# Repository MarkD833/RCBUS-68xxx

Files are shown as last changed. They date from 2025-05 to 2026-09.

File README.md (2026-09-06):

# RCBus Motorola 68xxx Project(s)

This repository is my attempt at introducing some of the Motorola MC68000 (and family) devices into the RCBus ecosystem. 

The image below is of my first RCBus-80 MC68000 system, comprising an MC68000 CPU board (RC101), ROM/RAM board (RC102) and quad serial board (RC103) all plugged into one of Steve Cousin's [SC701](https://smallcomputercentral.com/rcbus/sc700-series/sc701-rcbus-backplane/) backplanes.

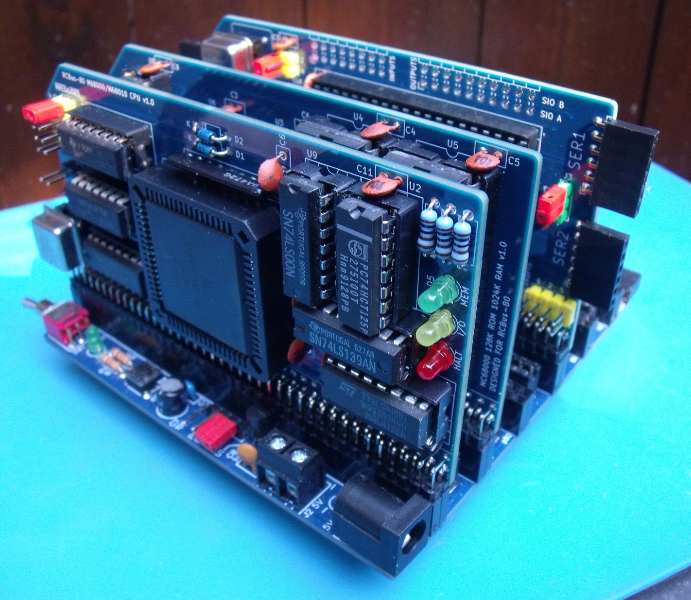
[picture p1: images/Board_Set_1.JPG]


**CAUTION:** This is my hobby project and I have no formal training in hardware design. What works for me may be simply down to the logic device series that I happen to have in my stash. There could be some real gotchas here that have yet to reveal themselves.

# Table of contents
- [The RCBus](#the-rcbus)
- [Zilog Compatability](#zilog-compatability)
- [DTACK](#dtack)
- [The Boards](#the-boards)
- [Address Map](#address-map)
- [RCBus Compatability](#rcbus-compatability)
- [Software Development](#software-development)
- [Hardware Library](#hardware-library)
- [Component Sourcing](#component-sourcing)

# The RCBus
RCBus is an extended version of the [RC2014&trade;](https://rc2014.co.uk/) bus that was put together by members of the [retro-comp](https://groups.google.com/g/retro-comp) google group. The latest RCBus specification as of Oct 2025 is v1.0 and can be found [here](https://smallcomputercentral.com/rcbus/).

My boards are designed around the RCBus 80 pin format in order to support the additional address and data signals to support the MC68000 family of devices.

# Zilog Compatability
There is no intention to support any Zilog family of chips such as the PIO, SIO, CTC or KIO as their signals and timing are just too different. The PIO and SIO have equivalents in the MC68230 and MC68681 chips. The KIO has a sort-of equivalent in the MC68901, but note that the single UART in the MC68901 is quite limited in terms of baud rate. A CTC chip may not be needed as the MC68230 and MC68681 each have a built-in timer and the MC68901 has 4 simple timers.

# DTACK
A common design choice when putting together a 68000 based system is to ground the /DTACK (Data Transfer Acknowledge) pin on the processor. With this design choice, there will not be a BUS ERROR exception.

Whilst this simplifies the design, I personally prefer to try and implement a simple /DTACK.

For my memory boards, I generate a /DTACK signal directly from the chip select signal and for the RCBus IO and Memory spaces I have a simple delay before generating a /DTACK on the processor card itself. Boards that use devices that are 68000 compatible (MC68681 or MC68230 for example) generate their own /DTACK internally. 

# The Boards
The boards below are my current suite of MC68xxx processors and peripherals. I have re-organised and re-named the boards in order to more easily identify them.

The board dimensions should be the size of an RCBus "medium" module as detailed in the RCBus specification v1.0 - roughly 4in x 2.1in excluding the edge connector. A lot of the boards are 4-layer boards with +5V and GND on the inner 2 layers, mainly in order to squeeze in all the chips into the small board space.

There are more details of each board in their respective boards folder.

There are currently 2 series of board. The series 1 boards I've give the names RC1xx to and the series 2 boards I've given the names RC2xx to.

## Series 1 Boards
These boards are based around my intial experimentation with an MC68000 ecosystem. The processor boards all use autovectored interrupts and the various I/O boards don't support any form of interrupt acknowledge sequence. These boards were a bit of a designing frenzy with not too much thought after I got carried away with Kicad and JLCPCB!

There are no programable logic devices (PALs, GALs, CPLDs etc) in my series 1 designs. The only programmable devices are the 2 EEPROMs containing my own simple monitor program and optionally CP/M-68K v1.3 and EhBASIC.

**NOTE:** The series 1 boards have been largly superseeded by the series 2 boards as my knowledge expanded.

| ID | Type | Description |
| :---- | :---- | :---- |
| RC101 | CPU | MC68000 CPU Board |
| RC102 | Memory | 128K ROM & 1M RAM Memory Board |
| RC103 | Serial | Dual MC68681 DUART Serial Board |
| RC104 | Parallel | Dual MC68230 PI/T Board |
| RC105 | Serial & Parallel | Dual MC68901 MFP Board |
| RC106 | CPU | MC68302 CPU Board |
| RC107 | Memory | 1M ROM & 1M RAM Memory Board |
| RC108 | SPI | Hybrid SPI Master Board<sup>*</sup> |
| RC109 | Serial & Parallel | MC68681 DUART & MC68901 MFP Board |
| RC110 | CPU | MC68020 CPU Board<sup>*</sup> |
| RC111 | Serial & Maths | MC68681 DUART & MC68881 Maths<sup>*</sup> |

<sup>*</sup> These boards are either under development or going through basic testing. Once I'm confident in the board operation, I will put the design files into the boards folder.

## Series 2 Boards
These boards are based on my expereince with the earlier series 1 boards and are an attempt to introduce vectored interrupts to the boards that use chips such as the MC68681 DUART or the MC68230 PIO. The introduction of vectored interrupts requires additional interrupt acknowledge signals on the RCBus-80 backplane. In order to not run out of pins, I have chosen to use IRQ2, IRQ3, IRQ5 and IRQ6 as vectored interrupts, leaving IRQ1, IRQ4 and IRQ7 as autovectored interrupts. 

Supporting vectored interrupts requires additional logic on the processor board which in turn requires additional board space which is in very short supply. My 68000 board currently under test appears to successfully handle vectored interrupts without the need for SMD package variants of the DIL chips or any CPLD device - although there is one bug that will hopefully be corrected with the next version of the board.

| ID | Type | Description |
| :---- | :---- | :---- |
| RC200 | 8-Slot RCBus Backplane | integrated CompactFlash, buttons & LED interfaces |
| RC201 | CPU | MC68000 CPU Board |
| RC202 | Serial | MC68681 DUART Serial Board (inc bit-bang SPI & I2C) |
| RC203 | Parallel | Dual MC68230 PI/T Board |
| RC204 | 1M ROM & 3M RAM board | fixed ROM & some SMD devices |
| RC205 | 68020 processor card | uses the PGA package |
| RC206 | 68008 processor card | using the PLCC package |
| RC207 | 1M ROM & 1M RAM board | manual BOOT ROM switching |
| RC208 | 1M ROM & 1M RAM board | automatic BOOT ROM switching |
| RC209 | 1M ROM & 3M RAM board | some SMD devices & automatic BOOT ROM switching |

Some of these boards are now working whilst others are on the desk waiting to be populated. For the working boards, there are all the details in their respective boards folder. For the boards under test, I've put some very basic details in their boards folder for now.

# Address Map
I'm trying to keep this global address map as up to date as I can. The current address map is as follows:

| Board | Board | Address Range | Notes |
| :---- | :---- | :---- | :---- |
| RC101 | 68000 CPU | MREQ: 0xF00000..0xF7FFFF<br>IORQ: 0xF80000..0xFFFFFF | Autovectored interrupts only |
| RC102 | 128K EEPROM & 1M RAM | ROM: 0x000000..0x0FFFFF<br>RAM: 0x100000..0x1FFFFF | See note #2 |
| RC103 | DUAL DUARTs | 0xD00000..0xD03FFF | Jumper selectable address range - See note #1 |
| RC104 | DUAL PI/Ts | 0xD08000..0xD0BFFF | Jumper selectable address range |
| RC105 | MFPs | 0xD10000..0xD13FFF | Jumper selectable address range |
| RC106 | 68302 CPU | MREQ: 0xFD0000..0xFDFFFF<br>IORQ: 0xFE0000..0xFEFFFF | Software programmable via /CS3 |
| RC107 | 1M FLASH & 1M RAM | 0x000000..0x5FFFFF | Jumper selectable 1Mb blocks - See note #2 |
| RC108 | Hybrid SPI | 0xD20000..0xD23FFF | |
| RC109 | DUART & MFP | 0xD00000..0xD03FFF | Jumper selectable address range - See note #1|
| RC110 | 68020 CPU | TBD | |
| RC111 | DUART & MATH | TBD | Jumper selectable address range - See note #1 |
| RC201 | 68000 CPU | MREQ: 0xF80000..0xF9FFFF<br>IORQ: 0xFA0000..0xFBFFFF | Supports vectored interrupts |
| RC202 | DUART | 0xD00000..0xD027FF | Jumper selectable address range - See note #1 |
| RC203 | DUAL PI/Ts | 0xD08000..0xD0BFFF | Jumper selectable address range |
| RC204 | 1M FLASH & 3M RAM | ROM: 0x000000..0x0FFFFF<br>RAM: 0x100000..0x3FFFFF | See note #2 |
| RC205 | 68020 CPU | TBD | |
| RC206 | 68008 CPU | TBD | |
| RC207 | 1M FLASH & 1M RAM | RAM: 0x000000..0x0FFFFF<br>ROM: 0x700000..0x7FFFFF | See note #3 |
| RC208 | 1M FLASH & 1M RAM | RAM: 0x000000..0x0FFFFF<br>ROM: 0x700000..0x7FFFFF | See note #4 |
| RC209 | 1M FLASH & 3M RAM | RAM: 0x000000..0x2FFFFF<br>ROM: 0x700000..0x7FFFFF | See note #4 |
| RC210 | 68302 CPU | MREQ: 0xFD0000..0xFDFFFF<br>IORQ: 0xFE0000..0xFEFFFF | Software programmable via /CS3<br>Supports vectored interrupts |

1. These boards share the same address range so that the same monitor code can be used with the MC68681 DUARTs on each of the boards.
2. RAM addresses 0x100000..0x1003FF hold the exception vector table.
3. ROM is at address 0x000000 until 1st write then RAM at 0x000000 and ROM at 0x700000.
4. ROM is at address 0x000000 until 4th /AS then RAM at 0x000000 and ROM at 0x700000.

Note: When using the MC68302 CPU board and a modified ROM/RAM board, the ROM devices will initially be mapped to address 0x000000 and selected with the chip select signal /CS0. The MC68302 can then remap /CS0 (and /CS1 for the RAM devices) to an alternate location in the address space. 

# RCBus Compatability
I have a number of Steve Cousin's RC2014&trade; / RCBus boards that I have been able to use successfully in the 68000 system. The code folder holds some example code for these boards as well as CP/M-68K v1.3 using the CompactFlash storage.

| Name | Description |
| :---- | :---- |
| [SC129](https://smallcomputercentral.com/rcbus/sc100-series/sc129-digital-i-o-rc2014/) | digital I/O module |
| [SC145](https://smallcomputercentral.com/rcbus/sc100-series/sc145-compact-flash-rc2014/) | CompactFlash module |
| [SC611](https://smallcomputercentral.com/rcbus/sc600-series/sc611-rcbus-micro-sd/) | MicroSD module |
| [SC704](https://smallcomputercentral.com/rcbus/sc700-series/sc704-rcbus-i2c-bus-master/) | I2C bus master module |
| [SC406](https://smallcomputercentral.com/i2c-bus-modules/sc406-i2c-temperature-sensor-module/) | I2C temperature sensor module |
| [SC705](https://smallcomputercentral.com/rcbus/sc700-series/sc705-rcbus-serial-acia/) | serial ACIA module |
| [SC729](https://smallcomputercentral.com/rcbus/sc700-series/sc729-rcbus-compact-flash-module/) | CompactFlash module |

The SC145 & SC729 CompactFlash modules have both been tested with CP/M-68K v1.3 and appear to operate correctly.

I've ported part of J B Langston's [TMS9918A code](https://github.com/jblang/TMS9918A/tree/master) to work with Shiela Dixon's [TMSEMU RCBus video card](https://peacockmedia.software/RC2014/TMSEMU/). There are now several demos working as I've slowly added more functionality to the TMS library. Some demos have also been ported from assembler to C along with modifications to the library to support C function calls.

I've also had success in porting some of Dean Netherton's [HDMI for RC](https://www.dinoboards.com.au/hdmi-for-rc) (V9958A) demonstration code. There are now several demos working as I've slowly explored his Tang Nano 20K FPGA emulation of a V9958A chip.

# Software Development
All of the early software - i.e. the monitor program - was developed and initially tested using EASy68K & SIM68K under Windows 10.

I moved my development across to a Linux Mint system for a few months but eventually the number of niggles became too much and I've now moved to a Windows 11 system.

I've left the command line version of the EASy68K assembler in another repository as that runs just fine from a Linux command prompt. I made a few tweaks and corrections and you can find it in a separate repository called EASy68K-asm.

Unfortunately I've had little success in building Newlib or similar libraries to create a libc for my system. This is purely down to my lack of experience / understanding of the configuration and build process. I've therefore resorted to rolling my own libc using the code detailed in [The Standard C Library by P.J.Plauger](https://www.amazon.co.uk/Standard-C-Library-P-J-Plauger/dp/0131315099) as a starting point. 

# Hardware Library
I'm not a C++ programmer so I figured I would try and learn about C++ and classes and decided to throw myself in at the deep end - the really deep end!

Having returned to the world of microcontrollers by playing around with some Arduino UNO boards, I figured that I might try and create some hardware libraries in the style of Arduino.

Currently I have a serial port library that provides similar functionality to some of the functions in the [Arduino Serial class](https://docs.arduino.cc/language-reference/en/functions/communication/serial/) that supports the dual MC68681 SIO board.

# Component Sourcing
Whilst many of the TTL logic devices are generally still available as NOS (New Old Stock), almost all the larger chips (CPUs, DUARTS etc) are now obsolete and can be difficult to locate. Here in the UK my sources are either [Silicon Ark](https://www.silicon-ark.co.uk/) or ebay.

I've also used AliExpress but a note of caution. It has been my experience that quite a few sellers on AliExpress are claiming that their chips are new devices. In reality these devices have most likely been reclaimed from old scrapped boards and have solder on their pins. My experience with these devices is that they do work as they should but the presence of the solder makes their pins 'sticky'. After several insertions and removals, either the IC socket breaks or a pin breaks off the device. For me, this was particually the case when using EEPROM or FLASH devices and going through the early burn and learn programming process.

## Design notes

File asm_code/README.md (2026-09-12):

# RCBUS MC68000 Software

This folder contains the assembler software that I've either developed myself or ported to my RCBus 68000 board(s).
The software can be assembled using EASy68K under Windows or EASy68K-asm under Linux (see my EASy68K-asm repository).

**Note:** With the introduction of the RC2xx series of boards and in particular the RC208 ROM/RAM board, these demonstration files will very likely not load or run as they expect the RAM to be at address 0x100000. The RC208 board maps RAM to address 0x000000 after boot. A simple change of the ORG locations should fix it.
 
There are also two s-record files containing MON68K v1.5, CP/M-68K v1.3 & EhBASIC v3.54. Note that these files are not compatible with the 68302 board.

The file MON68Kv1.5+CCP+BIOS+BASIC-38400.s68 uses a 38400 baud serial port and should be compatible with all MC68681 DUART variants.

The file MON68Kv1.5+CCP+BIOS+BASIC-115200.s68 uses a 115200 baud serial port and can be used with one of the Philips high speed DUART chips configured to run in the test mode.

**NOTE:** The MON68K monitor now uses the CTS signal to control the flow of data from the host PC. In order to use hardware flow control, the solder jumper JP2 on the rear of the SIO board needs to be bridged to allow the DUART OP0 signal to control the CTS signal. The serial receive routines are now interrupt driven and require the IRQ2 jumper to be fitted on the SIO board.

In order to use these files, you can either load one into your prom programmer and program the odd and even bytes into separate ROMs or you can load it into EASyBIN and generate a pair of binary files that your prom programmer can then program into separate ROMs.

| Code | Description |
| :---- | :---- |
| MON68K | My simple monitor program for the RCBus 68000. |
| MON302 | My simple monitor program for the RCBus 68302. |
| SC129 | SC129 digital i/o module. |
| SC611 | SC611 MicroSD module. |
| SC704 | SC704 I2C bus master module + SC406 temperature sensor module. |
| SC705 | SC705 serial ACIA module. |
| CP/M-68K v1.3 | Digital Research CP/M-68K v1.3 |
| EhBASIC v3.54 | Lee Davison’s EhBASIC for MC68000 |
| TMS9918A | Shiela Dixon's TMSEMU video module |
| MC68901 | MC68901 multi-function peripheral board |

Please see the individual folders for more details.

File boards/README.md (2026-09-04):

# RCBUS-68000-Boards

These folders contain the KiCad (v8/v9/v10) design files for the various RCBus 68000 boards I'm currently testing.

## Series 1 boards

The series 1 boards are my first attempt at a 68000 based RCBus-80 system. Processor boards support autovectored interrupts only.

**NOTE:** The series 1 boards have been largly superseeded by the series 2 boards as my knowledge expanded.

| ID | Description | Notes |
| :---- | :---- | :---- |
| RC101 | 68000 processor card using the PLCC package variant of the 68000 | Use RC201 for vectored interrupt support |
| RC102 | 128K ROM & 1M RAM board | Use RC208 instead |
| RC103 | Dual MC68681 serial board - 4 serial ports | Use RC202 (2 serial ports only) for vectored interrupt support |
| RC104 | Dual MC68230 parallel interface / timer board | Use RC203 for vectored interrupt support (timer only) |
| RC105 | Dual MC68901 multifunction peripheral board | |
| RC106 | 68302 processor card using the PGA package | |
| RC107 | 1M ROM & 1M RAM board | Use RC208 instead |
| RC108 | 6 channel SPI master board - 3V3 and 5V ports | |
| RC109 | Serial / parallel / timer board | |
| RC110 | 68020 processor card using the PGA package | |
| RC111 | SCC68692 DUART + MC68881 maths coprocessor | |

Note that the 68020 board is still very much at the prototype stage.

## Series 2 boards

The series 2 boards are based on my time spent with the series 1 boards and the hope is that the processor boards will feature a mixture of vectored and autovectored interrupts.

| ID | Description | Notes |
| :---- | :---- | :---- |
| RC200 | RCBus-80 Developers Backplane | |
| RC201 | 68000 processor card using the PLCC package variant of the 68000 | Supports vectored interrupts |
| RC202 | Single SCC68692 DUART + SPI & I2C board - 2 serial ports | |
| RC203 | Dual MC68230 parallel interface / timer board | |
| RC204 | 1M ROM & 3M RAM board | Untested but likely replaced with RC209 shortly |
| RC205 | 68020 processor card using the PGA package | |
| RC206 | 68008 processor card using the PLCC package variant of the 68008 | |
| RC207 | 1M ROM & 1M RAM board - manual BOOT ROM switching | Abandoned - use RC208 instead |
| RC208 | 1M ROM & 1M RAM board - automatic BOOT ROM switching | |
| RC209 | 1M ROM & 3M RAM board - automatic BOOT ROM switching | |

Several of the series 2 boards are now working and I've put details in their respectove folders whilst others are still very much at the prototype stage.

## Notes
Make sure to look at the readme files in each board folder as they will detail any errors and corrections I've noticed so far as well as any thoughts on future enhancements etc.

A minimal 68000 (or 68010) system would comprise of a 68000/68010 CPU board, ROM/RAM board and SIO board.

A minimal 68302 system would comprise of a 68302 CPU board and a ROM/RAM board.

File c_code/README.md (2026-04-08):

# RCBUS MC68000 Software

This folder contains the C software that I've either developed myself or ported to my RCBus 68000 board(s).
The source code was built using GCC68K v13.1.0.

I'm using Windows 11 and all my builds are done from the Windows CMD prompt. I use Notepad++ as my editor.

I'm still learning about the GCC compiler & assembler so there's likely to be some issues with this code that I'm not aware of yet.

The development environment I setup is documented in the Win-gcc-setup.md file in the root of the repository. You should have a read of this as it details how to create the crt0 runtime file as well as a simple library of C functions (libc) and a library of mathematical functions (libm).

**NOTE:** The crt0 and libc files are required for all example programs.

The `simple_hello` example is the first piece of code I created to test my setup of the GCC tools. It's also about the only piece of code with inline assembler that GCC didn't complain about!  
 
| Code | Description |
| :---- | :---- |
| [SC611](#SC611) | SC611 MicroSD module. |
| [SC704](#SC704) | SC704 I2C Bus Master module. |
| [TMS9918A](#TMS9918A) | Shiela Dixon's TMSEMU TMS9918A module. |
| [V9958A](#V9958A) | Dean Netherton's HDMI for RC module. |

---

## SC611
### SPI Read & Write
The code in the SC611_SPI_Read_Write folder provides a more user friendly version of the SC611 assembler code. The code attempts to write a text string to an external EEPROM connected to the SC611 SPI connector. It has been tested with a Microchip 25LC256 SPI EEPROM.

This is the first RCBus module I attempted to write high level code for and it includes some assembly language in the sc611.S file that handles the bit bang 8-bit and 16-bit transfers.

---

## SC704
### I2C Scan
The code in the SC704_I2C_Scan folder implements a simple program to scan each I2C address from 0x08 to 0x7F to see if a device is present at that address and prints out the device addresses found to be active.

### I2C Read & Write
The code in the SC704_I2C_Read folder demonstrates how to write and read back some data from the 25LC256 EEPROM on the SC704 board.

---

## TMS9918A
The demonstrations below are based on the demonstration code of the same name by JB Langston for his Z80 system but ported over to my 68000 based system.

### ASCII Character Set Demonstration
The code in the TMS9918A-ASCII-Chars folder is a C implementation of the same assembler demo. The TMS9918A assembler library has been modified so that the functions can be called directly from C.

### Sprite Demonstration
The code in the TMS9918A-Sprites folder is a C implementation of the same assembler demo - spinning globe - and the TMS9918A assembler library has been further modified to support the additional functions needed by the sprites demo.

### Nyan Cat Animation
The code in the TMS9918A-Nyan folder is a C implementation of the same assembler demo and demonstrates cycling through a sequence of frames of an animation.

### Fern (Pixel Plotting) Demonstration
The code in the TMS9918A-Fern folder is a 68K version of the fern demonstration and does 2048 plots before exiting.

---

## V9958A
The demonstrations below are based on the demonstration code of the same name by Dean Netherton for his [HDMI for RC](https://www.dinoboards.com.au/hdmi-for-rc) board based around a Tang Nano 20K FPGA module.

### Dots
The code in the V9958-Dots folder demonstrates plotting pixels. It's not quite the same as Deans original demo code as I have yet to implement a function to return pseudo-random numbers but it serves to demonstrate the plotting functionality.

### Lines
The code in the V9958-Lines folder demonstrates drawing lines. It's not quite the same as Deans original demo code as I have yet to implement a function to return pseudo-random numbers so it simply draws a rectangular box on the screen instead.

### Mbrot
The code in the V9958-Mbrot folder demonstrates the plotting of a mandelbrot set. With my 68000 running from a 7.3728MHz clock, it takes just over 14 minutes to plot.

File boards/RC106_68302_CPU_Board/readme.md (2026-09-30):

# 68302 Processor Board

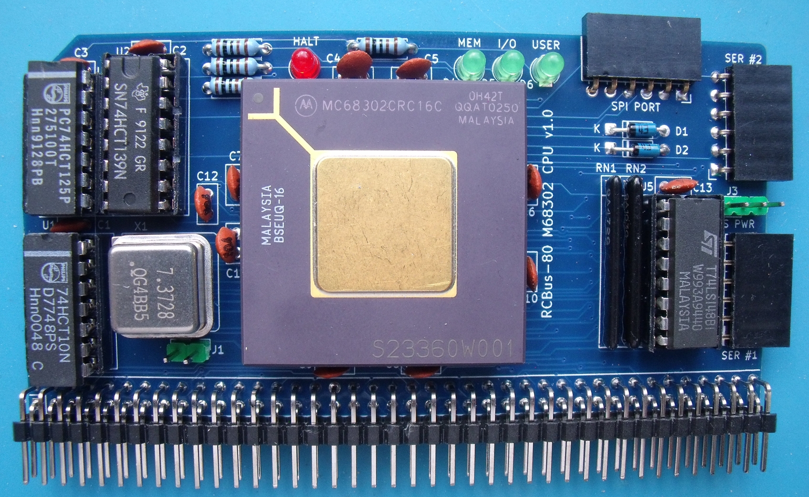
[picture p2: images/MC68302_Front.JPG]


# Details
The processor board consists of a PGA packaged MC68302 processor, bits of glue logic and the processor clock source.

The processor board is designed to plug into an RCBus-80 backplane and expects to find the stack pointer and initial program counter addresses at location 0x000000 onwards.

If using latest version of the MON302 that supports ROM & RAM remapping via software then the RC102 ROM/RAM board should not be used without some hardware modification.

## Reset
The reset signal for the processor board must be supplied externally, entering the board via pin 20 of the RCBus connector. This should not be an issue if you are using one of Steve Cousins's backplanes.

## Processor Clock
The processor/system clock source is an oscillator in an 8-pin DIL/DIP can (X1 in the schematic). I used a turned pin socket to hold the oscillator as it made it easy to quickly swap in and out oscillators of different frequencies. Basic testing was done with a 7.3728MHz oscillator.

A **note of caution** when using a socketed oscillator - there is the possibility that the metal can of the oscillator could accidentally short out pins on the next board. Please be aware of this.

The 68302 doesn't have an E clock signal like the 68000 does so I chose to have the option to route the output of Timer #1 to the RCBus CLOCK2 pin (61) via a jumper.

Note that the CLOCK2 pin may also be used by the serial, parallel and multifunction boards (via jumpers on their boards) to share a clock source between them - usually to feed the baud rate generators and timers. If this feature is used, then the CLOCK2 jumper must not be fitted.

## Chip Selects
The 68302 processor has 4 user programmable chip select signals - /CS0, /CS1, /CS2 & /CS3.

/CS0 is automatically configured by the processor at reset for an 8K block of memory starting at address $000000. /CS0 would normally be used to select a non-volatile memory device that holds the boot code. However there's a solder jumper (JP1) that can be used to route /CS0 to RCBus pin 45 if required.
+ RC102 ROM/RAM board includes address decoding to select the pair of ROMs at address $000000 so /CS0 isn't needed (must use older version of MON302)
+ RC107 ROM/RAM board supports external chip selects - see RC107 readme for more details
+ RC208 ROM/RAM board **MUST** set the ROM chip select to EXT

/CS1 is disabled by the processor at reset. I intended this chip select to select the volatile memory device on my RC107 ROM/RAM board. There's a solder jumper (JP2) that can be used to route /CS1 to RCBus pin 46 if required.
+ RC102 ROM/RAM board includes address decoding to select the pair of RAMs at address $100000 so /CS1 isn't needed (must use older version of MON302)
+ RC107 ROM/RAM board supports external chip selects - see RC107 readme for more details
+ RC208 ROM/RAM board **MUST** set the RAM chip select to EXT

/CS2 is disabled by the processor at reset. This chip select signal is used to enable access to the RCBus memory and i/o spaces. The /CS2 address decoding is configured for a 128K block of memory that is split into two 64K blocks by half of a 74LS139. Accessing the lower 64K block generates an /MREQ on the RCBus and accessing the upper 64K block generates an /IORQ on the RCBus.

**NOTE:** If using the newer version of MON302 that supports remapping of the ROM and RAM address spaces, then please see the relevant ROM/RAM board readme file for details on the hardware modifications needed to the ROM/RAM board to support this.

## DTACK & Bus Error
The user programmable chip select signals can also be configured to internally generate the DTACK signal so no external gates are required. My ROM/RAM board generates its own DTACK signal so DTACK is disabled for /CS0 & /CS1. /CS2 is configured to for 2 wait states.

The 68302 processor also includes an internal hardware watchdog that is enabled at reset and will generate a Bus Error if a DTACK isn't generated by the internal chip select logic or an external device.

## Serial Ports
Two of the 68302 serial ports - SCC1 & SCC2 - are fed to 6-pin connectors at the board edge. The layout of the 6 pins is compatible with an FTDI USB-TTL Serial interface board.

## SPI Port
The 68302 hardware SPI port (via SCC3 pins) is available on J6. Also on J6 is a chip select for the SPI device which is connected to port pin PB8 of the 68302.
 
## RCBus Signals
The RCBus specification (v1.0) doesn't specifically mention the 68000 in the backplane signal assignments table so there's a bit of wiggle room on the pins used.

I've stuck to the same signals for pins 1-40. The M1 signal isn't used and should have a 4K7 pullup resistor (manually added as I forgot it in my release 2.0 board!) and the USER1..USER4 which are used for the level 1, 3, 5 & 6 autovector interrupts.

Pins 41-80 carry D8..D15 as well as the higher address bits. Pins 41..44 have been used to carry some 68000 specific signals.

The current signal list is in the RCBus 68000 Pinout PDF file.

For the 68302 board, I have introduced 2 additional signals that can be routed onto the backplane to expose the /CS0 (pin 45) and /CS1 (pin 46) chip select signals. These are disconnected by default but can easily be connected by shorting solder jumpers JP1 (/CS0) and JP2 (/CS1) on the rear of the board.

The output of Timer #1 can be routed to the CLOCK2 pin to provide a clock source for other boards if required.

## RCBus memory space
The RCBus memory space is available via a 128K window in the 68302 address space. The hardware uses /CS2 to select this memory space with A16 determining either memory or I/O space as follows:
| Address Range | Signal |
| :---- | :---- |
| 0xFC0000..0xFCFFFF | /MREQ goes low |
| 0xFD0000..0xFDFFFF | /IORQ goes low |

This partial decoding results in the RCBus I/O memory space appearing multiple times within the 68000 address range. A DTACK signal is generated internally for any access to the RCBus whether there is a device present at that address or not.

For both I/O and memory spaces, consecutive memory locations are accessed on the ODD bytes such that I/O address 0x00 is accessed at address 0xFD0001, address 0x01 is accessed at address 0xFD0003 etc.

## Onboard LEDs
There are 4 LEDs on the board indicate accesses to the RCBus I/O and memory spaces as well as a HALT LED and a user LED (connected to port pin PB9).

## Power
The complete RCBus system can be powered from the 5V pin of one of the USB-TTL serial connectors by fitting a jumper in place on the appropriate pins of J3.

Note that there is a current limit of 500mA - imposed by the host system USB hardware - when the system is powered this way. It is relatively easy to exceed this limit once several boards are in use and I recommend that the system be powered from an external 5V supply connected to the RCBus backplane instead.

# Board Assembly
Assembly of the board should be fairly straightforward as there are no surface mount devices to deal with, but see the note below regarding the 68302 socket.

If you choose have a turned pin socket for the system clock, then an 8-pin DIL turned pin socket can be used. I flipped the socket over - pins pointing upwards - and easily pushed out pins 2,3,6 & 7.

A **note of caution** when using a socketed oscillator - there is the possibility that the metal can of the oscillator could accidentally short out pins on the next board. Please be aware of this.

When fitting the 80-pin right angle connector, initially only solder a couple of pins at opposite ends of the connector so that you can make any adjustments if the board is not vertical when fitted to the backplane.

# Note on the MC68302 socket
I could not get hold of the official PGA socket for the 68302 so I had to make my own from some SIL turned pin socket strips. From an earlier experiment I learnt that the plastic housing is slightly too wide so you can't simply butt together 13 SIL strips to make a socket. Instead I had to alternate between rows of pins in the plastic housing and rows of individual pins like this:



This makes it a bit of a pain trying to get all the individual pins to play ball and line up with the PCB holes but it does work.

**Note:** Be careful with this method as I later discovered that the SIL turned pin sockets were not the low insertion force type. Once soldered into the board, the combined resistance of 132 turned pin sockets is such that the processor can't be removed without breaking it. The only way to get the processor out safely is by destroying the board with a handy rotary tool by cutting out the piece of board holding the processor and then carefully cutting off the pins very close to the board. The processor should then come away and the remains of the turned pin sockets can be easily removed individually. 

# Software
I've written a very simple monitor program for the 68302 board whick can be found in the ASM_CODE folder - called MON302. The monitor was initially developed using EASy68K.

## Interrupts
As the ROM is currently fixed at address 0x000000, the exception vector table addresses are also fixed. Exception vectors up to and including TRAP #15 each call their own handler stub within the monitor ROM. The remaining exception vectors are all directed to a single handler as they are not used within my design - i.e. vectored interrupts are not supported, only autovectored interrupts.

Each exception handler stub in the ROM (apart from bus error, address error and TRAP #15) looks up the start address of the actual exception handler code in a table of addresses held in RAM (which is initialised by the montor program). The table is located at the start of RAM occupying addresses 0x100000..0x1003FF and is laid out just like a normal exception vector table.

In order to use your own exception handler, you simply over write the RAM exception vector table entry with the address of your own handler.

# Jumpers
+ J1: Fit jumper to route Timer #1 output onto RCBus CLOCK2 but only if CLOCK2 is **not** being used to share a clock between the SIO, PIO and MFP boards.
+ J3: External 5V supply for the system
  + 1-2 : Power the system from the USB-TTL Serial board on Serial #1
  + 2-3 : Power the system from the USB-TTL Serial board on Serial #2
+ J4: Serial #1 port from SCC1
+ J5: Serial #2 port from SCC2
+ J6: SPI port

# Solder Jumpers
The 2 solder jumpers are located on the rear of the board and are used to route the 68302 /CS0 and /CS1 chip select signals onto the RCBus. With these jumpers soldered and a simple modification to the ROM/RAM board, the 68302 can boot from ROM at address $0000 and then swap the ROM and RAM so that RAM is located at address $0000.

+ JP1: solder this jumper to connect /CS0 to RCBus pin 45.
+ JP2: solder this jumper to connect /CS1 to RCBus pin 46.

# Errors
A fundamental flaw in the way interrupts are handled has come to light. This appears to only affect interrupts generated internally by the 68302 such as serial port or timer interrupts. It seems that when the 68302 generates its own interrupt - when an SCC receive buffer is full for example - it exposes this interrupt to the outside world by setting its FC0, FC1 & FC2 bits to a 7. This causes the current external logic to drive the /AVEC pin and create a level 4 autovectored interrupt rather than a level 4 vectored interrupt. All 68302 internally generated interrupts are level 4.

# Thoughts / Enhancements
+ Should I have used SCC1 for the monitor port?
  + CTS1 is in input to SCC1 that can be used to tell SCC1 to stop transmitting.
  + RTS1 is an output from SCC1 and is asserted when SCC1 Tx buffer has data to send.
  + Don't appear to have software control over these pins to be able to tell the host PC to stop transmitting data to SCC1.
+ SCC2 provides software control of RTS2 (Port pin PA5) and CTS2 (Port pin PA4). Therefore can tell host PC to stop transmitting via software if our Rx buffers fill up.
+ SCC3 has no handshaking as the pins are used for the SPI interface.
+ For 115200 baud with RTS/CTS handshaking for quick xfer of srec files then it looks like SCC2 would be the better choice.

# To Do
+ Experiment to find the maximum width of board that JLCPCB will accept to keep the low price.
+ Modify the RCBus80 medium board footprint in Kicad so that pins 1,40,41 & 80 don't throw DRC warnings/errors.

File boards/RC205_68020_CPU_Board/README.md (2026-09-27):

# 68020 Processor Board

There's now some real hardware!

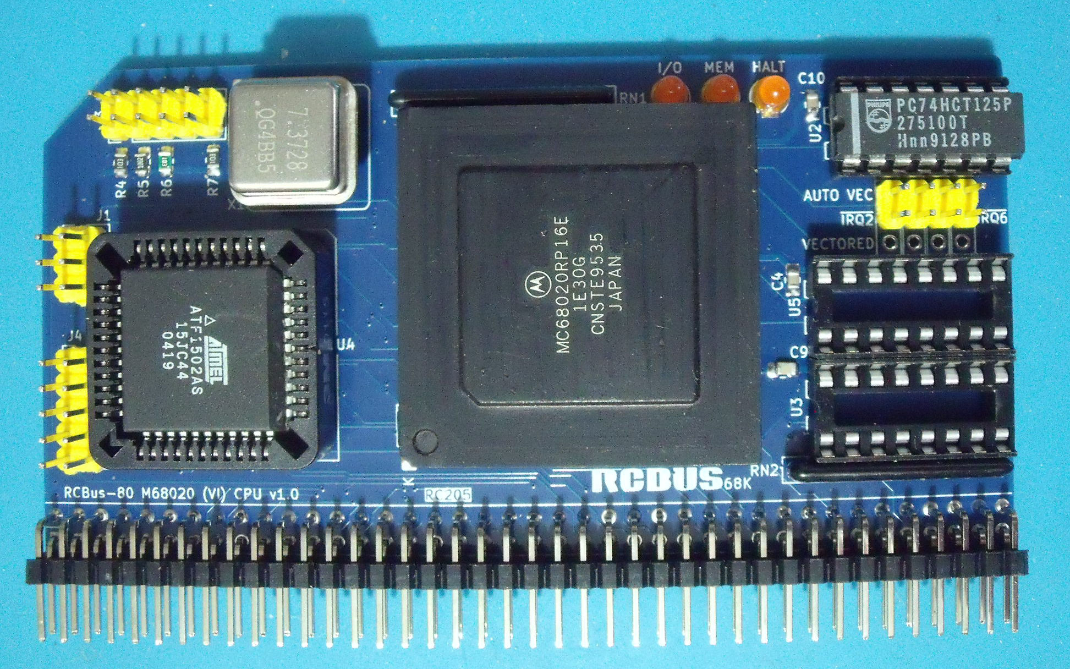
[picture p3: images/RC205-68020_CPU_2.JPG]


# Details
This is my attempt at getting a 68020 processor running on RCBus. There's going to be some challenges along the way as I've not used a 68020 before. I'm also 30 years late to the CPLD world so a bit of catching up to do.

The board is built and basic operation, although not entirely successful, is showing signs that I'm on the right track. The monitor program spits out a few characters but then the board crashes so some debugging with my recently acquired [GusmanB 24 channel logic analyser](https://github.com/gusmanb/logicanalyzer/tree/master) is required to figure out what I may have done wrong. However, I suspect that it's a timing problem.

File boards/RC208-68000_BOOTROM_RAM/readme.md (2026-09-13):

# 1M BOOT ROM & 1M RAM board - v1.1

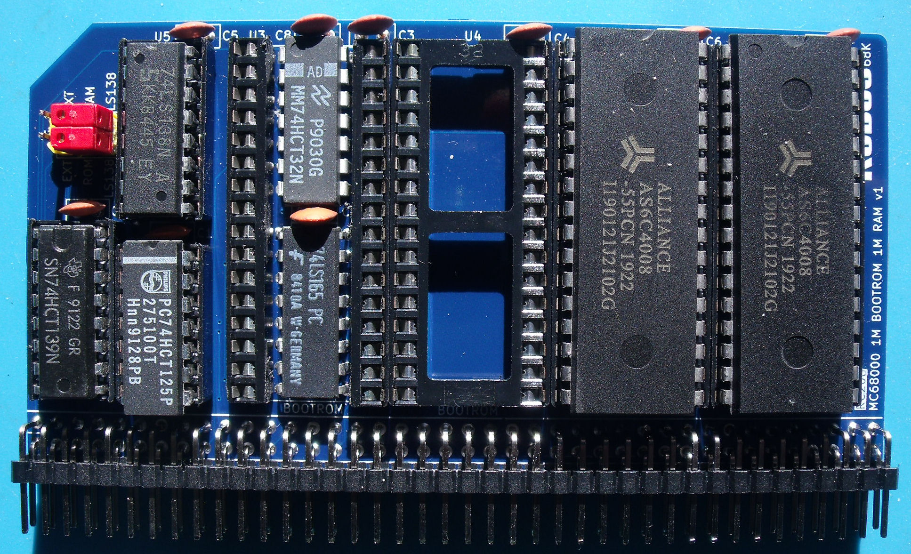
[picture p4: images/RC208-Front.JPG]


The old v1.0 board with the flash chips removed.

# Details
This is my RC208 BOOT ROM & RAM board and it is designed to plug into an RCBus-80 backplane with support for 1M ROM (via 2x SST39SF040 FLASH chips) and 1M RAM (via 2x Alliance Memory AS6C4008 SRAMs). The FLASH chips and SRAMs are used as a pair to allow 16-bit wide memory accesses.

This board is an enhanced version of my earlier RC107 board. This board presents the flash memory at address 0x000000 at reset and disables access to the RAM. After 4 address strobes, the flash memory is automatically moved up to address 0x700000 and the RAM becomes available at address 0x000000.

## Address Decoding
The address decoding is carried out by a 74LS138 that divides the lower 8Mb of memory space into eight 1Mb blocks.

After reset, the 74LS165 sets its Q7 output to a '1'. This '1' is then OR'd with address lines A20, A21 and A22 using 3 OR gates of the 74LS32 forcing their outputs to be a '1'. The outputs of the 3 OR gates are then fed into the A0, A1 and A2 inputs of the 74LS138 which forces output O7 of the 74LS138 low selecting the ROMs.

**68000**: After 4 address strobes, the 68000 has read the initial stack pointer and initial program counter from the ROMs and Q7 of the 74LS165 goes to a '0' allowing the outputs of the 3 OR gates to follow the logic levels on A20, A21 and A22. The 74LS138 then selects the RAM for any address between 0x000000..0x0FFFFF and the ROM for any address between 0x700000..0x7FFFFF.

**68008**: After 8 address strobes, the 68008 has read the initial stack pointer and initial program counter from the ROMs and Q7 of the 74LS165 goes to a '0' allowing the outputs of the 3 OR gates to follow the logic levels on A20, A21 and A22. The 74LS138 then selects the RAM for any address between 0x000000..0x0FFFFF and the ROM for any address between 0x700000..0x7FFFFF.

**Note:** If this board is used with an MC68302 processor, then see the note further down regarding the ability to externally remap the ROM & RAM devices.

## Bus Width 
A 74LS139 generates the read and write signals for each of the memory chips and takes care of byte or word accesses.

## DTACK
A 74LS125 is used to generate a simple /DTACK signal driven directly from the EEPROM and SRAM chip select signals without any wait period.

# Board Assembly
Assembly of the board should be fairly straightforward as there are no surface mount devices to deal with. All ICs are socketed except the 74LS32 and the 74LS165 which are soldered directly into the board.

The only tricky bit is the cutting of one of the 32-pin DIL sockets to remove the horizontal spacers.

When fitting the 80-pin right angle connector, initially only solder a couple of pins at opposite ends of the connector so that you can make any adjustments if the board is not vertical when fitted to the backplane.

Note the ROMs must be fitted to U3 and U4 in order for the processor to boot correctly.

Finally, set JP1 and J2 for your specific configuration (see below).

# MC68302 ROM & RAM Remapping

If the version of my MC68302 monitor is used that can remap the /CS0 and /CS1 chip select signals, then U1 (74LS125), U5 (74LS138), U8 (74LS165) and U9 (74LS32) are not required but can be fitted if the board is also going to be used with a 68000 or 68010 processor later.

**WARNING** When using a 68302 processor you must set J2 so that both ROM & RAM jumpers are set to EXT so that the chip selects are controlled by the 68302. Leaving them in the LS138 position will most likely result in the processor entering the HALT state.

# Jumpers
+ J1 - Chip Selects
  + On board chip selects: jumper ROM-LS138 & RAM-LS138
  + External Chip Selects: jumper ROM-EXT & RAM-EXT
+ JP1 - /AS counter
  + 68000/68010: Solder pads 2-3
  + 68008: Solder pads 1-2

# Errors
None so far.

# History
+ v1.1 - rear silkscreen correction for JP1
+ v1.0 - initial design

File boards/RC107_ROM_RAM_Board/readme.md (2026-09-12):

# ROM & RAM board - V2 - 1M ROM + 1M RAM

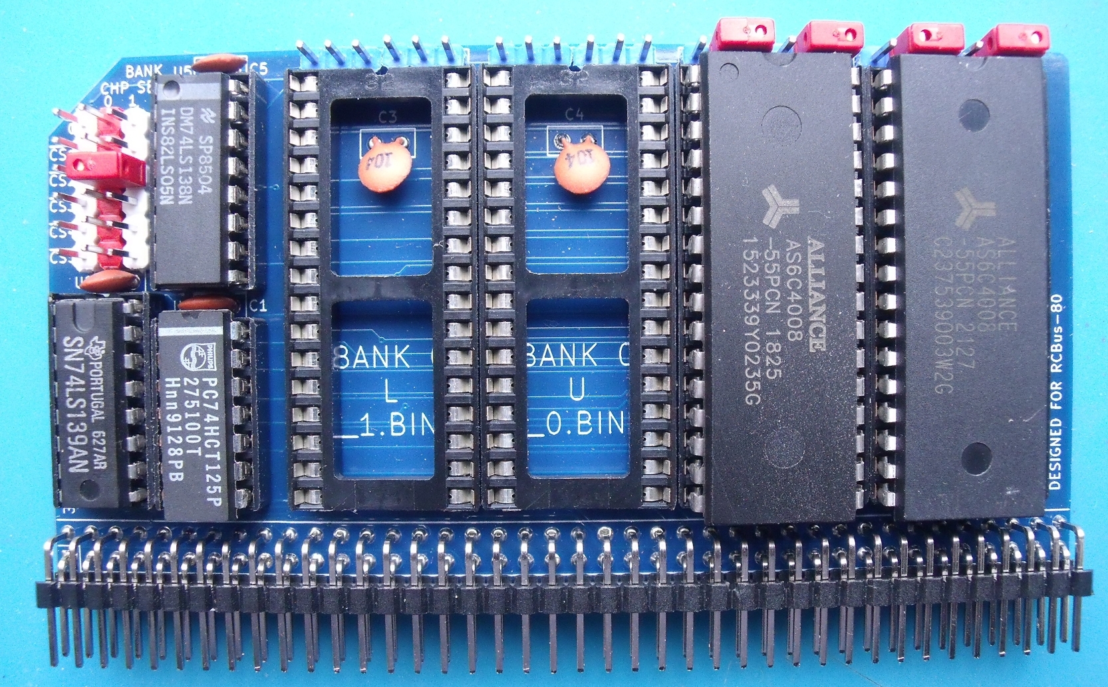
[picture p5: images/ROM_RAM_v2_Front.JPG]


# Details
The ROM & RAM board is designed to plug into an RCBus-80 backplane with support for 1M ROM (via 2x SST39SF040 FLASH chips) and 1M RAM (via 2x Alliance Memory AS6C4008 SRAMs). The FLASH chips and SRAMs are used as a pair to allow 16-bit wide memory accesses.

## Address Decoding
The address decoding is carried out by a 74LS138 and divides the lower 8Mb of memory space into eight 1Mb blocks. Each pair of chips can be assigned to any of the 8 chip selects - but not both pairs to the same chip select.

**Note:** If this is the only memory board in the 68000 system, then a pair of FLASH chips should be assigned to /CS0 so that the 68000 finds the stack pointer and program counter on boot.

**Note:** If this board is used with an MC68302 processor, then see the note further down regarding the ability to remap the ROM & RAM devices.

## Bus Width 
A 74LS139 generates the read and write signals for each of the memory chips and takes care of byte or word accesses.

## DTACK
A 74LS125 is used to generate a simple /DTACK signal driven directly from the EEPROM and SRAM chip select signals without any wait period.

# Board Assembly
Assembly of the board should be fairly straightforward as there are no surface mount devices to deal with.

Note the location of the decoupling capacitors for the memory devices are located within the IC sockets. THese decoupling capacitors should be bent over so that they do not interfere with the insertion of the memory chips.
 
When fitting the 80-pin right angle connector, initially only solder a couple of pins at opposite ends of the connector so that you can make any adjustments if the board is not vertical when fitted to the backplane.

Do not mix ROM & RAM chips in the same bank.

# Memory Bank Configuration
The pinout of the 32-pin FLASH and SRAM chips are slightly different and in order to accommodate both types, a pair of jumpers need to be set per chip. J6,J7,J8 & J9 set the memory type fitted to memory bank #0 and J2,J3,J4 & J5 set the memory type fitted to memory bank #1.

# Jumpers
+ FLASH ROM chips installed in Bank #1
  + J2: Jumper pins 1-2
  + J3: Jumper pins 2-3
  + J4: Jumper pins 1-2
  + J5: Jumper pins 2-3
+ RAM chips installed in Bank #1
  + J2: Jumper pins 2-3
  + J3: Jumper pins 1-2
  + J4: Jumper pins 2-3
  + J5: Jumper pins 1-2
+ FLASH ROM chips installed in Bank #0
  + J6: Jumper pins 2-3
  + J7: Jumper pins 1-2
  + J8: Jumper pins 2-3
  + J9: Jumper pins 1-2
+ RAM chips installed in Bank #0
  + J6: Jumper pins 1-2
  + J7: Jumper pins 2-3
  + J8: Jumper pins 1-2
  + J9: Jumper pins 2-3
+ J10: Memory Address selection
  + $000000 .. $0FFFFF
  + $100000 .. $1FFFFF
  + $200000 .. $2FFFFF
  + $300000 .. $3FFFFF
  + $400000 .. $4FFFFF
  + $500000 .. $5FFFFF
+ J11 (with J10): Specify the memory address for bank #0
+ J12 (with J10): Specify the memory address for bank #1
+ JP1: Solder link to connect RCBus /CS_ROM to /CS_BANK0 (Bank 0 must have FLASH memory fitted).
+ JP2: Solder link to connect RCBus /CS_RAM to /CS_BANK1 (Bank 1 must have SRAM memory fitted).

# MC68302 ROM & RAM Remapping

If the version of the MC68302 monitor is used that makes use of remapping the chip select signals, then the following hardware changes are required to this board:
  + U1 (74LS125) should be removed as the 68302 is configured to generate the /DTACK signals for /CS0 and /CS1 itself
  + U5 (74LS138) should be removed as the 68302 is configured to generate the chip select signals itself
  + Solder links JP1 and JP2 on the rear of the board must be made.
  
# Errors
Nothing yet - but give it time :-(

# History
+ v2.0 - corrected missing /CS signals, fixed J4 & J5 pitch, added 10K pullups to /CS lines
+ v1.0 - initial designed

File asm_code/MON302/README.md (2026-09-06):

# RCBUS MC68302 Simple Monitor

This folder contains the simple monitor program I created to support my RCBus 68302 system. The 68302 monitor uses the internal Serial Comms Controllers (SCCs) and is not compatible with my 68000 board although the same commands have been implemented.

I wanted a simple monitor that supported a few basic commands. This monitor was originally written for my 68008 board and then modified for my 68302 board before being modified again to support my RCBus 68302 board. None of the commands support any use of cursor keys or the backspace/delete keys.

The monitor operates at 38400 baud without any handshaking via SCC1.

There are now two versions of the monitor program.

## The original monitor (rcMON68302_v0.2) 
This is my original version of the monitor and it supports both CP/M-68K and EhBASIC which are separate applications that need to be programmed into the ROMs. The ROMs are mapped starting at address 0x000000.

### Memory Usage
The monitor uses the first 1K of RAM (0x100000..0x1003FF) to hold the exception vector table. When developing code, make sure that you do not overwrite it with any of your s-records. If you use a specific exception, then it is better to insert the exception handler address via software.

The monitor also uses a few Kb up at the top of RAM for its own purposes.

## The ROM/RAM swapping monitor (rcMON68302_sw_v1.0)
This version of the monitor utilises the MC68302 chip select hardware and signals /CS0 and /CS1. /CS0 selects the ROM chips and /CS1 selects the RAM chips.

Note that CP/M-68K and EhBASIC have been dropped from this version of the monitor.

The monitor has been tested with a modified ROM/RAM v2 board. This version of MON302 will boot with ROM at address 0x000000. It will then map the RAM starting at address 0x000000 and move the ROM up to address 0x600000.

In order to use this version of the monitor, a few hardware changes need to be made to the ROM/RAM v2 as follows:
  + U1 (74LS125) should be removed as the 68302 is configured to generate the /DTACK signals for /CS0 and /CS1 itself
  + U5 (74LS138) should be removed as the 68302 is configured to generate the chip select signals itself
  + A wire link inserted between pin J1-45 and any pin on J11 - this is /CS0 for the ROMs
  + A wire link inserted between pin J1-46 and any pin on J12 - this is /CS1 for the RAMs

Although not tested, this version of the monitor should also work with the original ROM/RAM board with the following changes:
  + U1 (74LS125) should be removed as the 68302 is configured to generate the /DTACK signals for /CS0 and /CS1 itself
  + U5 (74LS138) should be removed as the 68302 is configured to generate the chip select signals itself
  + A wire link inserted between pin J2-45 and pin U8-15 - this is /CS0 for the ROMs
  + A wire link inserted between pin J2-46 and pin U8-14 - this is /CS1 for the RAMs
  
### Memory Usage
The monitor uses the first 1K of RAM (0x000000..0x0003FF) to hold the exception vector table. When developing code, make sure that you do not overwrite it with any of your s-records. If you use a specific exception, then it is better to insert the exception handler address via software.

The monitor also uses a few Kb up at the top of RAM for its own purposes.

# Commands
There a few basic commands that the monitor understands as follows:

## B (v0.2 only)

Boots the embedded EhBASIC v3.54 from the ROM. It will check that EhBASIC is programmed into the ROM first. I need to provide a write-up on how to include EhBASIC and/or a ROM image that already includes it.

## C (v0.2 only)

Boots the embedded CP/M-68K v1.3 from the ROM. It will check that CP/M and the BIOS are programmed into the ROM first. I need to provide a write-up on how to include CP/M-68K and/or a ROM image that already includes it.

The CP/M68K v1.3 BIOS uses Steve Cousin's SC145 (or SC729) CompactFlash module to provide disk drives for CP/M. Please see the readme in the CP/M-68K code folder for more details.
 
## Dnnnn

Displays a block of 256 bytes starting at address nnnn. The address is in hexadecimal and can be any address from 0x00000000 to 0xFFFFFFFF. Any printable ASCII characters are also displayed to aid in showing text strings etc.

The command doesn't support going forwards or backwards in 256 byte pages or any other variations. To display the next 256 bytes, issue another D command.

## Gnnnn

Executes the code starting at address nnnn. The address is in hexadecimal and can be any address from 0x00000000 to 0xFFFFFFFF.

If the user code does return to the monitor, then a message is displayed to show that this has happened. No registers are saved prior to executing the user code and correct operation of the monitor is not guaranteed.

## Iaa

Displays the 8-bit value at address aa in IO space. Address aa is an address between 0x00 and 0xFF. This command will activate the /IORQ signal on the RCBus. Similar to the Z80 IN instruction.

The monitor takes care of the mapping of the requested address into 68000 memory space.

## Mnnnn

Modifies a byte of memory starting at address nnnn. The address is in hexadecimal and can be any address from 0x00000000 to 0xFFFFFFFF.

Once the byte has been entered, the next address is displayed to enable alteration of that address.

The command doesn't support going forwards or backwards or editing memory as 16-bit words or 32-bit long words.

## Oaabb

Writes the 8-bit value bb to address aa in IO space. Both the address and the value are 8-bit hexadecimal numbers between 0x00 and 0xFF. This command will activate the /IORQ signal on the RCBus. Similar to the Z80 OUT instruction.

The monitor takes care of the mapping of the requested address into 68000 memory space.

## S1 / S2

These commands are not entered directly by the user. They are detected by the monitor when Motorola S-records are transferred via a serial terminal program such as RealTerm. Each S-record is treated individually and is written to memory as it is received.

There is no need to initiate a download from the monitor by entering a command as the monitor will detect any lines beginning with an S and try and interpret them as Motorola S-records.
 
As user memory starts at address 0x100000 on my RCBus 68000, all S-records will be S2 records.

## ?

Simply displays the list of available commands that the monitor supports.

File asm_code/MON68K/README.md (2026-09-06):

# RCBUS MC68000 Simple Monitor

This folder contains the simple monitor program I created to support my RCBus 6800 system. The 68000 monitor uses the SIO board for its serial comms and is not compatible with my 68302 board although the same commands have been implemented.

Look in the asm_code folder for pre-configured s-record files containing CP/M-68K, EhBASIC and MON68K.

# Serial Communications
The monitor assumes that there is an MC68681 (or compatible) DUART present at address $D00000. The baud rate is determined by the setting of HI_SPEED in the MON68K source code.
+ Setting HI_SPEED = 0 puts the DUART into normal operation mode and 38400 baud. 
+ Setting HI_SPEED = 1 puts the DUART into a test mode where 115200 baud is achieved.

**Note:** 115200 baud can only be achieved when using a DUART that supports the test mode - i.e. one of the Philips devices.

The monitor uses RTS/CTS flow control to control the flow of data from the host PC. In order to use hardware flow control, the solder jumper JP2 on the rear of the SIO board needs to be bridged to allow the DUART OP0 signal to control the CTS signal.

**Note:** The serial receive routines are now interrupt driven and require the IRQ2 jumper to be fitted on the SIO board.

# Memory Usage
The monitor uses the first 1K of RAM (0x100000..0x1003FF) to hold the exception vector table. When developing code, make sure that you do not overwrite it with any of your s-records. If you use a specific exception, then it is better to insert the exception handler address via software.

The monitor also uses a few Kb up at the top of RAM for its own purposes.

# Commands
I wanted a simple monitor that supported a few basic commands. None of the commands support any use of cursor keys or the backspace/delete keys.

Th basic commands that the monitor understands are as follows:

## B

Boots the embedded EhBASIC v3.54 from the ROM. It will check that EhBASIC is programmed into the ROM first. I need to provide a write-up on how to include EhBASIC and/or a ROM image that already includes it.

## C

Boots the embedded CP/M-68K v1.3 from the ROM. It will check that CP/M and the BIOS are programmed into the ROM first. I need to provide a write-up on how to include CP/M-68K and/or a ROM image that already includes it.

The CP/M68K v1.3 BIOS uses Steve Cousin's SC145 (or SC729) CompactFlash module to provide disk drives for CP/M. Please see the readme in the CP/M-68K code folder for more details.
 
## Dnnnn

Displays a block of 256 bytes starting at address nnnn. The address is in hexadecimal and can be any address from 0x00000000 to 0xFFFFFFFF. Any printable ASCII characters are also displayed to aid in showing text strings etc.

The command doesn't support going forwards or backwards in 256 byte pages or any other variations. To display the next 256 bytes, issue another D command.

## Gnnnn

Executes the code starting at address nnnn. The address is in hexadecimal and can be any address from 0x00000000 to 0xFFFFFFFF.

If the user code does return to the monitor, then a message is displayed to show that this has happened. No registers are saved prior to executing the user code and correct operation of the monitor is not guaranteed.

## Iaa

Displays the 8-bit value at address aa in IO space. Address aa is an address between 0x00 and 0xFF. This command will activate the /IORQ signal on the RCBus. Similar to the Z80 IN instruction.

The monitor takes care of the mapping of the requested address into 68000 memory space.

## Mnnnn

Modifies a byte of memory starting at address nnnn. The address is in hexadecimal and can be any address from 0x00000000 to 0xFFFFFFFF.

Once the byte has been entered, the next address is displayed to enable alteration of that address.

The command doesn't support going forwards or backwards or editing memory as 16-bit words or 32-bit long words.

## Oaabb

Writes the 8-bit value bb to address aa in IO space. Both the address and the value are 8-bit hexadecimal numbers between 0x00 and 0xFF. This command will activate the /IORQ signal on the RCBus. Similar to the Z80 OUT instruction.

The monitor takes care of the mapping of the requested address into 68000 memory space.

## S1 / S2

These commands are not entered directly by the user. They are detected by the monitor when Motorola S-records are transferred via a serial terminal program such as RealTerm. Each S-record is treated individually and is written to memory as it is received.

There is no need to initiate a download from the monitor by entering a command as the monitor will detect any lines beginning with an S and try and interpret them as Motorola S-records.
 
As user memory starts at address 0x100000 on my RCBus 68000, all S-records will be S2 records.

## ?

Simply displays the list of available commands that the monitor supports.

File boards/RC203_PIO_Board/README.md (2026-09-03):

# RC203 - 68230 Parallel I/O Board

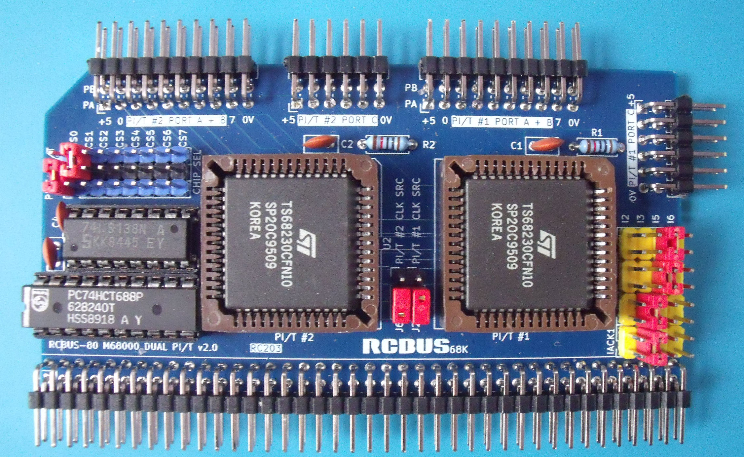
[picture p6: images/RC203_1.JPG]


# Details
The parallel board is populated with two 68230 Parallel Interface / Timer chips. Both PI/T chips do not have to be fitted. The board will work with just one chip fitted.

## Address Decoding
The address decoding is carried out by a 74LS688 combined with a 74LS138 to generate 8 separate 2048 byte blocks residing between addresses $D08000 and $D0BFFF.

The base address of each PI/T is determined by the placement of a jumper between adjacent pins on J7 & J12 (PI/T A) and J7 & J13 (PI/T B).

## Device Register Access
The registers of the PI/T are 8 bits wide and are accessed on consecutive ODD addresses from the base address set by the address decode logic. Assuming that the /CS0 jumper has been fitted for PI/T #1, then the first few registers are accessed on the following addresses:
+ $D08001 : Port General Control Register
+ $D08003 : Port Service Request Register
+ $D08005 : Port A Data Direction Register

## DTACK
Each PI/T generates its own /DTACK signal internally which is then routed back to the processor via RCBus-80 pin 62.

**NOTE** A PI/T must have a clock present - either from the main clock source (RCBus pin 21) or the alternate CLOCK2 source (RCBus pin 61) - in order to function. The clock source for PI/T #1 is determined by the jumper position on J2 and the clock source for PI/T #2 is determined by the jumper position on J6.

**Without a clock source, the PI/T will not respond (i.e. generate a /DTACK) and a BUS ERROR will be raised by the processor card.**

When using a main processor clock source above 7.3728MHz, check your PI/T datasheet to ensure that you do not exceed the limits of the CLK pin. If the main processor clock exceeds the specs for the CLK pin, then switch to using CLOCK2 as the source and set J2 and J6 appropriately. Also remember to set J5 on the RC202 SIO board to share its clock on CLOCK2.

## Interrupts
The board design supports autovectored interrupt generation by each PI/T at levels 2,3,5 or 6 depending on the placement of a jumper on J8 (PI/T #1) or J10 (PI/T #2). The RC201 processor card must also be configured to support autovectored interrupts at the same interrupt level.

The board also supports vectored interrupts at levels 2,3,5 & 6 depending on the placement of a jumper on J8 (PI/T #1) or J10 (PI/T #2). When using vectored interrupts, the same interrupt level must be set on both J8 and J9 (for PI/T #1) and J10 and J11 (for PI/T #2). The RC201 processor card must also be configured to support vectored interrupts at the same interrupt level.

## Input / Output Pins
The 8-bit ports A & B on each PI/T are routed to connectors along the top of the board. PI/T #1 port A and port B are present on the J1 connector along with +5V and GND. PI/T #2 port A and port B are present on the J4 connector along with +5V and GND.

The 8-bit port C on each PI/T is also routed to connectors along the top of the board. PI/T #1 port C is present on the J5 connector along with +5V and GND. PI/T #2 port C is present on the J15 connector along with +5V and GND.

Note that the board **does not have** any protection built in to prevent damage to the PI/T chips if one of these pins is mis-used.

# Board Assembly
Assembly of the board should be fairly straightforward. There are no surface mount devices to deal with.

When fitting the 80-pin right angle connector, initially only solder a couple of pins at opposite ends of the connector so that you can make any adjustments if the board is not vertical when fitted to the backplane.

# Jumpers
+ J1: PI/T #1 ports A & B plus +5V and GND
+ J2: Select RCBus CLOCK or CLOCK2 for PI/T #1 clock source - see notes above re /DTACK
+ J4: PI/T #2 ports A & B plus +5V and GND
+ J5: PI/T #1 port C plus +5V and GND
+ J6: Select RCBus CLOCK or CLOCK2 for PI/T #2 clock source - see notes above re /DTACK
+ J7: IO Address selection
  + $D08000
  + $D08800
  + $D09000
  + $D09800
  + $D0A000
  + $D0A800
  + $D0B000
  + $D0B800
+ J8: Select the interrupt level - 2,3,5 or 6 - for PI/T #1 timer interrupt
+ J9: Select the interrupt acknowledge level for PI/T #1 - used with vectored interrupts only and should match the level on J8 when used
+ J10: Select the interrupt level - 2,3,5 or 6 - for PI/T #2 timer interrupt
+ J11: Select the interrupt acknowledge level for PI/T #2 - used with vectored interrupts only and should match the level on J10 when used
+ J12: (with J7): Specify the IO Address for PI/T #1
+ J13: (with J7): Specify the IO Address for PI/T #2
+ J15: PI/T #2 port C plus +5V and GND

# Future Enhancements
Nothing yet.

# Errors
Nothing yet - but give it time :-(

# History
+ v1.0 - initial design

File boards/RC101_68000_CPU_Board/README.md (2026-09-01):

# 68000 Processor Board

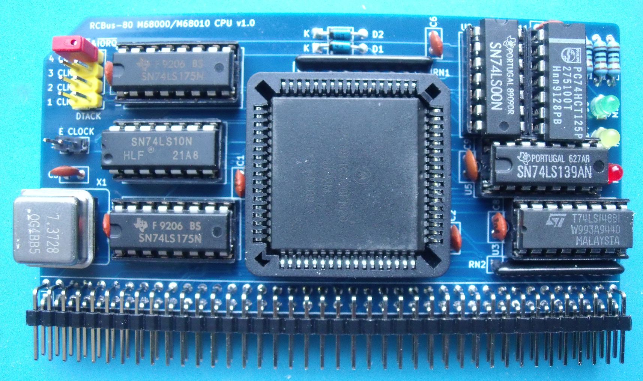
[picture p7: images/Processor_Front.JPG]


# Details
The processor board consists of a PLCC packaged MC68000 processor, bits of glue logic and the processor clock source. A 68010 processor can also be used but the current monitor program doesn't make use of the vector base register at the moment.

The processor board is designed to plug into an RCBus-80 backplane and expects to find the stack pointer and initial program counter addresses at location 0x000000 onwards. There is no fancy ROM & RAM switching hardware so ROM is always located at address 0x000000.

## Reset
The reset signal for the processor board must be supplied externally, entering the board via pin 20 of the RCBus connector. This should not be an issue if you are using one of Steve Cousins's backplanes.

## Processor Clock
The processor/system clock source is an oscillator in an 8-pin DIL/DIP can (X1 in the schematic). I used a turned pin socket to hold the oscillator as it made it easy to quickly swap in and out oscillators of different frequencies. Basic testing was done with a 7.3728MHz oscillator. An 18.432MHz oscillator was also tried and CP/M-68K appeared to work correctly with no issues accessing the CompactFlash drive. 

A **note of caution** when using a socketed oscillator - there is the possibility that the metal can of the oscillator could accidentally short out pins on the next board. Please be aware of this.
 
There's also a jumper (J4) to allow the processor E clock to be routed onto the RCBus CLOCK2 pin (61) if required. However, note that the CLOCK2 pin may also be used by the serial, parallel and multifunction boards (via jumpers on their boards) to share a clock source between them - usually to feed the baud rate generators and timers. If this feature is used, then the E clock jumper **must not** be fitted.

## DTACK & Bus Error
The processor board includes a counter to generate a bus error if a /DTACK is not received after 4 clocks of the E signal.

The processor board also includes a counter to generate a /DTACK for the RCBus MREQ and IORQ addresses. The /DTACK delay can currently be set to 1, 2, 3 or 4 system clocks.

Only RCBus /MREQ and /IORQ accesses generate a /DTACK. All other boards must supply their own /DTACK signal otherwise a bus error will be raised.

## RCBus Signals
The RCBus specification (v1.0) doesn't specifically mention the 68000 in the backplane signal assignments table so there's a bit of wiggle room on the pins used.

I've stuck to the same signals for pins 1-40. The M1 signal isn't used and should have a 4K7 pullup resistor (manually added as I forgot it in my release 2.0 board!) and the USER1..USER4 which are used for the level 1, 3, 5 & 6 autovector interrupts.

Pins 41-80 carry D8..D15 as well as the higher address bits. Pins 41..44 have been used to carry some 68000 specific signals.

The current signal list is in the RCBus 68000 Pinout PDF file.

## RCBus Memory Space
My 68000 design partially decodes 2 blocks of memory within the 68000 address range as follows:
| Address Range | Signal |
| :---- | :---- |
| 0xF00000..0xF7FFFF | /MREQ goes low |
| 0xF80000..0xFFFFFF | /IORQ goes low |

This partial decoding results in the RCBus I/O and memory spaces appearing multiple times within the 68000 address range. A /DTACK signal is generated on the processor card for any access to the RCBus whether there is a device present at that address or not.

For both I/O and memory spaces, consecutive memory locations are accessed on the ODD bytes such that I/O address 0x00 is accessed at address 0xF80001, address 0x01 is accessed at address 0xF80003 etc.

## Onboard LEDs
There were a few gates left over and I've used them to drive activity LEDs for accesses to the RCBus I/O and memory spaces as well as a HALT LED. Note that the I/O and MEM LEDs will only glow faintly.

# Board Assembly
Assembly of the board should be fairly straightforward. There are no surface mount devices to deal with.

Depending on your choice of LED colour, the associated current limiting resistor may need to be altered.

If you choose have a turned pin socket for the system clock, then an 8-pin DIL surned pin socket can be used. I flipped the socket over - so pins pointing upwards - and easily pushed out pins 2,3,6 & 7.

A **note of caution** when using a socketed oscillator - there is the possibility that the metal can of the oscillator could accidentally short out pins on the next board. Please be aware of this.

ICs are orientated in different directions - make sure you insert the chips into their sockets in the correct orientation. Also pay attention to the orientation of the 68000 processor - see note below. 

When fitting the 80-pin right angle connector, initially only solder a couple of pins at opposite ends of the connector so that you can make any adjustments if the board is not vertical when fitted to the backplane.

# Software
I've written a very simple monitor program for the 68000 board whick can be found in the ASM_CODE folder - called MON68K. The monitor was initially developed using EASy68K.

MON68K assumes that an SIO board is present and that one of the DUART chips is at address 0xD00000 (CS0 on the SIO board). If this is not the case, then the processor board will generate a bus error and stop in an endless loop.

## Interrupts
As the ROM is fixed at address 0x000000, the exception vector table addresses are also fixed. Exception vectors up to and including TRAP #15 each call their own handler stub within the monitor ROM. The remaining exception vectors are all directed to a single handler as they are not used within my design - i.e. vectored interrupts are not supported, only autovectored interrupts.

Each exception handler stub in the ROM (apart from bus error, address error and TRAP #15) looks up the start address of the actual exception handler code in a table of addresses held in RAM (which is initialised by the montor program). The table is located at the start of RAM occupying addresses 0x100000..0x1003FF and is laid out just like a normal exception vector table.

In order to use your own exception handler, you simply over write the RAM exception vector table entry with the address of your own handler.

A 68010 processor can also be used but the current monitor program doesn't make use of the vector base register at the moment.

# Jumpers
+ J1: DTACK delay of 1,2,3 or 4 clocks for the RCBus memory (MREQ) and I/O (IORQ) address spaces.
+ J4: Fit jumper to output the CPU E clock onto RCBus CLOCK2. Only fit this jumper if you are not using CLOCK2 to share clocks between the SIO, PIO & MFP boards. 

# Caution
+ CPU Insertion
  + Make sure you orientate the CPU the correct way. It can be easy to miss the notches on CPU and sockets
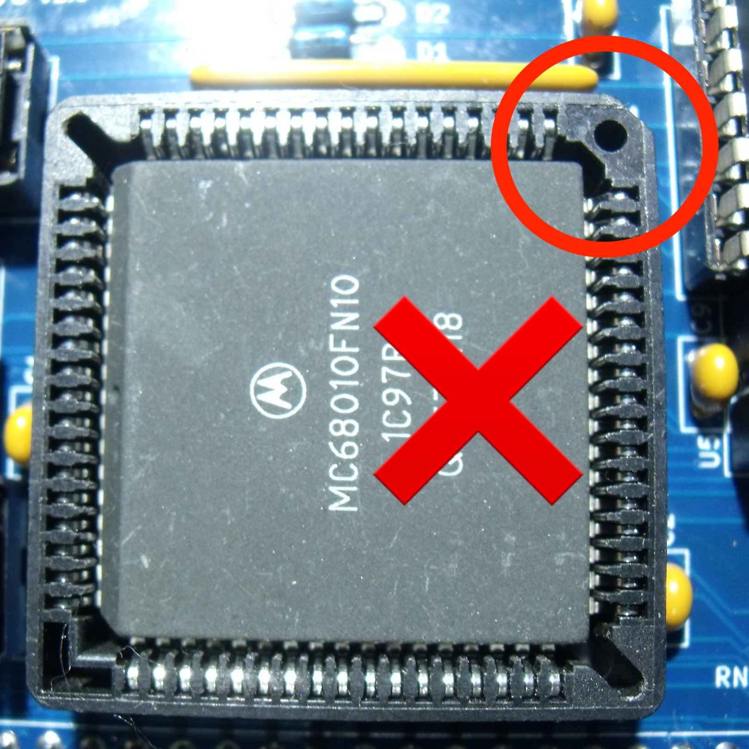
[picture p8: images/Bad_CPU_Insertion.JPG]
    
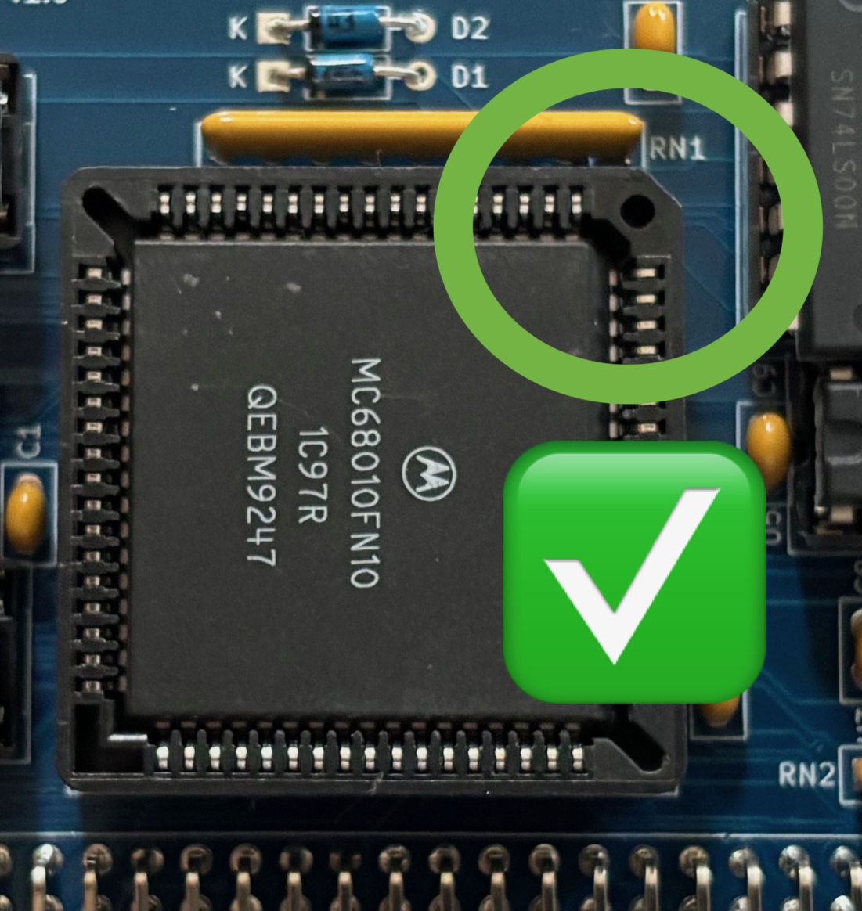
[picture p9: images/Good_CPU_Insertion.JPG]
    

# Errors
+ MREQ & IORQ Activity LEDs - The silkscreen labels I/O & MEM are the wrong way round!
+ Missing 4K7 pullup on the M1 signal - wire link M1 to a spare pin on RN1.

# To Do
+ Experiment to find the maximum width of board that JLCPCB will accept to keep the low price.
+ Modify the RCBus80 medium board footprint in Kicad so that pins 1,40,41 & 80 don't throw DRC warnings/errors.

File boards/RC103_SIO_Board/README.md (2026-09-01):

# Quad Serial I/O Board

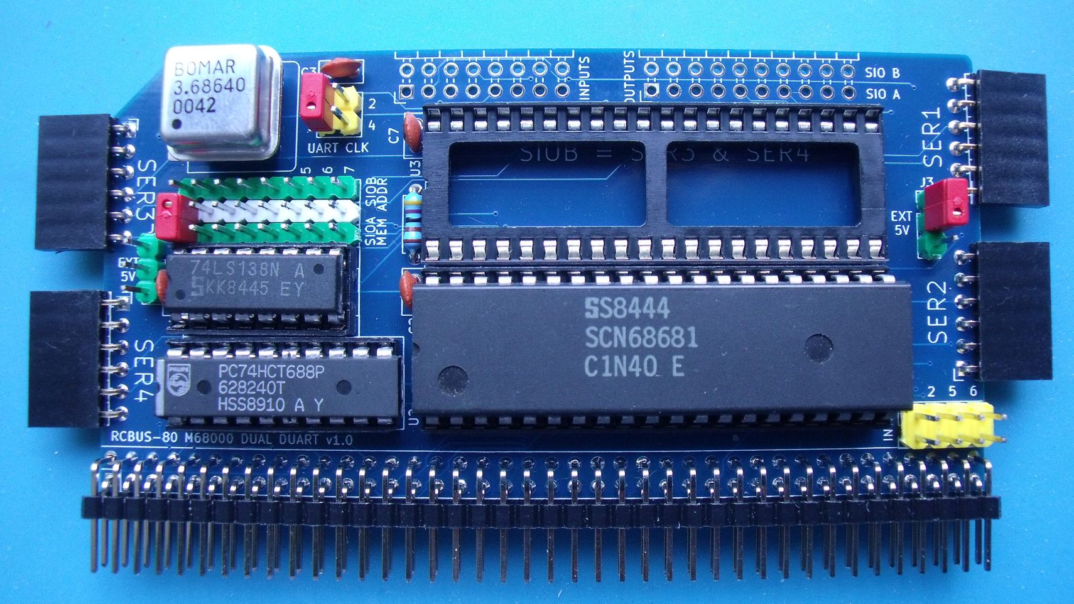
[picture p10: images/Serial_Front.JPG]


# Details
The serial board is populated with two 68681 (or equivalent) DUARTS giving 4 UARTs in total. The 4 serial ports are each fed to a 6-pin connector at the board edge. The layout of the 6 pins is compatible with an FTDI USB-TTL Serial interface board. Both DUART chips do not have to be fitted. The board will work with just one chip fitted.

## Address Decoding
The address decoding is carried out by a 74LS688 combined with a 74LS138 to generate 8 separate 2048 byte blocks residing between addresses $D00000 and $D03FFF.

The base address of each DUART is determined by the placement of a jumper between adjacent pins on J1 & J9 (DUART A) and J1 & J11 (DUART B).

## Device Register Access
The registers of the 68681 DUART are 8 bits wide and are accessed on consecutive ODD addresses from the base address set by the address decode logic. Assuming that the /CS0 jumper has been fitted for DUART #1, then the first few registers are accessed on the following addresses:
+ $D00001 : Mode Register A (R/W)
+ $D00003 : Status Register A (R) / Clock Select Register A (W)
+ $D00005 : Command Register A (W)

## DTACK
Each DUART generates its own /DTACK signal internally which is then routed back to the processor via RCBus-80 pin 62.

## Interrupts
The current board design combines the interrupts from both DUARTs into a single /INT signal. This /INT signal can then be assigned to an interrupt level of 1,2,5 or 6 depending on the jumper position on J12.

## Baud Rate Generator Clock
The clock signal for the baud rate generators can be sourced from the on board 3.6864MHz crystal oscillator (X1 in the schematic) or from an external clock source on the RCBus-80 CLOCK2 pin (pin 61) via the jumper J14.

The jumper J14 can also be configured to route the baud rate generator clock to the CLOCK2 pin on the RCBus-80 connector.

## Discrete Outputs
The 8 outputs from each DUART are routed to J4 on the edge of the board. J4 also provides GND and +5V signals. Note that the board **does not have** any protection built in to prevent damage to the DUART if one of these pins is mis-used.

## Discrete Inputs
The 6 inputs to each DUART are routed to J10 on the edge of the board. J10 also provides GND and +5V signals. Note that the board **does not have** any protection built in to prevent damage to the DUART if one of these pins is mis-used.

## Flow Control
Serial hardware flow control can be achieved on each of the 4 serial ports by shorting the appropriate solder jumpers on the rear of the board. This routes the 2 flow control signals for each serial port to an input pin and an output pin on the DUART.

## Power
The complete RCBus system can be powered from the 5V pin of one of the USB-TTL serial connectors by fitting a jumper in place on the appropriate pins of J3 or J6.

Note that there is a current limit of 500mA - imposed by the host system USB hardware - when the system is powered this way. It is relatively easy to exceed this limit once several boards are in use and I recommend that the system be powered from an external 5V supply connected to the RCBus backplane instead.
 
# Board Assembly
Assembly of the board should be fairly straightforward. There are no surface mount devices to deal with.

If you choose have a turned pin socket for the system clock, then an 8-pin DIL turned pin socket can be used. I flipped the socket over - pins pointing upwards - and easily pushed out pins 2,3,6 & 7.

A **note of caution** when using a socketed oscillator - there is the possibility that the metal can of the oscillator could accidentally short out pins on the next board. Please be aware of this.

When fitting the 80-pin right angle connector, initially only solder a couple of pins at opposite ends of the connector so that you can make any adjustments if the board is not vertical when fitted to the backplane.

# Choice of DUART Chip
There are various 68681 DUARTs but unfortunately they are not all entirely compatible. The issue appears to be in relation to the X2 input pin when an external oscillator is used rather than a crystal, specifically whether the X2 pin should be grounded or not. My current SIO board design grounds the X2 pin which limits the DUART choices to those devices that allow the X2 pin to be grounded. However you may be able to work around this by bending the X2 pin up so that it does not go into the IC socket.

Below are some 68681 DUARTs from different manufacturers and the relevant text from their datasheets:

+ Motorola MC68681 (max 38400 baud)
  + If an external TTL-level clock is used, this pin should be tied to ground. 
+ Motorola MC68HC681 (max 38400 baud)
  +  If an external CMOS-level clock is used, this pin must be left open. 
+ Philips SCC68681 (max 115200 baud)
  + If a crystal is not used it is best to keep this pin not connected. It **must not** be grounded.
+ Philips SCN68681 (max 115200 baud)
  + If a crystal is not used it is best to keep this pin not connected although it is permissible to ground it.
+ Philips SCC68692 (max 115200 baud)
  + If a crystal is not used it is best to keep this pin not connected although it is permissible to ground it.
+ Toshiba TMP68681 (max 38400 baud)
  + If an external TTL-level clock is used, this pin should be tied to ground. 

For the Philips devices that support 115200 baud, this is achieved by putting the device into a test mode and is documented in the Philips Semiconductors document titled "Extended baud rates for SCN2681, SCN68681, SCC2691, SCC2692, SCC68681 and SCC2698B".

# Jumpers
+ J1: IO Address selection
  + $D00000
  + $D00800
  + $D01000
  + $D01800
  + $D02000
  + $D02800
  + $D03000
  + $D03800
+ J2: Serial #3 port
+ J3: (**only fit one jumper** if not using an external 5V power source)
  + 1-2 : Power the system from the USB-TTL Serial board on Serial #1
  + 2-3 : Power the system from the USB-TTL Serial board on Serial #2
  + 1-2 : Power the system from the USB-TTL Serial board on Serial #3
  + 2-3 : Power the system from the USB-TTL Serial board on Serial #4
+ J4: Exposes the 16 digital outputs from the 2 DUARTS as well as GND and +5V. Note that there is **NO** output protection circuitry.
+ J5: Serial #4 port
+ J7: Serial #1 port
+ J8: Serial #2 port
+ J9 (with J1): Specify the IO Address for Serial chip A
+ J10: Exposes the 12 digital inputs to the 2 DUARTS as well as GND and +5V. Note that there is **NO** input protection circuitry.
+ J11 (with J1): Specify the IO Address for Serial chip B
+ J12: Specify the interupt line to be used by the serial cards
  + 1-2 : use /INT1
  + 3-4 : use /INT2
  + 5-6 : use /INT5
  + 7-8 : use /INT6 
+ J14: Specifies the clock source for the DUART baud rate generators
  + 1-3 Use the onboard clock source
  + 1-2 Use the RCBus clock source from CLOCK2
  + 1-2 *and* 3-4: Use the onboard clock source and supply the RCBus CLOCK2 signal with the clock.

# Errors
None so far.

# Thoughts / Enhancements
+ Should the SIOs each have their own choice of interrupt level?
+ Move the 6-pin serial port connectors further in from the board edge.
+ Jumpers to allow TXD1 & RXD1 to route to the RCBus TX & RX signals.
+ Jumpers to allow TXD2 & RXD2 to route to the RCBus TX2 & RX2 signals.
+ Board would support a wider range of compatible 68681s with a solder jumper between the X2 pin and GND.

# To Do
+ Experiment to find the maximum width of board that JLCPCB will accept to keep the low price.
+ Modify the RCBus80 medium board footprint in Kicad so that pins 1,40,41 & 80 don't throw DRC warnings/errors.

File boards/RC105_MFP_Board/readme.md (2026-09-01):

# Dual MultiFunction Peripheral Board

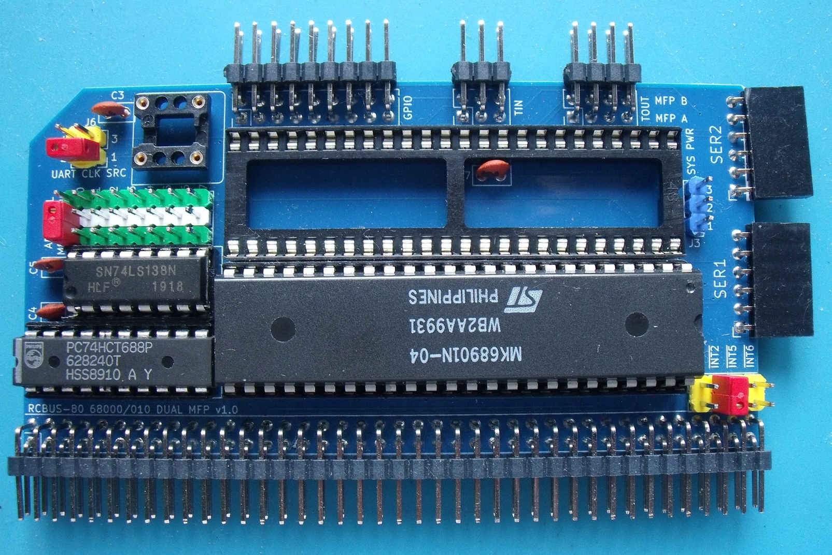
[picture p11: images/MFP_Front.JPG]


# Details
The multifunction peripheral board is populated with two 68901 chips. Both chips do not have to be fitted. The board will work with just one chip fitted.

## Address Decoding
The address decoding is carried out by a 74LS688 combined with a 74LS138 to generate 8 separate 2048 byte blocks residing between addresses $D10000 and $D13FFF.

The base address of each MFP is determined by the placement of a jumper between adjacent pins on J12 & J9 (MFP A) and J12 & J11 (MFP B).

## Device Register Access
The registers of the MFP are 8 bits wide and are accessed on consecutive ODD addresses from the base address set by the address decode logic. Assuming that the /CS0 jumper has been fitted for MFP #1, then the first few registers are accessed on the following addresses:
+ $D10001 : General Purpose I/O Data Register
+ $D10003 : Active Edge Register
+ $D10005 : Data Direction Register

## DTACK
Each MFP generates its own /DTACK signal internally which is then routed back to the processor via RCBus-80 pin 62.

## Clock Source
The clock signal for the chip functions and timers can be sourced from the on board 3.6864MHz crystal oscillator (X1 in the schematic) or from an external clock source on the RCBus-80 CLOCK2 pin (pin 61) via the jumper J6.

Note that each MFP chip **requires** a clock signal in order to function correctly, even if the UART and timer are not being used. 

## UART Baud Rate Clock
The MFP does not have a built-in baud rate generator like the 68681 does. In order to generate the required UART clock, the output of timer D hard wired to the Tx and Rx clock inputs.

Assuming that the crystal oscillator (or CLOCK2) frequency is 3.6864MHz, with the prescaled set to DIV 4 and the required baud rate of 9600 baud, then the following calculation will provide the timer D reload value:
```
reload value = clock / prescaler / 16 / baud rate
reload value = 3686400 / 4 / 16 / 9600 = 6
```

## UART Edge Connector
The 6-pin UART connector is compatible with an FTDI USB-TTL Serial interface board.

## UART Flow Control
Serial hardware flow control can be achieved on the serial port by shorting the appropriate solder jumpers on the rear of the board. This routes the 2 flow control signals for each serial port to 2 I/O pins one each MFT.

## Input / Output Pins
Each MFP provides a single 8-bit I/O port with programmable direction control for each bit. Connector J4 carries the 8 port pins for both MFP chips as well as 2 GND pins.

Note that the board **does not have** any protection built in to prevent damage to the MFP chips if one of these pins is mis-used.

## Power
The complete RCBus system can be powered from the 5V pin of one of the USB-TTL serial connectors by fitting a jumper in place on the appropriate pins of J3.

Note that there is a current limit of 500mA - imposed by the host system USB hardware - when the system is powered this way. It is relatively easy to exceed this limit once several boards are in use and I recommend that the system be powered from an external 5V supply connected to the RCBus backplane instead.

# Board Assembly
Assembly of the board should be fairly straightforward as there are no surface mount devices to deal with.

If you choose have a turned pin socket for the system clock, then an 8-pin DIL turned pin socket can be used. I flipped the socket over - pins pointing upwards - and easily pushed out pins 2,3,6 & 7.

A **note of caution** when using a socketed oscillator - there is the possibility that the metal can of the oscillator could accidentally short out pins on the next board. Please be aware of this.

When fitting the 80-pin right angle connector, initially only solder a couple of pins at opposite ends of the connector so that you can make any adjustments if the board is not vertical when fitted to the backplane.

Note the orientation of the two MFP chips - they are effectively upside down.

# Jumpers
+ J2: Specify the interupt line to be shared by the MFP chips
  + 1-2 : use /INT1
  + 3-4 : use /INT2
  + 5-6 : use /INT5
  + 7-8 : use /INT6 
+ J3: (**only fit one jumper** if not using an external 5V power source)
  + 1-2 : Power the system from the USB-TTL Serial board on Serial #1
  + 2-3 : Power the system from the USB-TTL Serial board on Serial #2
+ J4: I/O pins for both MFP chips - refer to schematic
+ J5: Timer A, B & C outputs for both MFP chips - refer to schematic
+ J6: Specify the clock source
  + 1-3 Use the onboard clock source
  + 1-2 Use the RCBus clock source from CLOCK2
  + 1-2 *and* 3-4: Use the onboard clock source and supply the RCBus CLOCK2 signal with the clock.
+ J7: Serial #1 port
+ J8: Serial #2 port
+ J9 (with J12): Specify the IO Address for MFP chip A
+ J11 (with J12): Specify the IO Address for MFP chip B
+ J12: IO Address selection
  + $D10000
  + $D10800
  + $D11000
  + $D11800
  + $D12000
  + $D12800
  + $D13000
  + $D13800
+ J14: Timer A & B inputs - refer to schematic

# Caution
Pay attention to the orientation of the chips on this board.

# Errors
None so far.

# Thoughts / Enhancements
+ Should the MFPs each have their own choice of interrupt level?

# To Do
+ Experiment to find the maximum width of board that JLCPCB will accept to keep the low price.
+ Modify the RCBus80 medium board footprint in Kicad so that pins 1,40,41 & 80 don't throw DRC warnings/errors.

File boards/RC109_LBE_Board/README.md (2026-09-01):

# 68000 LBE (Little Bit of Everything) Board #1

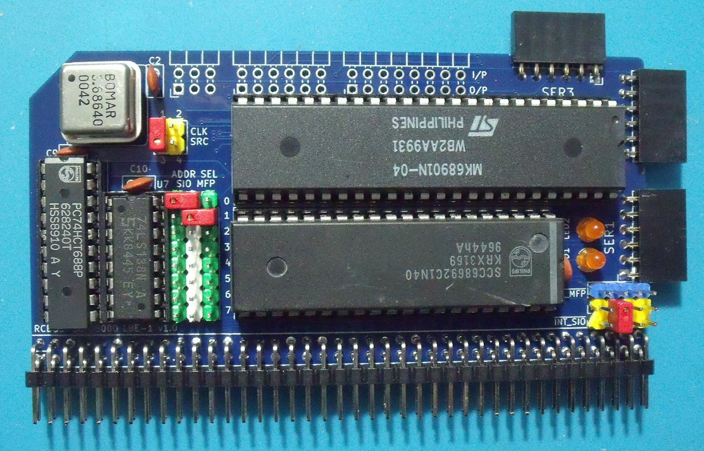
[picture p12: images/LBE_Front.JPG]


# Details

The intention of this board is to try and make a 68000 equivalent of Steve Cousins Z80 [SC110 board](https://smallcomputercentral.com/rcbus/sc100-series/sc110-z80-serial-rc2014-3/) which consists of a Z80 SIO/2 serial chip and a Z80 CTC counter timer chip providing 2 serial ports and 4 8-bit down counters.

By combining an MC68681 DUART (or equivalent) with an MC68901 MFP I managed to achieve a similar board, but with a bit more functionality - mainly due to the MC68901.

The MC68681 provides:
+ 2 Serial Ports (SER1 & SER2)
+ 8 Digital Outputs
+ 6 Digital Inputs
+ 1 16-bit Timer

The MC68901 provides:
+ 1 Serial Port (SER3)
+ 8 Digital Inputs/Outputs
+ 4 8-bit Timers

The design provides serial I/O, digital I/O and some timers so the name Little Bit of Everything seemed appropriate.

Note that the X2 pin of the MC68681 has a solder jumper (JP7) so that this pin can be grounded if required. This should allow a greater choice of MC68681 alternatives to be fitted.

## Address Decoding
The address decoding is carried out by a 74LS688 combined with a 74LS138 to generate 8 separate 2048 byte blocks residing between addresses $D00000 and $D03FFF. This is the same address range that the SIO (quad serial) board uses, allowing for the same monitor program to work with either board.

The base address of the DUART and the MPF are determined by the placement of a jumper between adjacent pins on J12 & J13 (DUART) and J12 & J18 (MFP).

## MC68681 DUART
### 68681 Register Access
The registers of the 68681 DUART are 8 bits wide and are accessed on consecutive ODD addresses from the base address set by the address decode logic. Assuming that the /CS0 jumper has been fitted for the DUART, then the first few registers are accessed on the following addresses:
+ $D00001 : Mode Register A (R/W)
+ $D00003 : Status Register A (R) / Clock Select Register A (W)
+ $D00005 : Command Register A (W)

### 68681 Baud Rate Generator Clock
The clock signal for the baud rate generators can be sourced from the on board 3.6864MHz crystal oscillator (X1 in the schematic) or from an external clock source on the RCBus-80 CLOCK2 pin (pin 61) via the jumper J4.

The jumper J4 can also be configured to route the baud rate generator clock to the CLOCK2 pin on the RCBus-80 connector.

### 68681 Discrete Outputs
The lower 6 outputs from the DUART (OP0..OP5) are routed to J8 on the edge of the board. Note that the board **does not have** any protection built in to prevent damage to the DUART if one of these pins is mis-used.

The upper 2 outputs from the DUART (OP6 & OP7) are routed to 2 on-board LEDs that can be turned on or off as required.

**CAUTION:**  Be careful with J8 if you use a pinheader as J8 also provides GND and +5V signals which can easily short to something they shouldn't.
 
### 68681 Discrete Inputs
The 6 inputs to the DUART (IP0..IP5) are also routed to J8 on the edge of the board. Note that the board **does not have** any protection built in to prevent damage to the DUART if one of these pins is mis-used.

### 68681 Flow Control
Serial hardware flow control can be achieved on each of the 2 serial ports by shorting the appropriate solder jumpers on the rear of the board. This routes the 2 flow control signals for each serial port to an input pin and an output pin on the DUART.

## MC68901
### 68901 Register Access
The registers of the MFP are 8 bits wide and are accessed on consecutive ODD addresses from the base address set by the address decode logic. Assuming that the /CS1 jumper has been fitted for the MFP, then the first few registers are accessed on the following addresses:

+ $D00801 : General Purpose I/O Data Register
+ $D00803 : Active Edge Register
+ $D00805 : Data Direction Register

### 68901 Baud Rate Generator Clock
The MFP does not have a built-in baud rate generator like the 68681 does. In order to generate the required UART clock, the output of timer D is hard wired to the Tx and Rx clock inputs.

The 68901 uses the same clock source that the 68681 does and is determined by the setting of jumper J4.

### 68901 Discrete Input / Output
The 8 discrete I/O signals of the bit programmable 8-bit I/O port are routed to J5. Note that the board **does not have** any protection built in to prevent damage to the MFP if one of these pins is mis-used.

**CAUTION:**  Be careful with J5 if you use a pinheader as J5 also provides GND and +5V signals which can easily short to something they shouldn't.

### 68901 Serial Port Flow Control
Serial hardware flow control can be achieved on the serial port by shorting the appropriate solder jumpers on the rear of the board. This routes the 2 flow control signals to IO0 & IO1 on the 8-bit I/O port of the MFP.

### 68901 Timers
Timers A, B & C are available for general use. Timer D is used to generate the baud rate clock for the UART, but is also available for general use if the UART is not used.

The timer outputs TA0, TB0, TC0 & TD0 are available on J6 along with the TAI & TBI signals.

## DTACK
The DUART and MFP generate their own /DTACK signal internally which is then routed back to the processor via RCBus-80 pin 62.

## Interrupts
The board design allows for the DUART & MFP to use separate (but not the same) interrupts. Depending on the jumper setting the DUART and MFP can be assigned to an interrupt level of 1,2,5 or 6 depending on the jumper positions on J1 & J2.

## Power
The 5V pin on each of the SER1, SER2 & SER3 headers is not connected. System power must be supplied from another source.

# Board Assembly
Assembly of the board should be fairly straightforward. There are no surface mount devices to deal with.

If you choose have a turned pin socket for the system clock, then an 8-pin DIL turned pin socket can be used. I flipped the socket over - pins pointing upwards - and easily pushed out pins 2,3,6 & 7.

A **note of caution** when using a socketed oscillator - there is the possibility that the metal can of the oscillator could accidentally short out pins on the next board. Please be aware of this.

When fitting the 80-pin right angle connector, initially only solder a couple of pins at opposite ends of the connector so that you can make any adjustments if the board is not vertical when fitted to the backplane.

# Choice of DUART Chip
There are various 68681 DUARTs but unfortunately they are not all entirely compatible. The issue appears to be in relation to the X2 input pin when an external oscillator is used rather than a crystal, specifically whether the X2 pin should be grounded or not. The LBE #1 board design can ground the X2 pin via solder jumper JP7 - see jumpers section below.

Below are some 68681 DUARTs from different manufacturers and the relevant text from their datasheets:

+ Motorola MC68681 (max 38400 baud)
  + If an external TTL-level clock is used, this pin should be tied to ground. 
+ Motorola MC68HC681 (max 38400 baud)
  +  If an external CMOS-level clock is used, this pin must be left open. 
+ Philips SCC68681 (max 115200 baud)
  + If a crystal is not used it is best to keep this pin not connected. It **must not** be grounded.
+ Philips SCN68681 (max 115200 baud)
  + If a crystal is not used it is best to keep this pin not connected although it is permissible to ground it.
+ Philips SCC68692 (max 115200 baud)
  + If a crystal is not used it is best to keep this pin not connected although it is permissible to ground it.
+ Toshiba TMP68681 (max 38400 baud)
  + If an external TTL-level clock is used, this pin should be tied to ground. 

For the Philips devices that support 115200 baud, this is achieved by putting the device into a test mode and is documented in the Philips Semiconductors document titled "Extended baud rates for SCN2681, SCN68681, SCC2691, SCC2692, SCC68681 and SCC2698B".

# Jumpers
+ J1 : Specify the interupt line to be used by the MFP
  + 1-2 : use /INT1
  + 3-4 : use /INT2
  + 5-6 : use /INT5
  + 7-8 : use /INT6 
+ J2 : Specify the interupt line to be used by the DUART
  + 1-2 : use /INT1
  + 3-4 : use /INT2
  + 5-6 : use /INT5
  + 7-8 : use /INT6 
+ J4: Specifies the clock source for the DUART baud rate generator & MFP timers
  + 1-3 Use the onboard clock source
  + 1-2 Use the RCBus clock source from CLOCK2
  + 1-2 *and* 3-4: Use the onboard clock source and supply the RCBus CLOCK2 signal with the clock.
+ J5: Carries the digital I/O pins of the MFP as well as GND and +5V. Note that there is **NO** input protection circuitry.
+ J6: Carries the 4 MFP timer outputs as well as timer A & B inputs.
+ J8: Carries the digital I/O pins of the DUART as well as GND and +5V. Note that there is **NO** input protection circuitry.
+ J12: IO Address selection
  + $D00000
  + $D00800
  + $D01000
  + $D01800
  + $D02000
  + $D02800
  + $D03000
  + $D03800
+ J13 (with J12): Specify the IO Address for the DUART
+ J15: Serial #1 port (DUART channel 1)
+ J16: Serial #2 port (DUART channel 2)
+ J17: Serial #3 port (MFP)
+ J18 (with J12): Specify the IO Address for the MFP

# Solder Jumpers (rear of board)
+ JP1 : Connects SER1 pin 6 to DUART IP0
+ JP2 : Connects SER1 pin 1 to DUART OP0
+ JP3 : Connects SER2 pin 6 to DUART IP1
+ JP4 : Connects SER2 pin 1 to DUART OP1
+ JP5 : Connects SER3 pin 6 to MFP IO0
+ JP6 : Connects SER3 pin 1 to MFP IO1
+ JP7 : Connects DUART X2 pin to GND (check your specific DUART datasheet)

# Errors
None so far.

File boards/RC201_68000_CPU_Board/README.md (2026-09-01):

# RC201 - 68000 Processor Board

Actual image of the processor board under test with IRQ2, IRQ5 and IRQ6 configured for autovectored interrupts and IRQ3 for vectored interrupts.

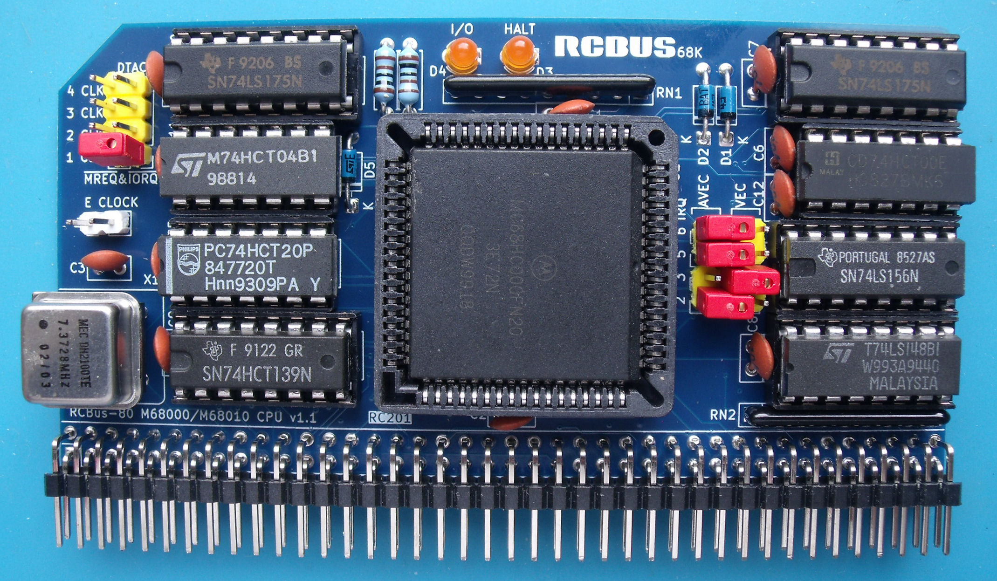
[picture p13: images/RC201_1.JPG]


# Details
The processor board consists of a PLCC packaged MC68000 processor, bits of glue logic and the processor clock source. A 68010 processor can also be used but the current monitor program doesn't make use of the vector base register at the moment.

The processor board is designed to plug into an RCBus-80 backplane and expects to find the stack pointer and initial program counter addresses at location 0x000000 onwards.

## Reset
The reset signal for the processor board must be supplied externally, entering the board via pin 20 of the RCBus connector. This should not be an issue if you are using one of Steve Cousins's backplanes.

## Processor Clock
The processor/system clock source is an oscillator in an 8-pin DIL/DIP can (X1 in the schematic). Basic testing was done with a 7.3728MHz oscillator. 

There's also a jumper (J4) to allow the processor E clock to be routed onto the RCBus CLOCK2 pin (61) if required. However, note that the CLOCK2 pin may also be used by other boards such as the RC202 serial board (to share its 3.6864MHz UART clock). If this feature is used, then the E clock jumper **must not** be fitted.

## DTACK & Bus Error
The processor board includes a counter to generate a bus error if a /DTACK is not received after 4 clocks of the E signal.

The processor board also includes a counter to generate a /DTACK for the RCBus MREQ and IORQ addresses. The /DTACK delay can currently be set to 1, 2, 3 or 4 system clocks.

Only RCBus /MREQ and /IORQ accesses generate a /DTACK. All other boards must supply their own /DTACK signal otherwise a bus error will be raised.

## RCBus Signals
The RCBus specification (v1.0) doesn't specifically mention the 68000 in the backplane signal assignments table so there's a bit of wiggle room on the pins used.

I've stuck to the same signals for most of the RCBus-80 pins with the following deviations:
| Pin(s) | Details |
| :---- | :---- |
| 1..16 | These are address lines A1..16 (rather than A0..A15) |
| 19 | The M1 signal isn't used and has a 4K7 pullup resistor to 5V |
| 22 | This is the interupt level 4 signal (autovector only) |
| 37..40 | The USER1..USER4 signals are used to signal interrupt levels 2,3,5 & 6 |
| 41 | 68000 Address Strobe signal /AS |
| 42 | 68000 Upper Data Strobe signal /UDS |
| 43 | 68000 Lower Data Strobe signal /LDS |
| 44 | 68000 Read/Write signal (1=Read & 0=Write) |
| 47 | This is the interupt level 1 signal (autovector only) |
| 50..56 | These are address lines A17..23 (rather than A16..A22) |
| 61 | This is usually the UART 3.6864MHz oscillator but can be the 68000 E clock |
| 62 | This is /DTACK |
| 66 | This is the interupt level 7 signal (autovector only) |
| 77..80 | The USER5..USER8 signals are used to signal interrupt acknowledges for levels 2,3,5 & 6 |

The current signal list is in the RCBus 68000 Pinout PDF file.

## RCBus Memory Space
My RC201 68000 design partially decodes 2 blocks of memory within the 68000 address range as follows:
| Address Range | Signal |
| :---- | :---- |
| 0xF80000..0xF9FFFF | /MREQ goes low |
| 0xFA0000..0xFBFFFF | /IORQ goes low |

**NOTE** These address ranges are different to previous I/O and memory space address ranges.

This partial decoding results in the RCBus I/O and memory spaces appearing multiple times within the 68000 address range. A /DTACK signal is generated on the processor card for any access to the RCBus whether there is a device present at that address or not.

For both I/O and memory spaces, consecutive memory locations are accessed on the ODD bytes such that I/O address 0x00 is accessed at address 0xFA0001, address 0x01 is accessed at address 0xFA0003 etc.

## Onboard LEDs
There were a couple of gates left over and I've used them to drive and activity LED for accesses to the RCBus I/O space as well as a HALT LED. Note that the I/O LED will only glow faintly.

# Board Assembly
Assembly of the board should be fairly straightforward. There are no surface mount devices to deal with.

If you choose have a turned pin socket for the system clock, then an 8-pin DIL surned pin socket can be used. I flipped the socket over - so pins pointing upwards - and easily pushed out pins 2,3,6 & 7.

A **note of caution** when using a socketed oscillator - there is the possibility that the metal can of the oscillator could accidentally short out pins on the next board. Please be aware of this.

Make sure you insert the chips into their sockets in the correct orientation. Also pay attention to the orientation of the 68000 processor as it is possible the insert it into the PLCC socket in the wrong orientation. 

When fitting the 80-pin right angle connector, initially only solder a couple of pins at opposite ends of the connector so that you can make any adjustments if the board is not vertical when fitted to the backplane.

# Software
I've modified my original MON68K monitor to work with this processor card and the RC208 memory card. The updated monitor code can be found in the ASM_CODE folder - called rcMON68K_v2.0. The monitor was initially developed using EASy68K.

The monitor assumes that an SIO board is present and that one of the DUART chips is at address 0xD00000 (CS0 on the SIO board). If this is not the case, then the processor board will generate a bus error and stop in an endless loop.

## Interrupts
The monitor program assumes that one of the auto switching memory boards in being used and that once the initial stack pointer and program counter have been read, the ROM automatically moves to address 0x700000 onwards. The exception vector table is then copied into RAM at address 0x000000 ready for use.

This processor card supports a mixture of vectored and autovectored interrupts. Interrupt levels 1, 4 & 7 are always autovectored whereas interrupt levels 2, 3, 5 & 6 can be configured via jumpers to be either vectored or autovectored interrupts.

In order to use your own exception handler, simply overwrite the RAM exception vector table entry with the address of your own handler.

# Jumpers
+ J1: DTACK delay of 1,2,3 or 4 clocks for the RCBus memory (MREQ) and I/O (IORQ) address spaces.
+ J4: Fit jumper to output the CPU E clock onto RCBus CLOCK2. Only fit this jumper if you are not using CLOCK2 to share clocks between other boards. 

# Caution
+ CPU Insertion
  + Make sure you orientate the CPU the correct way. It can be easy to miss the notches on CPU and sockets
    
    

# Future Enhancements
Nothing yet.

# Errors
Nothing yet - but give it time :-(

# History
+ v1.1 - changed RCBus MEM & IO space decoding to avoid conflict with vectored interrupt sequence
+ v1.0 - initial design

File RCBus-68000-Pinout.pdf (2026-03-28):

## RCBus 68000 Pinout vs Exisng Pinouts

( v1.2 28-Mar-26 )
RCBus-68000 VI RCBus-68000 | RCBus | RC2014™ | Pin | Pin | RC2014™ | RCBus | RCBus-68000 RCBus-68000 VI
nAS | nAS | 41 | 1 | A15 | A15 | A16 | A16
nUDS | nUDS | 42 | 2 | A14 | A14 | A15 | A15
nLDS | nLDS | 43 | 3 | A13 | A13 | A14 | A14
R/nW | R/nW | 44 | 4 | A12 | A12 | A13 | A13
Note #3 | Note #3 | 45 | 5 | A11 | A11 | A12 | A12
Note #3 | Note #3 | 46 | 6 | A10 | A10 | A11 | A11
nINT1 | 47 | 7 | A9 | A9 | A10 | A10
48 | 8 | A8 | A8 | A9 | A9
A23 | 49 | 9 | A7 | A7 | A8 | A8
A23 | A23 | A22 | 50 | 10 | A6 | A6 | A7 | A7
A22 | A22 | A21 | 51 | 11 | A5 | A5 | A6 | A6
A21 | A21 | A20 | 52 | 12 | A4 | A4 | A5 | A5
A20 | A20 | A19 | 53 | 13 | A3 | A3 | A4 | A4
A19 | A19 | A18 | 54 | 14 | A2 | A2 | A3 | A3
A18 | A18 | A17 | 55 | 15 | A1 | A1 | A2 | A2
A17 | A17 | A16 | 56 | 16 | A0 | A0 | A1 | A1
GND | GND | GND | 57 | 17 | GND | GND | GND | GND
+5V | +5V | +5V | 58 | 18 | +5V | +5V | +5V | +5V
nRFSH | 59 | 19 | nM1 | nM1 | Note #1 | Note #1
PAGE | 60 | 20 | nRESET | nRESET | nRESET | nRESET
Note #2 | Note #2 | CLOCK2 | 61 | 21 | CLOCK | CLOCK | CLOCK | CLOCK
nDTACK | nDTACK | nBUSACK | 62 | 22 | nINT | nINT | nINT4 | nINT4
nHALT | nHALT | nHALT | 63 | 23 | nMREQ | nMREQ | nMREQ | nMREQ
nBUSRQ | 64 | 24 | nWR | nWR | nWR | nWR
nWAIT | 65 | 25 | nRD | nRD | nRD | nRD
nINT7 | nINT7 | nNMI | 66 | 26 | nIORQ | nIORQ | nIORQ | nIORQ
D8 | D8 | D8 | 67 | 27 | D0 | D0 | D0 | D0
D9 | D9 | D9 | 68 | 28 | D1 | D1 | D1 | D1
D10 | D10 | D10 | 69 | 29 | D2 | D2 | D2 | D2
D11 | D11 | D11 | 70 | 30 | D3 | D3 | D3 | D3
D12 | D12 | D12 | 71 | 31 | D4 | D4 | D4 | D4
D13 | D13 | D13 | 72 | 32 | D5 | D5 | D5 | D5
D14 | D14 | D14 | 73 | 33 | D6 | D6 | D6 | D6
D15 | D15 | D15 | 74 | 34 | D7 | D7 | D7 | D7
TX2 | 75 | 35 | TX | TX
RX2 | 76 | 36 | RX | RX
nIACK2 | INT2 | USER5 | 77 | 37 | USER1 | INT1 | nINT1 | nINT2
nIACK3 | USER6 | 78 | 38 | USER2 | IEI | nINT2 | nINT3
nIACK5 | USER7 | 79 | 39 | USER3 | IEO | nINT5 | nINT5
nIACK6 | USER8 | USER8 | 80 | 40 | USER4 | USER4 | nINT6 | nINT6
Note #1 : | Pin 19 (nM1) pulled up to +5V via 4K7 resistor on CPU card.
Note #2 : | Either CPU E clock (via jumper on CPU card) or external clock from SIO or MFP board.
Note #3 : | For the MC68302 board, pin 45 can be routed to /CS0 and pin 46 routed to /CS1.

RCBus-68000 VI pinouts are to support my vectored interrupt boards.

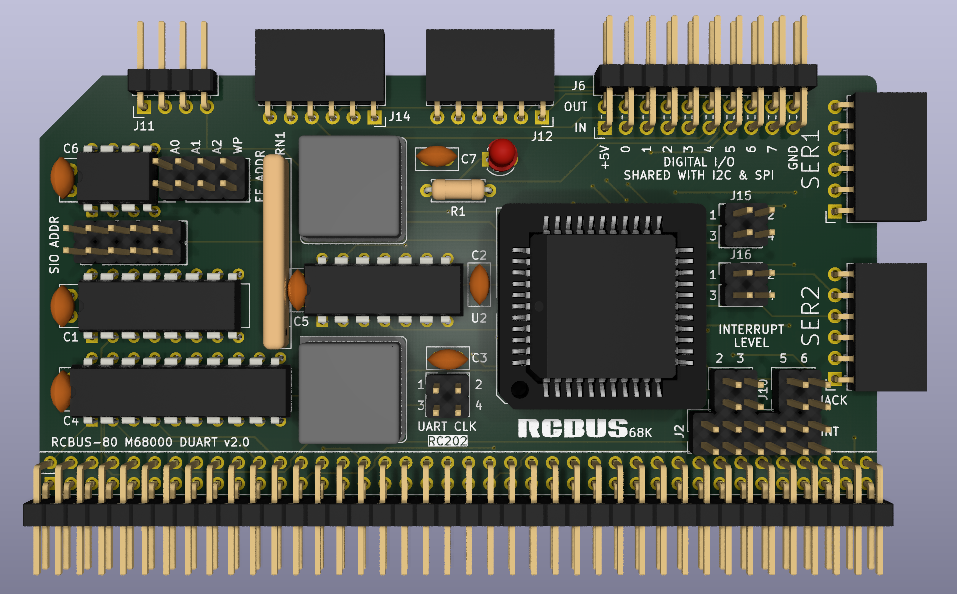
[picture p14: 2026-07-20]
images/RC202-68000_SIO_1.png

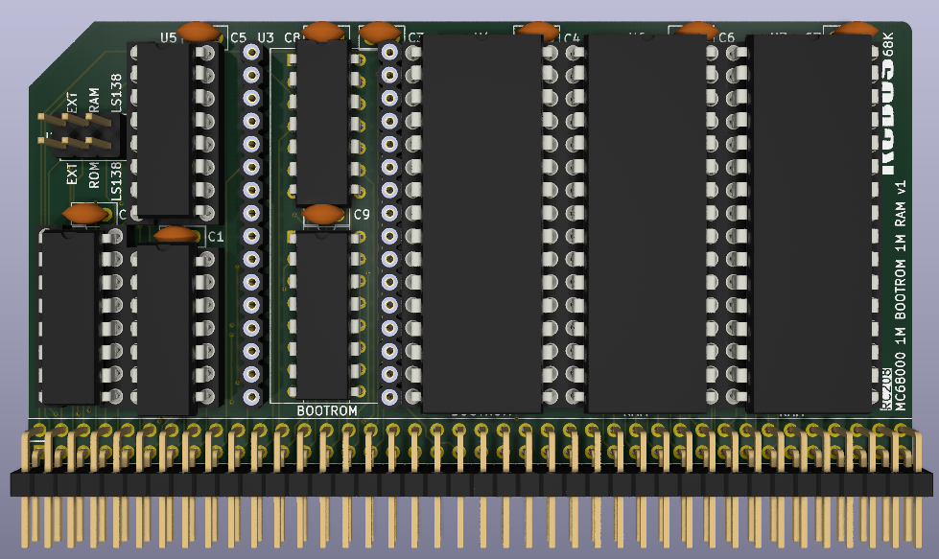
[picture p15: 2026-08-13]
images/RC208-2.png

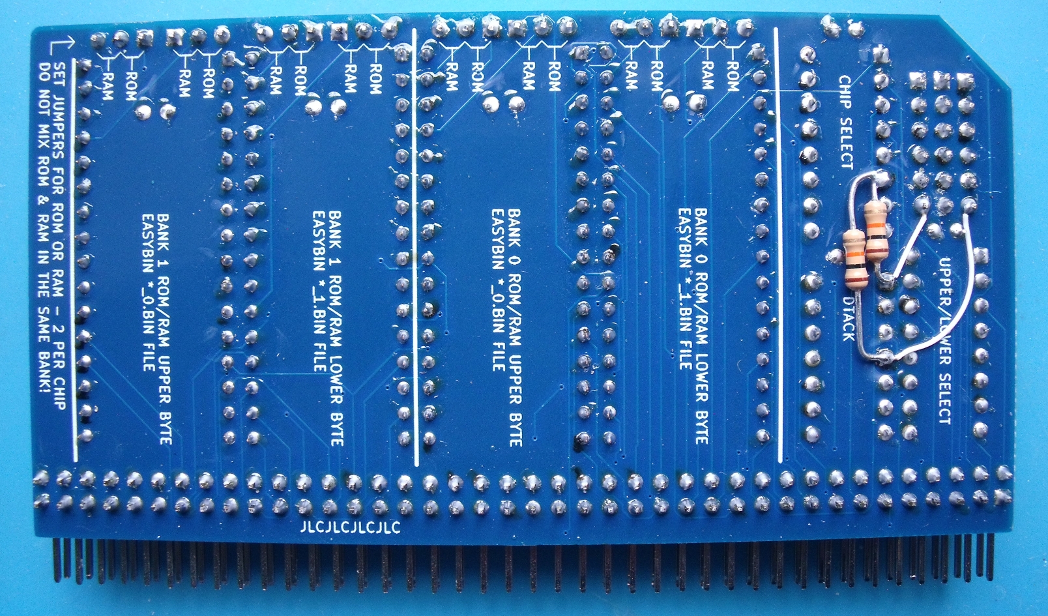
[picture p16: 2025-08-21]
images/ROM_RAM_v2_Rear.JPG

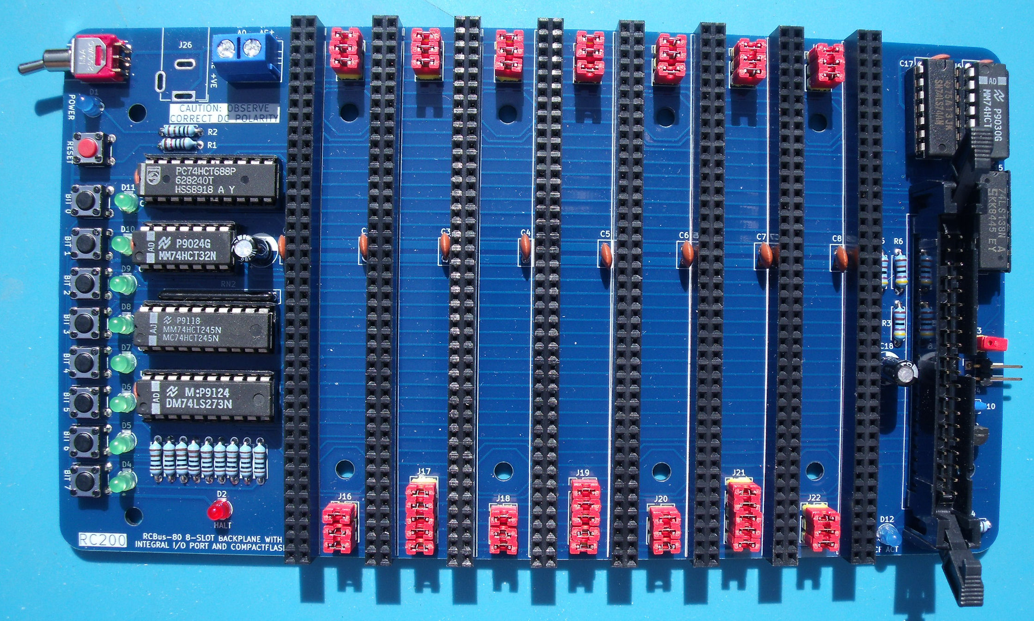
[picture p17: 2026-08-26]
images/RC200_1.JPG

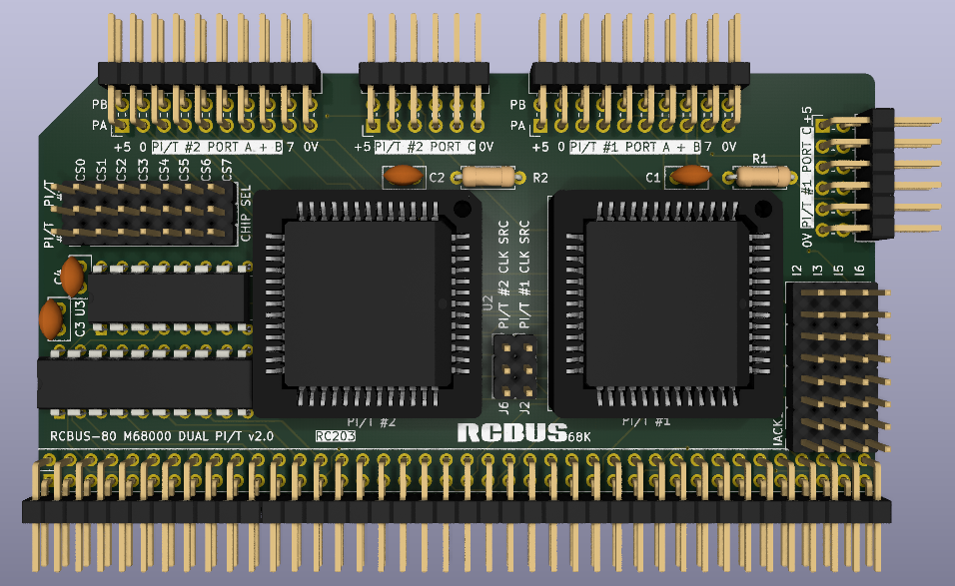
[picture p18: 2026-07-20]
images/RC203-68000_PIO_1.png

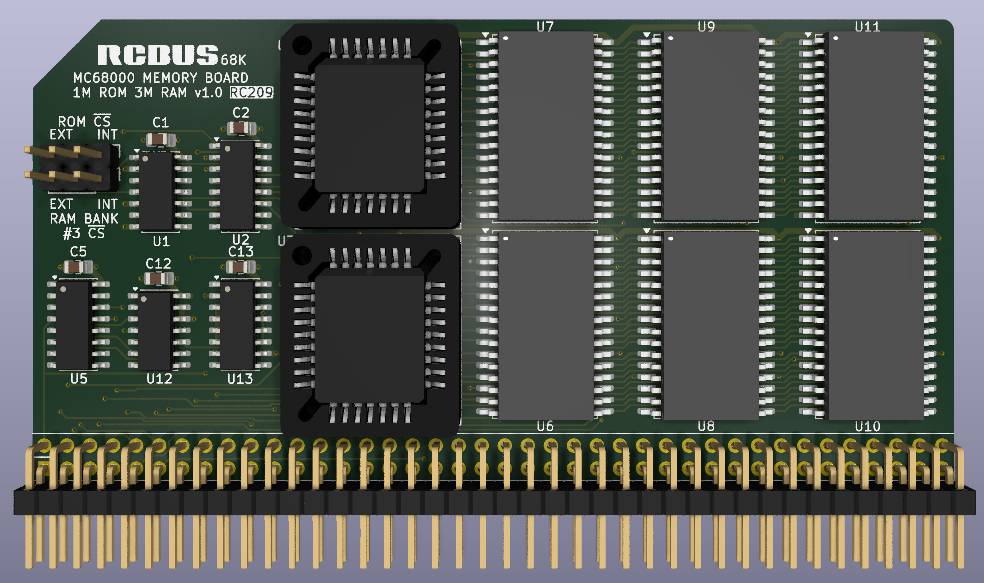
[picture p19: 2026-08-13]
images/RC209-1.png

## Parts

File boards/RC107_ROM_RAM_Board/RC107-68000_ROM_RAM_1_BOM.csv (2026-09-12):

Reference | Value | Qty | Description
C1,C2,C3,C4,C5,C6,C7 | 100n | 7 | Unpolarized ceramic capacitor
J1 | RCBus_80PIN_68000 | 1 | Generic connector, double row, 02x40, right angle
J2,J3,J4,J5,J6,J7,J8,J9 | Conn_01x03 | 8 | Generic connector, single row, 01x03
J10,J11,J12 | Conn_01x06 | 3 | Generic connector, single row, 01x06
R1,R2 | 10K | 2 | Resistor
U1 | 74LS125 | 1 | Quad buffer 3-State outputs
U2 | 74LS139 | 1 | Dual Decoder 1 of 4, Active low outputs
U3,U4 | SST39SF040 | 2 | Silicon Storage Technology (SSF) 512k x 8 Flash ROM
U5 | 74LS138 | 1 | Decoder 3 to 8 active low outputs
U6,U7 | AS6C4008-55PCN | 2 | 512K x 8 Low Power CMOS RAM, DIP-32

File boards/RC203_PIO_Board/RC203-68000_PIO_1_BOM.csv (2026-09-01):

Reference | Value | Footprint | Qty | Description
C1,C2,C3,C4 | 100n | Capacitor_THT:C_Disc_D5.0mm_W2.5mm_P2.50mm | 4 | Unpolarized ceramic capacitor
J1,J4,J5 | Conn_02x08_Odd_Even | MyLibrary2023:PinHeader_2x08_P2.54mm_Vertical | 3 | Generic connector, double row, 02x08, right angle
J2,J6 | Conn_01x03 | Connector_PinHeader_2.54mm:PinHeader_1x03_P2.54mm_Vertical | 2 | Generic connector, single row, 01x03
J3 | RCBus_80PIN_68000 | MyLibrary2023:RCBus_80p_Medium | 1 | Generic connector, double row, 02x40, right angle
J7,J12,J13 | Conn_01x08 | Connector_PinHeader_2.54mm:PinHeader_1x08_P2.54mm_Vertical | 3 | Generic connector, single row, 01x08
J8,J9,J10,J11 | Conn_02x04_Odd_Even | MyLibrary2023:PinHeader_2x04_P2.54mm_Vertical | 4 | Generic connector, double row, 02x04
J14 | Conn_02x03_Odd_Even | Connector_PinSocket_2.54mm:PinSocket_2x03_P2.54mm_Vertical | 1 | Generic connector, double row, 02x03, right angle
J15 | Conn_01x06 | Connector_PinSocket_2.54mm:PinSocket_1x06_P2.54mm_Vertical | 1 | Generic connector, single row, 01x06, right angle
U1,U2 | MC68230 | MyLibrary2023:DIP-48_W15.24mm_Socket | 2 | Parallel Interface / Timer
U3 | 74LS138 | Package_DIP:DIP-16_W7.62mm_Socket | 1 | Decoder 3 to 8 active low outputs
U4 | 74LS688 | MyLibrary2023:DIP-20_W7.62mm_Socket | 1 | 8-bit magnitude comparator

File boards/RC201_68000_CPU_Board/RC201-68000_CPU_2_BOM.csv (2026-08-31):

Reference | Value | Qty | Description
C1,C2,C3,C5,C6,C7,C8,C9,C10,C11,C12 | 100n | 11 | Unpolarized ceramic capacitor
D1,D2,D5 | BAT43 | 3 | 30V 0.2A Small Signal Schottky Diode, DO-35
D3,D4 | LED | 2 | Light emitting diode
J1 | Conn_02x04_Odd_Even | 1 | Generic connector, double row, 02x04
J2 | RCBus_80PIN_68000 | 1 | Generic connector, double row, 02x40, right angle
J3,J5,J6,J7 | Conn_01x03 | 4 | Generic connector, single row, 01x03
J4 | Conn_01x02 | 1 | Generic connector, single row, 01x02
R1,R2 | 1K | 2 | Resistor
RN1 | 4K7 | 1 | 8 resistor network, star topology, bussed resistors, small symbol
RN2 | 10K | 1 | 8 resistor network, star topology, bussed resistors, small symbol
U1 |  | 1
U2 | 74LS04 | 1 | Hex Inverter
U3 | 74LS148 | 1 | 8 line to 3 line priority encoder
U4 | 74LS20 | 1 | Dual 4-input NAND
U5 | 74LS139 | 1 | Dual Decoder 1 of 4, Active low outputs
U6,U8 | 74LS175 | 2 | 4-bit D Flip-Flop, reset
U7 | 74LS156 | 1 | Dual 2 to 4 lines Decoder/Demultiplexer, Open Collector
U9 | 74LS00 | 1 | quad 2-input NAND gate
X1 | 7.3728MHz | 1 | Crystal Clock Oscillator, DIP8-style metal package

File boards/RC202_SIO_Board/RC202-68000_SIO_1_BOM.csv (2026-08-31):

Reference | Value | Qty | Description
C1,C2,C3,C4,C5,C6,C7 | 100n | 7 | Unpolarized ceramic capacitor
D1 | LED | 1 | Light emitting diode
J1 | RCBus_80PIN_68000 | 1 | Generic connector, double row, 02x40, right angle
J2 | Conn_02x06_Odd_Even | 1 | Generic connector, double row, 02x06
J3,J4,J12,J14 | Conn_01x06 | 4 | Generic connector, single row, 01x06, right angle
J5,J9,J10,J15,J16 | Conn_02x02_Odd_Even | 5 | Generic connector, double row, 02x02
J6 | Conn_02x10_Odd_Even | 1 | Generic connector, double row, 02x10
J7,J8 | Conn_01x05 | 2 | Generic connector, single row, 01x05
J11 | Conn_01x04 | 1 | Generic connector, single row, 01x04
J13 | Conn_02x04_Odd_Even | 1 | Generic connector, double row, 02x04
JP1,JP2,JP3,JP4,JP6,JP7,JP8 | SolderJumper | 7 | Solder Jumper, 2-pole, open
R1 | 1K | 1 | Resistor
RN1 | 4K7 | 1 | 8 resistor network, star topology, bussed resistors, small symbol
U1 | 74LS138 | 1 | Decoder 3 to 8 active low outputs
U2 | SCC68692C1A44 | 1 | DUART + 8 Outputs & 6 Inputs
U3 | 74LS125 | 1 | Quad buffer 3-State outputs
U4 | 74LS688 | 1 | 8-bit magnitude comparator
U5 | 24LC128 | 1 | I2C Serial EEPROM, 128Kb, DIP-8
X1 | 3.6864MHz | 1 | Crystal Clock Oscillator, DIP8-style metal package
X2 | 1.0MHz | 1 | Crystal Clock Oscillator, DIP8-style metal package

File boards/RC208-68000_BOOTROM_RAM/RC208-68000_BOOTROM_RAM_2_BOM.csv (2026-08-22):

Reference | Value | Qty | Description
C1,C2,C3,C4,C5,C6,C7,C8,C9 | 100n | 9 | Unpolarized ceramic capacitor
J1 | RCBus_80PIN_68000 | 1 | Generic connector, double row, 02x40, right angle
J2 | Conn_02x03_Odd_Even | 1 | Generic connector, double row, 02x03, odd/even pin numbering scheme (row 1 odd numbers, row 2 even numbers), script generated (kicad-library-utils/schlib/autogen/connector/)
U1 | 74LS125 | 1 | Quad buffer 3-State outputs
U2 | 74LS139 | 1 | Dual Decoder 1 of 4, Active low outputs
U3,U4 | SST39SF040 | 2 | Silicon Storage Technology (SSF) 512k x 8 Flash ROM
U5 | 74LS138 | 1 | Decoder 3 to 8 active low outputs
U6,U7 | AS6C4008-55PCN | 2 | 512K x 8 Low Power CMOS RAM, DIP-32
U8 | 74LS165 | 1 | Shift Register 8-bit, parallel load
U9 | 74LS32 | 1 | Quad 2-input OR

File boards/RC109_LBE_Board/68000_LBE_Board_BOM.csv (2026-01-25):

Reference | Value | Datasheet | Footprint | Qty | Description
C2,C4,C5,C9,C10 | 100n | ~ | Capacitor_THT:C_Disc_D5.0mm_W2.5mm_P2.50mm | 5 | Unpolarized ceramic capacitor
D1,D2 | LED | ~ | LED_THT:LED_D3.0mm | 2 | Light emitting diode
J1 | Conn_02x04_Odd_Even | ~ | MyLibrary2023:PinHeader_2x04_P2.54mm_Vertical | 1 | Generic connector, double row, 02x04
J2 | Conn_01x04 | ~ | Connector_PinHeader_2.54mm:PinHeader_1x04_P2.54mm_Vertical | 1 | Generic connector, single row, 01x04, script generated (kicad-library-utils/schlib/autogen/connector/)
J3 | RCBus_80PIN_68000 | ~ | MyLibrary2023:RCBus_80p_Medium | 1 | Generic connector, double row, 02x20, right angle
J4 | Conn_02x02_Odd_Even | ~ | Connector_PinHeader_2.54mm:PinHeader_2x02_P2.54mm_Vertical | 1 | Generic connector, double row, 02x02
J5 | Conn_02x06_Odd_Even | ~ | Connector_PinHeader_2.54mm:PinHeader_2x06_P2.54mm_Horizontal | 1 | Generic connector, double row, 02x06, odd/even pin numbering scheme (row 1 odd numbers, row 2 even numbers), script generated (kicad-library-utils/schlib/autogen/connector/)
J6 | Conn_02x03_Odd_Even | ~ | Connector_PinHeader_2.54mm:PinHeader_2x03_P2.54mm_Horizontal | 1 | Generic connector, double row, 02x03, odd/even pin numbering scheme (row 1 odd numbers, row 2 even numbers), script generated (kicad-library-utils/schlib/autogen/connector/)
J8 | Conn_02x08_Odd_Even | ~ | Connector_PinHeader_2.54mm:PinHeader_2x08_P2.54mm_Horizontal | 1 | Generic connector, double row, 02x08, odd/even pin numbering scheme (row 1 odd numbers, row 2 even numbers), script generated (kicad-library-utils/schlib/autogen/connector/)
J12,J13,J18 | Conn_01x08 | ~ | MyLibrary2023:PinHeader_1x08_P2.54mm_Vertical | 3 | Generic connector, single row, 01x08
J15,J16,J17 | Conn_01x06 | ~ | Connector_PinSocket_2.54mm:PinSocket_1x06_P2.54mm_Horizontal | 3 | Generic connector, single row, 01x06, right angle
JP1,JP2,JP3,JP4,JP5,JP6 | SolderJumper | ~ | Jumper:SolderJumper-2_P1.3mm_Open_Pad1.0x1.5mm | 6 | Solder Jumper, 2-pole, open
R1 | 10K | ~ | Resistor_THT:R_Axial_DIN0207_L6.3mm_D2.5mm_P7.62mm_Horizontal | 1
R2,R3 | 1K | ~ | Resistor_THT:R_Axial_DIN0207_L6.3mm_D2.5mm_P7.62mm_Horizontal | 2 | Resistor
U1 | 68901P |  | Package_DIP:DIP-48_W15.24mm | 1 | Parallel Interface
U2 | 68681P |  | Package_DIP:DIP-40_W15.24mm_Socket | 1 | DUART
U6 | 74LS688 | http://www.ti.com/lit/gpn/sn74LS688 | MyLibrary2023:DIP-20_W7.62mm_Socket | 1 | 8-bit magnitude comparator
U7 | 74LS138 | http://www.ti.com/lit/gpn/sn74LS138 | Package_DIP:DIP-16_W7.62mm_Socket | 1 | Decoder 3 to 8 active low outputs
X1 | 3.6864MHz |  | Oscillator:Oscillator_DIP-8 | 1 | Crystal Clock Oscillator, DIP8-style metal package

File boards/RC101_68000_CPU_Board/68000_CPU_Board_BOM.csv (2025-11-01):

Reference | Value | Footprint | Qty | Description
C1,C2,C3,C5,C6,C7,C8,C9,C10,C11 | 100n | Capacitor_THT:C_Disc_D5.0mm_W2.5mm_P2.50mm | 10 | Unpolarized ceramic capacitor
D1,D2 | BAT43 | Diode_THT:D_DO-35_SOD27_P7.62mm_Horizontal | 2 | 30V 0.2A Small Signal Schottky Diode, DO-35
D3,D4,D5 | LED | LED_THT:LED_D3.0mm | 3 | Light emitting diode
J1 | Conn_02x04_Odd_Even | Connector_PinHeader_2.54mm:PinHeader_2x04_P2.54mm_Vertical | 1 | Generic connector, double row, 02x04
J2 | RCBus_80PIN_68000 | MyLibrary2023:RCBus_80p_Medium | 1 | Generic connector, double row, 02x40, right angle
J4 | Conn_01x02 | Connector_PinHeader_2.54mm:PinHeader_1x02_P2.54mm_Vertical | 1 | Generic connector, single row, 01x02
R1,R2,R3 | 1K | Resistor_THT:R_Axial_DIN0207_L6.3mm_D2.5mm_P7.62mm_Horizontal | 3 | Resistor
RN1 | 4K7 | Resistor_THT:R_Array_SIP9 | 1 | 8 resistor network, star topology, bussed resistors, small symbol
RN2 | 10K | Resistor_THT:R_Array_SIP9 | 1 | 8 resistor network, star topology, bussed resistors, small symbol
U1 | MC68000FN | Package_LCC:PLCC-68_THT-Socket | 1 | Microprocessor, 16-bit bus
U2 | 74LS125 | MyLibrary2023:DIP-14_W7.62mm_Socket | 1 | Quad buffer 3-State outputs
U3 | 74LS148 | Package_DIP:DIP-16_W7.62mm_Socket | 1 | 8 line to 3 line priority encoder
U4 | 74LS10 | Package_DIP:DIP-14_W7.62mm_Socket | 1 | Triple 3-input NAND
U5 | 74LS139 | Package_DIP:DIP-16_W7.62mm_Socket | 1 | Dual Decoder 1 of 4, Active low outputs
U6,U8 | 74LS175 | Package_DIP:DIP-16_W7.62mm_Socket | 2 | 4-bit D Flip-Flop, reset
U9 | 74LS00 | Package_DIP:DIP-14_W7.62mm_Socket | 1 | quad 2-input NAND gate
X1 | 7.3728MHz | Oscillator:Oscillator_DIP-8 | 1 | Crystal Clock Oscillator, DIP8-style metal package

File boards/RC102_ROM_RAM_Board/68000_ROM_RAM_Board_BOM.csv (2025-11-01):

Reference | Value | Datasheet | Footprint | Qty | Description
C1,C3,C4,C5,C6,C8,C9 | 100n | ~ | Capacitor_THT:C_Disc_D5.0mm_W2.5mm_P2.50mm | 7 | Unpolarized ceramic capacitor
J2 | RCBus_80PIN_68000 | ~ | MyLibrary2023:RCBus_80p_Medium | 1 | Generic 02x40 pin connector, right angle
U1 | 74LS125 | http://www.ti.com/lit/gpn/sn74LS125 | Package_DIP:DIP-14_W7.62mm | 1 | Quad buffer 3-State outputs
U3,U6 | W27C512 |  | Package_DIP:DIP-28_W15.24mm | 2 | EEPROM 64K x 8 DIP28
U4,U5 | AS6C4008-55PCN | https://www.alliancememory.com/wp-content/uploads/pdf/AS6C4008.pdf | Package_DIP:DIP-32_W15.24mm | 2 | 512K x 8 Low Power CMOS RAM, DIP-32
U8 | 74LS138 | http://www.ti.com/lit/gpn/sn74LS138 | Package_DIP:DIP-16_W7.62mm | 1 | Decoder 3 to 8 active low outputs
U9 | 74LS139 | http://www.ti.com/lit/ds/symlink/sn74ls139a.pdf | Package_DIP:DIP-16_W7.62mm | 1 | Dual Decoder 1 of 4, Active low outputs

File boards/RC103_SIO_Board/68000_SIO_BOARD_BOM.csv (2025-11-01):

Reference | Value | Datasheet | Footprint | Qty | Description
C1,C2,C3,C4,C7 | 100n | ~ | Capacitor_THT:C_Disc_D5.0mm_W2.5mm_P2.50mm | 5 | Unpolarized ceramic capacitor
J1,J9,J11 | Conn_01x08 | ~ | Connector_PinHeader_2.54mm:PinHeader_1x08_P2.54mm_Vertical | 3 | Generic connector, single row, 01x08
J2,J5,J7,J8 | Conn_01x06 | ~ | Connector_PinSocket_2.54mm:PinSocket_1x06_P2.54mm_Horizontal | 4 | Generic connector, single row, 01x06, right angle
J3,J6 | Conn_01x03 | ~ | Connector_PinHeader_2.54mm:PinHeader_1x03_P2.54mm_Vertical | 2 | Generic connector, single row, 01x03
J4 | Conn_02x10_Odd_Even | ~ | Connector_PinHeader_2.54mm:PinHeader_2x10_P2.54mm_Horizontal | 1 | Generic connector, double row, 02x10, right angle
J10 | Conn_02x08_Odd_Even | ~ | Connector_PinHeader_2.54mm:PinHeader_2x08_P2.54mm_Horizontal | 1 | Generic connector, double row, 02x08, right angle
J12 | Conn_02x04_Odd_Even | ~ | Connector_PinHeader_2.54mm:PinHeader_2x04_P2.54mm_Vertical | 1 | Generic connector, double row, 02x04
J14 | Conn_02x02_Odd_Even | ~ | Connector_PinHeader_2.54mm:PinHeader_2x02_P2.54mm_Vertical | 1 | Generic connector, double row, 02x02
J15 | RCBus_80PIN_68000 | ~ | MyLibrary2023:RCBus_80p_Medium | 1 | Generic connector, double row, 02x40, right angle
JP1,JP2,JP3,JP4,JP5,JP6,JP7,JP8 | SolderJumper | ~ | Jumper:SolderJumper-2_P1.3mm_Open_Pad1.0x1.5mm | 8 | Solder Jumper, 2-pole, open
R1 | 10K | ~ | Resistor_THT:R_Axial_DIN0207_L6.3mm_D2.5mm_P7.62mm_Horizontal | 1 | Resistor
U1 | 74LS138 | http://www.ti.com/lit/gpn/sn74LS138 | Package_DIP:DIP-16_W7.62mm_Socket | 1 | Decoder 3 to 8 active low outputs
U2,U3 | 68681P |  | Package_DIP:DIP-40_W15.24mm_Socket | 2 | DUART
U4 | 74LS688 | http://www.ti.com/lit/gpn/sn74LS688 | MyLibrary2023:DIP-20_W7.62mm_Socket | 1 | 8-bit magnitude comparator
X1 | 3.6864MHz | http://cdn-reichelt.de/documents/datenblatt/B400/OSZI.pdf | Oscillator:Oscillator_DIP-8 | 1 | Crystal Clock Oscillator, DIP8-style metal package

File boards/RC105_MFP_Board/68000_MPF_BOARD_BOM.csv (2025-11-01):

Reference | Value | Datasheet | Footprint | Qty | Description
C2,C3,C4,C5,C7 | 100n | ~ | Capacitor_THT:C_Disc_D5.0mm_W2.5mm_P2.50mm | 5 | Unpolarized ceramic capacitor
J2,J5 | Conn_02x04_Odd_Even | ~ | Connector_PinHeader_2.54mm:PinHeader_2x04_P2.54mm_Vertical,MyLibrary2023:PinHeader_2x04_P2.54mm_Vertical | 2 | Generic connector, double row, 02x04,Generic connector, double row, 02x04, right angle
J3 | Conn_01x03 | ~ | MyLibrary2023:PinHeader_1x03_P2.54mm_Vertical | 1 | Generic connector, single row, 01x03
J4 | Conn_02x09_Odd_Even | ~ | Connector_PinHeader_2.54mm:PinHeader_2x09_P2.54mm_Vertical | 1 | Generic connector, double row, 02x09, right angle
J6 | Conn_02x02_Odd_Even | ~ | Connector_PinHeader_2.54mm:PinHeader_2x02_P2.54mm_Vertical | 1 | Generic connector, double row, 02x02
J7,J8 | Conn_01x06 | ~ | Connector_PinSocket_2.54mm:PinSocket_1x06_P2.54mm_Horizontal | 2 | Generic connector, single row, 01x06, right angle
J9,J11,J12 | Conn_01x08 | ~ | MyLibrary2023:PinHeader_1x08_P2.54mm_Vertical | 3 | Generic connector, single row, 01x08
J14 | Conn_02x03_Odd_Even | ~ | Connector_PinHeader_2.54mm:PinHeader_2x03_P2.54mm_Vertical | 1 | Generic connector, double row, 02x03, right angle
J15 | RCBus_80PIN_68000 | ~ | MyLibrary2023:RCBus_80p_Medium | 1 | Generic connector, double row, 02x20, right angle
JP1,JP2,JP3,JP4 | SolderJumper | ~ | Jumper:SolderJumper-2_P1.3mm_Open_Pad1.0x1.5mm | 4 | Solder Jumper, 2-pole, open
R1 | 10K | ~ | Resistor_THT:R_Axial_DIN0207_L6.3mm_D2.5mm_P7.62mm_Horizontal | 1
U2 | 74LS138 | http://www.ti.com/lit/gpn/sn74LS138 | Package_DIP:DIP-16_W7.62mm_Socket | 1 | Decoder 3 to 8 active low outputs
U4,U5 | 68901P |  | MyLibrary2023:DIP-48_W15.24mm_Socket | 2 | Multi-function peripheral device
U6 | 74LS688 | http://www.ti.com/lit/gpn/sn74LS688 | MyLibrary2023:DIP-20_W7.62mm_Socket | 1 | 8-bit magnitude comparator
X1 | CXO_DIP8 | http://cdn-reichelt.de/documents/datenblatt/B400/OSZI.pdf | Oscillator:Oscillator_DIP-8 | 1 | Crystal Clock Oscillator, DIP8-style metal package

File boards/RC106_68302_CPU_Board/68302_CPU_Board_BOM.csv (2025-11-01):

Reference | Value | Datasheet | Footprint | Qty | Description
C1,C2,C3,C4,C5,C6,C7,C8,C9,C10,C11,C12,C13 | 100n | ~ | Capacitor_THT:C_Disc_D5.0mm_W2.5mm_P2.50mm | 13 | Unpolarized ceramic capacitor
D1,D2 | BAT43 | http://www.vishay.com/docs/85660/bat42.pdf | Diode_THT:D_DO-35_SOD27_P7.62mm_Horizontal | 2 | 30V 0.2A Small Signal Schottky Diode, DO-35
D3,D4,D5,D6 | LED | ~ | LED_THT:LED_D3.0mm | 4 | Light emitting diode
J1 | Conn_01x02 | ~ | Connector_PinHeader_2.54mm:PinHeader_1x02_P2.54mm_Vertical | 1 | Generic connector, single row, 01x02
J2 | RCBus_80PIN_68000 | ~ | MyLibrary2023:RCBus_80p_Medium | 1 | Generic connector, double row, 02x40, right angle
J3 | Conn_01x03 | ~ | Connector_PinHeader_2.54mm:PinHeader_1x03_P2.54mm_Vertical | 1 | Generic connector, single row, 01x03
J4,J5,J6 | Conn_01x06 | ~ | Connector_PinSocket_2.54mm:PinSocket_1x06_P2.54mm_Horizontal | 3 | Generic connector, single row, 01x06
R1,R2,R3,R4 | 1K | ~ | Resistor_THT:R_Axial_DIN0207_L6.3mm_D2.5mm_P7.62mm_Horizontal | 4 | Resistor
RN1 | 4K7 | http://www.vishay.com/docs/31509/csc.pdf | Resistor_THT:R_Array_SIP9 | 1 | 8 resistor network, star topology, bussed resistors, small symbol
RN2 | 10K | http://www.vishay.com/docs/31509/csc.pdf | Resistor_THT:R_Array_SIP9 | 1 | 8 resistor network, star topology, bussed resistors, small symbol
U1 | 74LS10 | http://www.ti.com/lit/gpn/sn74LS10 | MyLibrary2023:DIP-14_W7.62mm_Socket | 1 | Triple 3-input NAND
U2 | 74LS139 | http://www.ti.com/lit/ds/symlink/sn74ls139a.pdf | MyLibrary2023:DIP-16_W7.62mm_Socket | 1 | Dual Decoder 1 of 4, Active low outputs
U3 | 74LS125 | http://www.ti.com/lit/gpn/sn74LS125 | MyLibrary2023:DIP-14_W7.62mm_Socket | 1 | Quad buffer 3-State outputs
U4 | 68302RC |  | MyLibrary2023:PGA132 | 1 | 16/32-bit Microprocessor, 8-bit databus
U5 | 74LS148 | http://www.ti.com/lit/gpn/sn74LS148 | MyLibrary2023:DIP-16_W7.62mm_Socket | 1 | Priority Encoder 3 to 8 cascadable
X1 | 7.3728MHz | http://cdn-reichelt.de/documents/datenblatt/B400/OSZI.pdf | Oscillator:Oscillator_DIP-8 | 1 | Crystal Clock Oscillator, DIP8-style metal package

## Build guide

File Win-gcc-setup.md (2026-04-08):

# Setting up the GNU C Compiler environment

The steps outlined below are my notes on how I set up a Windows 10 (or Windows 11) development environment so I could write C code and compile and run it on my RCBus 68000 hardware.

# What software is required

In order to develop applications, I am currently using the following software:
- GCC68K v13.1.0 - available from: https://tranaptic.ca/gcc-downloads
- Setup batch file - also available from: https://tranaptic.ca/gcc-downloads
- Notepad++ - available from: https://notepad-plus-plus.org/downloads/

I use Notepad++ as my editor but there are plenty of other options out there.

# Setting up
## Step 1 - Install the M68K GCC cross compiler

I downloaded the file `MinGW-m68k-elf-13.1.0.zip` from the Tranaptic website link above.

I then created a folder in the root of my D drive called `gcc68k-13.1.0` and then extracted the contents of the zip file into the `gcc68k-13.1.0` folder making sure to keep the folder structure.

## Step 2 - Configure the setup file

I downloaded the file `setup.bat` from the same Tranaptic website link above and then edited it for my specific needs as I'm only interested in building for the 68000 processor.

My `setup.bat` file then looked like this:
```
@echo off

set GCC_INSTALL_DIR=d:\gcc68k_13.1.0

set GCC_VERSION=13.1.0
set TARGET_VERSION=-%GCC_VERSION%
set LIBDIR_VERSION=%GCC_VERSION%
set LIBDIR_SUFFIX=m68000

set SHTITLE=M68K
set target_gcc=m68k-elf

set LIBCDIR=%GCC_INSTALL_DIR%\%target_gcc%\lib\%LIBDIR_SUFFIX%
set LIBDIR=%GCC_INSTALL_DIR%\lib\gcc\%target_gcc%\%LIBDIR_VERSION%\%LIBDIR_SUFFIX%

PATH=%PATH%;%GCC_INSTALL_DIR%\bin
title GCC(%GCC_VERSION%) - %SHTITLE%
```

## Step 3 - Creating a root folder

I created a separate folder in the root of my D: drive called `gcc68k`. This will be my root development folder. The intention is to do all the development work in subfolders of this folder.

## Step 4 - Copy the repository files

Take the contents of the c_code repository folder and copy the lot into the root development folder which is `D:\gcc68k` for me. This should give you a folder structure similar to this:
```
D:\gcc68k
  +- crt
  +- fdlibm
  +- include
  +- libs
  +- libc
  +- SC611_SPI_Read_Write
  +- SC704_I2C_Read_Write
  +- SC704_I2C_Scan
  +- simple_hello
  +- TMS9918A_ASCII_Chars
  +- TMS9918A_Fern
  +- TMS9918A_Nyan
  +- TMS9918A_Sprite
  +- V9958_Dots
  +- V9958_Lines
  \- V9958_Mbrot
```
It should also give you 2 files in the root development folder. The `rc68000.ld` file describes the memory layout for the linker.

The python script `gcc2easy.py` is something I created and it is called by some of the makefiles when the command `make simlist` is given. It will generate a listing file that should be compatible with the SIM68K program that is supplied as part of the EASy68K suite. This should allow you to step through a C (or C++) program using SIM68K.

# First Use
## Step 1 - Build the C runtime crt0

This simple piece of code is required by all the C programs and is built by simply issuing the `make` command from a CMD prompt within the `crt` folder. This should create the file `crt.o` in the crt folder. 

## Step 2 - Build a simple libc

Having tried several times to build Newlib and failed, I decided to abandon it and create my own libc library. My libc is a cut down version of the standard C library and has a few basic functions present. Most of these are based on the source code provided in the book "The Standard C Library" by P.J.Plauger.
 
The library is built by simply issuing the `make` command from a CMD prompt within the `libc` folder. This should generate the file `libc.a` which should then be copied into the `libs` folder.

## Step 3 - Build a simple libm

The mathematical functions I am using are handled by the maths library FDLIBM (Freely Distributable LIBM) version 5.3.

The library is built by simply issuing the `make` command from a CMD prompt within the `fdlibm` folder. This should generate the file `libm.a` which should then be copied into the `libs` folder.

Note: The compilation process will generate a lot of warnings of the type: "dereferencing type-punned pointer will break strict-aliasing rules". This seems to be due to the way the library code is trying to  manipulate IEEE 754 bit representations.

# All Set!

That's it. You should now have an environment setup to develop C programs for the 68000 directly from the Windows CMD prompt.

Remeber to run the `SETUP.BAT` file each time you open up a CMD prompt so the compiler executables can be found.

# But finally some notes

1. I'm just starting out with cross compiling using GCC so there will likely be some methods that I'm using that are inefficient or just plain wrong!

2. One thing I have discovered is that, for me at least, inline assembly is rather hit and miss and ultimately just a pain in the backside as I chase down obscure error messages. I've found it much easier to have a separate assembler source file and call the routines from the C code.

3. The development environment is Windows so be aware that some Linux commands that are used in makefiles do not exist in Windows or have their Windows equivalents.

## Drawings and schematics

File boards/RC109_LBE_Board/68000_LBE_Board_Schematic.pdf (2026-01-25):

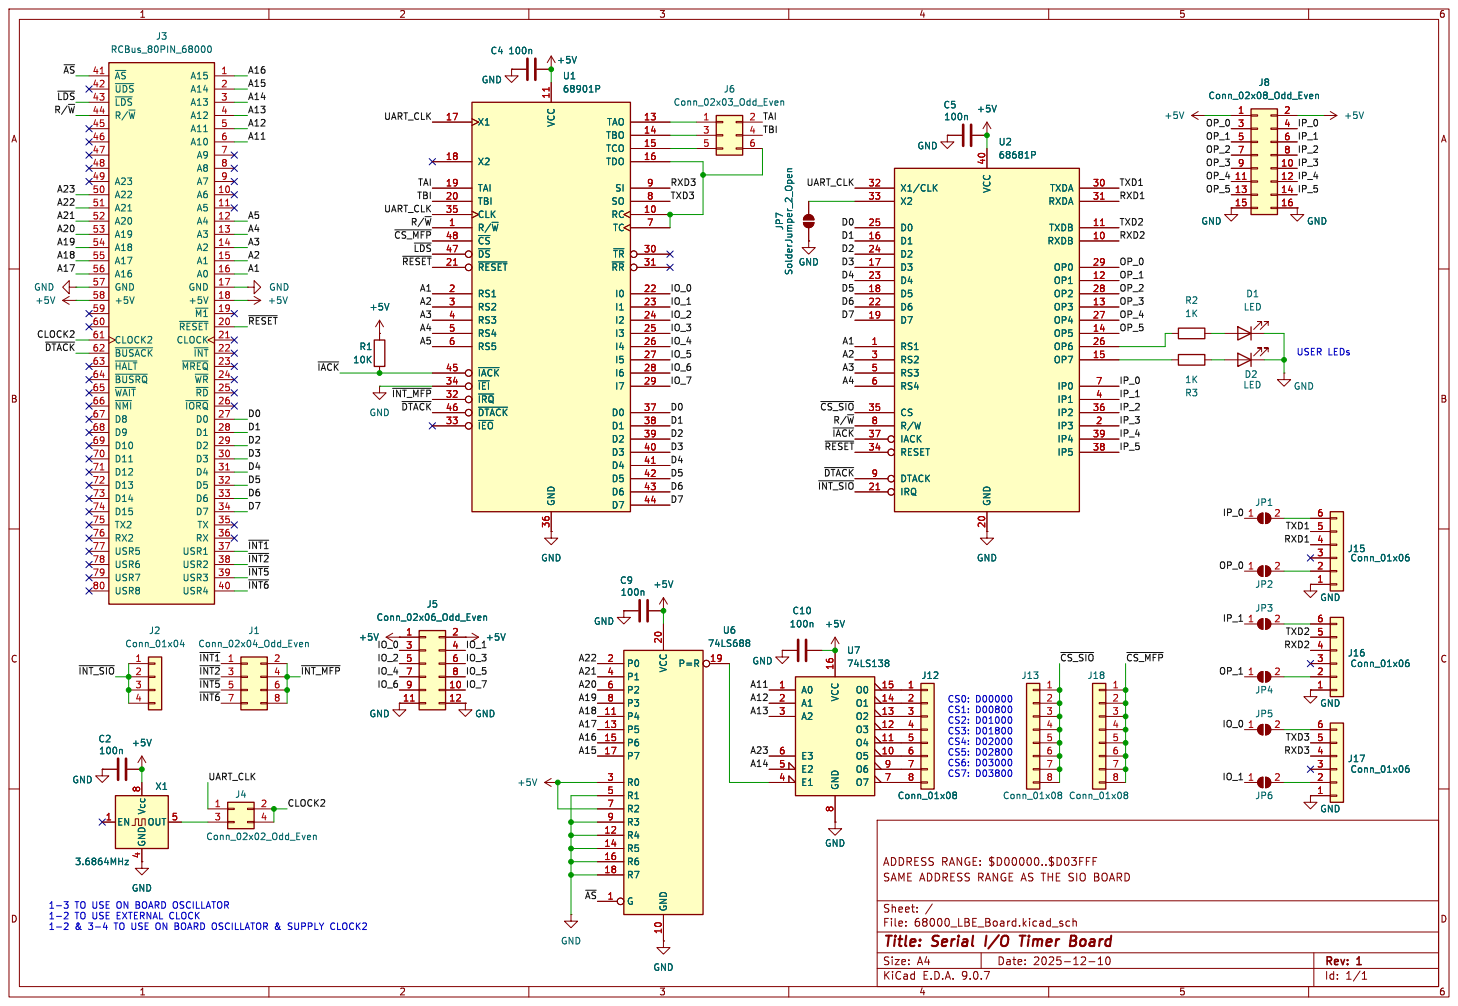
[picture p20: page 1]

60 CLOCK2 61 ~{BUSACK} 62 ~{HALT} 63 ~{BUSRQ} 64 ~{WAIT} 65 ~{NMI} 66 D8 67 D9 68 D10 69 D11 70 D12 71 D13 72 D14 73 D15 74 TX2 75 RX2 76 USR5 77 USR6 78 USR7 79 USR8 80

Id: 1/1 Title: Serial I/O Timer Board

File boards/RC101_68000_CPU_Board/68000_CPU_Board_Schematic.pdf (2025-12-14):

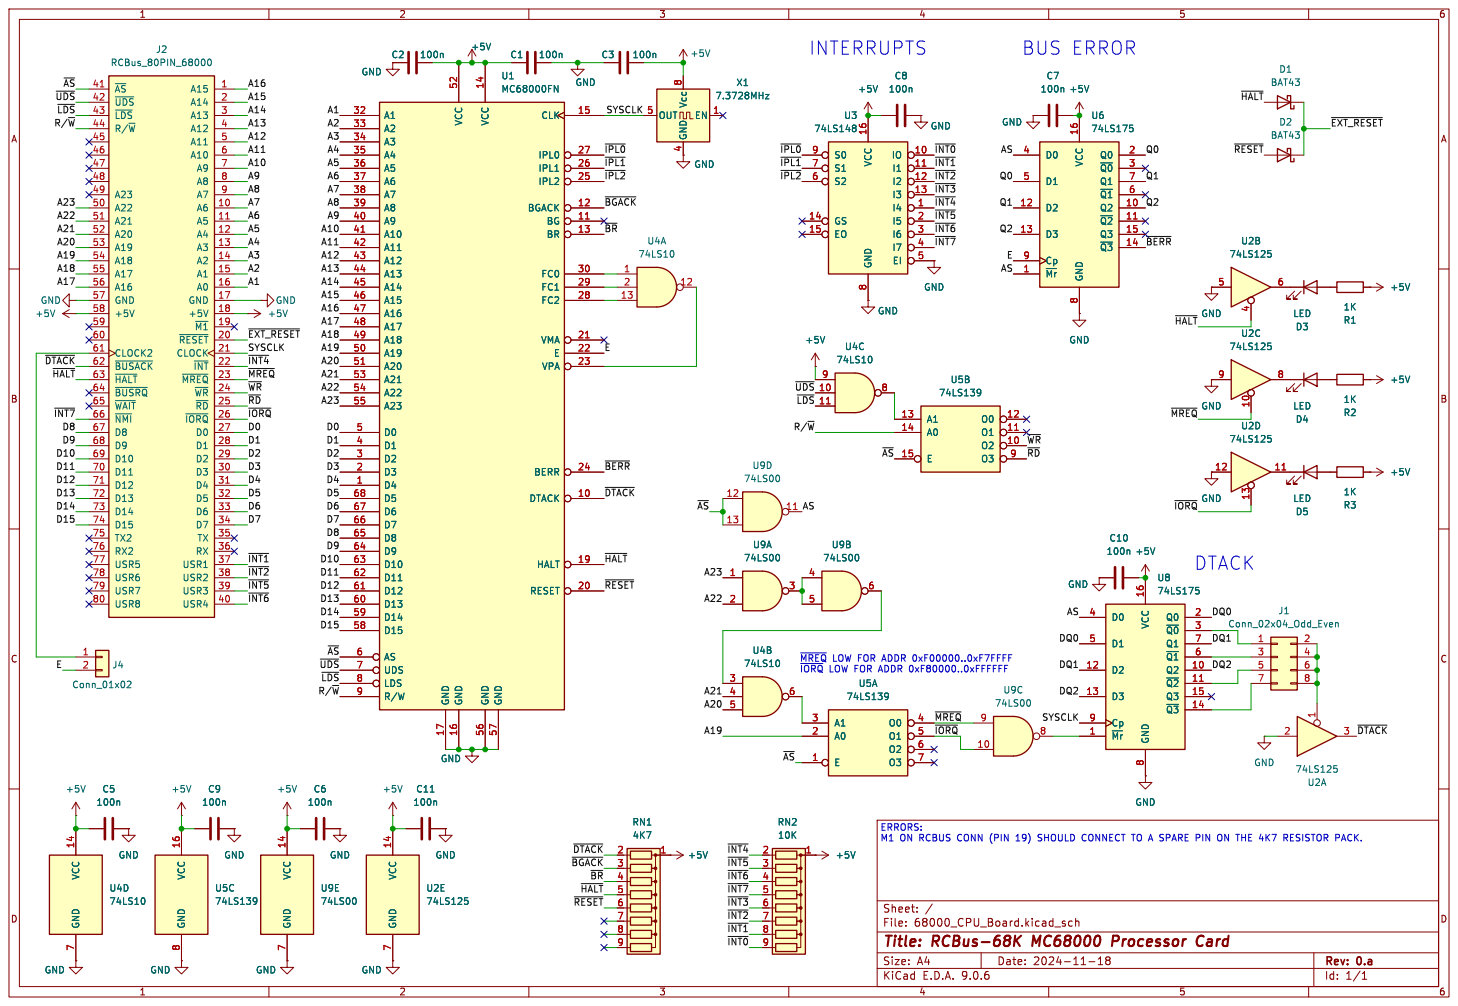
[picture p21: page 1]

ERRORS: M1 ON RCBUS CONN (PIN 19) SHOULD CONNECT TO A SPARE PIN ON THE 4K7 RESISTOR PACK. BUS ERROR

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

~{MREQ}LOW FOR ADDR 0xF00000..0xF7FFFF
~{IORQ}LOW FOR ADDR 0xF80000..0xFFFFFF

7 GND GND GND GND

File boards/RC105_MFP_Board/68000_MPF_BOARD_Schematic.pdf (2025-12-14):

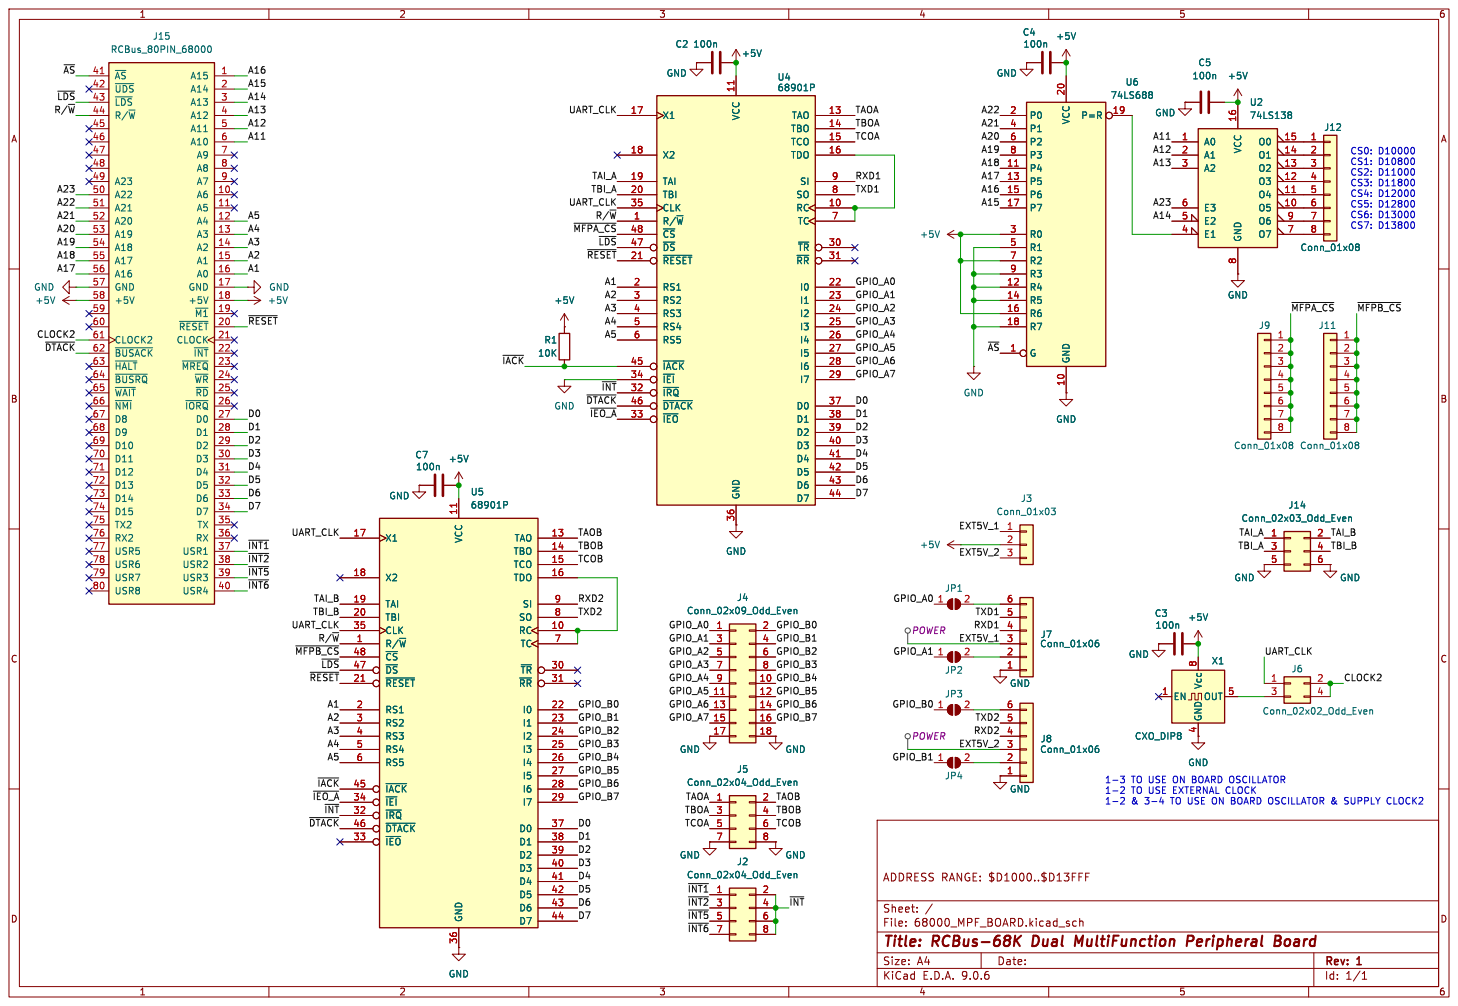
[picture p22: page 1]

8 O0 15 O1 14 O2 13 O3 12 O4 11 O5 10 O6 9 O7 7 U2 GND 74LS138 C2 100n C5 GND 100n X1 17 X2 18 TAI 19 TBI 20 CLK 35 R/~{W} 1 ~{CS} 48 ~{DS} 47 ~{RESET} 21 RS1 2 RS2 3 RS3 4 RS4 5 RS5 6 ~{IACK} 45 ~{IEI} 34 ~{IRQ} 32 ~{DTACK} 46 ~{IEO} 33 VCC 11 GND 36 TAO 13 TBO 14 TCO 15 TDO 16 SI 9 SO 8 RC 10 TC 7 ~{TR} 30 ~{RR} 31

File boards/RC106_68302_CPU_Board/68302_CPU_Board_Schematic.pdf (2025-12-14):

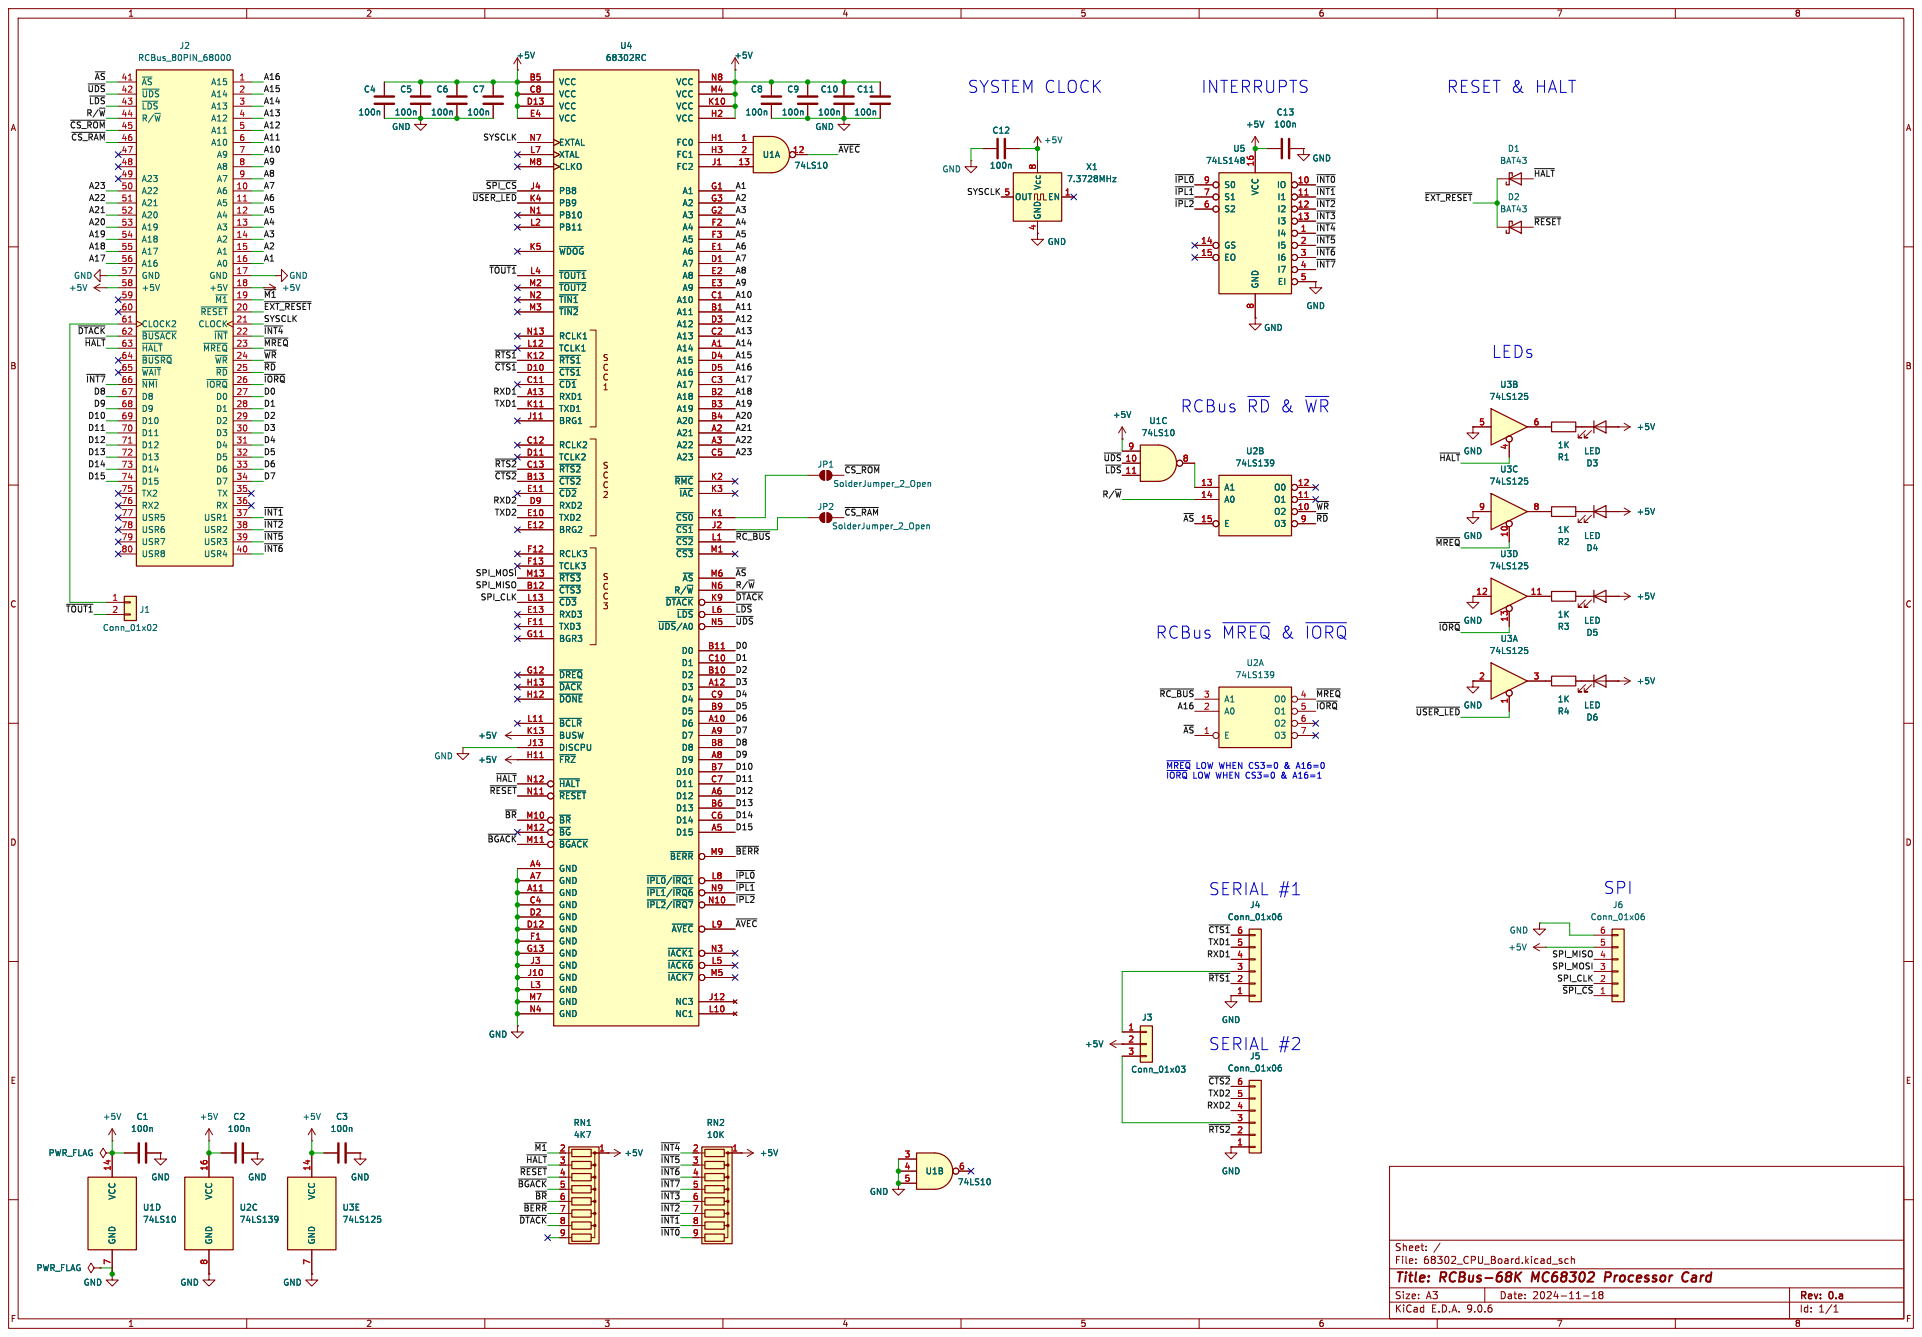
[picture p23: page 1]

74LS125 GND GND GND
60 CLOCK2 61 ~{BUSACK} 62 ~{HALT} 63 ~{BUSRQ} 64 ~{WAIT} 65 ~{NMI} 66 D8 67 D9 68 D10 69 D11 70 D12 71 D13 72 D14 73 D15 74 TX2 75 RX2 76 USR5 77 USR6 78 USR7 79 USR8 80

~{MREQ}LOW WHEN CS3=0 & A16=0 ~{IORQ}LOW WHEN CS3=0 & A16=1 RCBus ~{MREQ}& ~{IORQ}

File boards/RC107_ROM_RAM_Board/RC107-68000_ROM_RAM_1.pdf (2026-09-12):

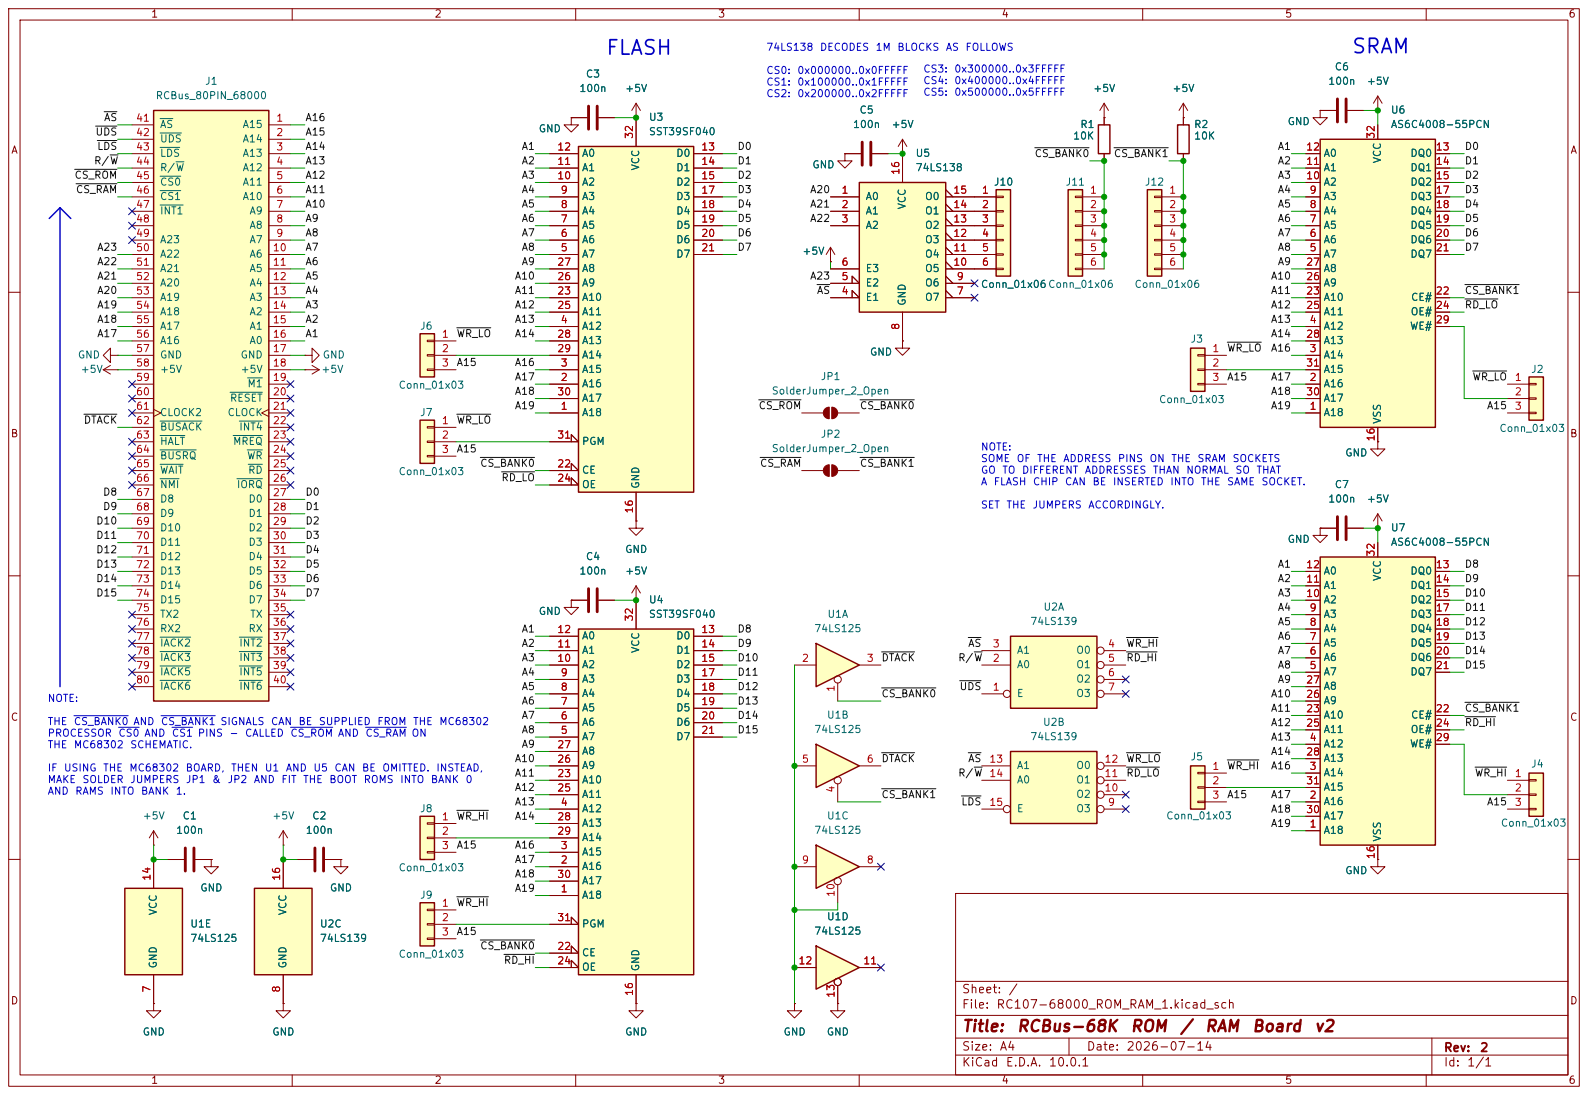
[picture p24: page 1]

CS3: 0x300000..0x3FFFFF CS4: 0x400000..0x4FFFFF CS5: 0x500000..0x5FFFFF NOTE: SOME OF THE ADDRESS PINS ON THE SRAM SOCKETS GO TO DIFFERENT ADDRESSES THAN NORMAL SO THAT A FLASH CHIP CAN BE INSERTED INTO THE SAME SOCKET. SET THE JUMPERS ACCORDINGLY. 74LS138 DECODES 1M BLOCKS AS FOLLOWS CS0: 0x000000..0x0FFFFF CS1: 0x100000..0x1FFFFF CS2: 0x200000..0x2FFFFF NOTE: THE CS_BANK0 AND CS_BANK1 SIGNALS CAN BE SUPPLIED FROM THE MC68302 PROCESSOR CS0 AND CS1 PINS - CALLED CS_ROM AND CS_RAM ON

IF USING THE MC68302 BOARD, THEN U1 AND U5 CAN BE OMITTED. INSTEAD, MAKE SOLDER JUMPERS JP1 & JP2 AND FIT THE BOOT ROMS INTO BANK 0

AND RAMS INTO BANK 1.

File: RC107-68000_ROM_RAM_1.kicad_sch
Title: RCBus-68K ROM / RAM Board v2

Size: A4 | Rev: 2
KiCad E.D.A. 10.0.1 | Id: 1/1

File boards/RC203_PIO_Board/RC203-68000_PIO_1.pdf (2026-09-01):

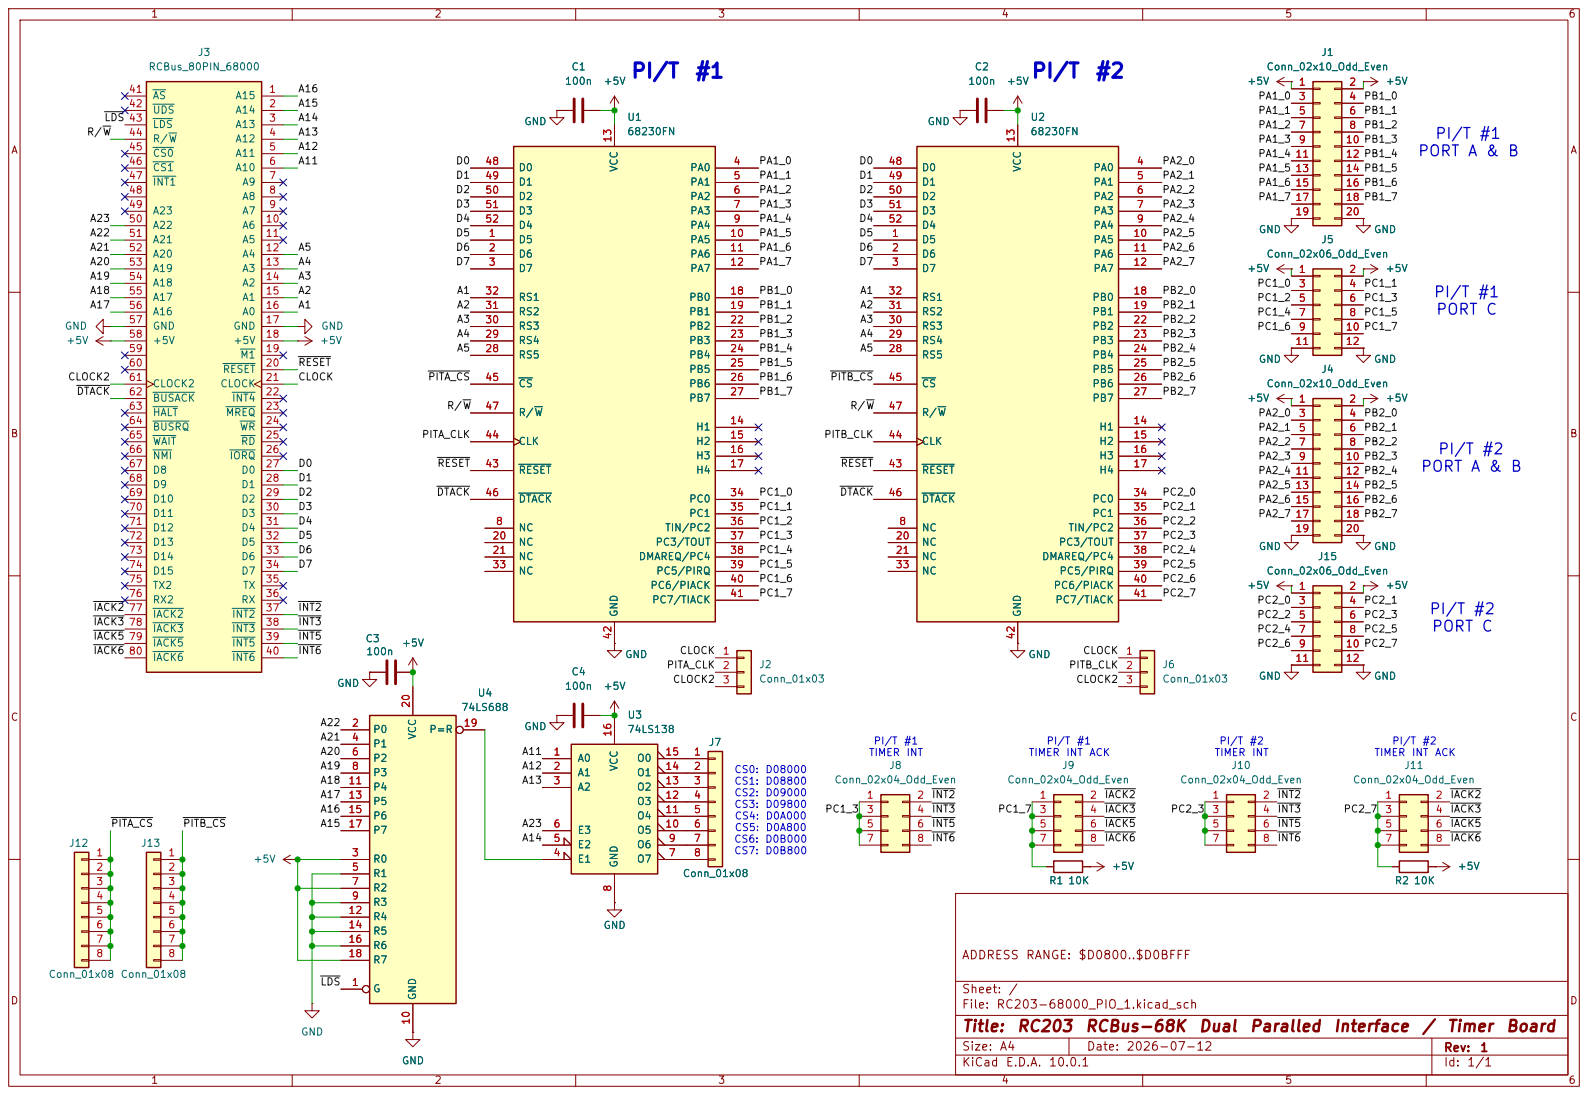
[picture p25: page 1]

Sheet: /
File: RC203-68000_PIO_1.kicad_sch
Title: RC203 RCBus-68K Dual Paralled Interface / Timer Board

Size: A4 | Rev: 1
KiCad E.D.A. 10.0.1 | Id: 1/1

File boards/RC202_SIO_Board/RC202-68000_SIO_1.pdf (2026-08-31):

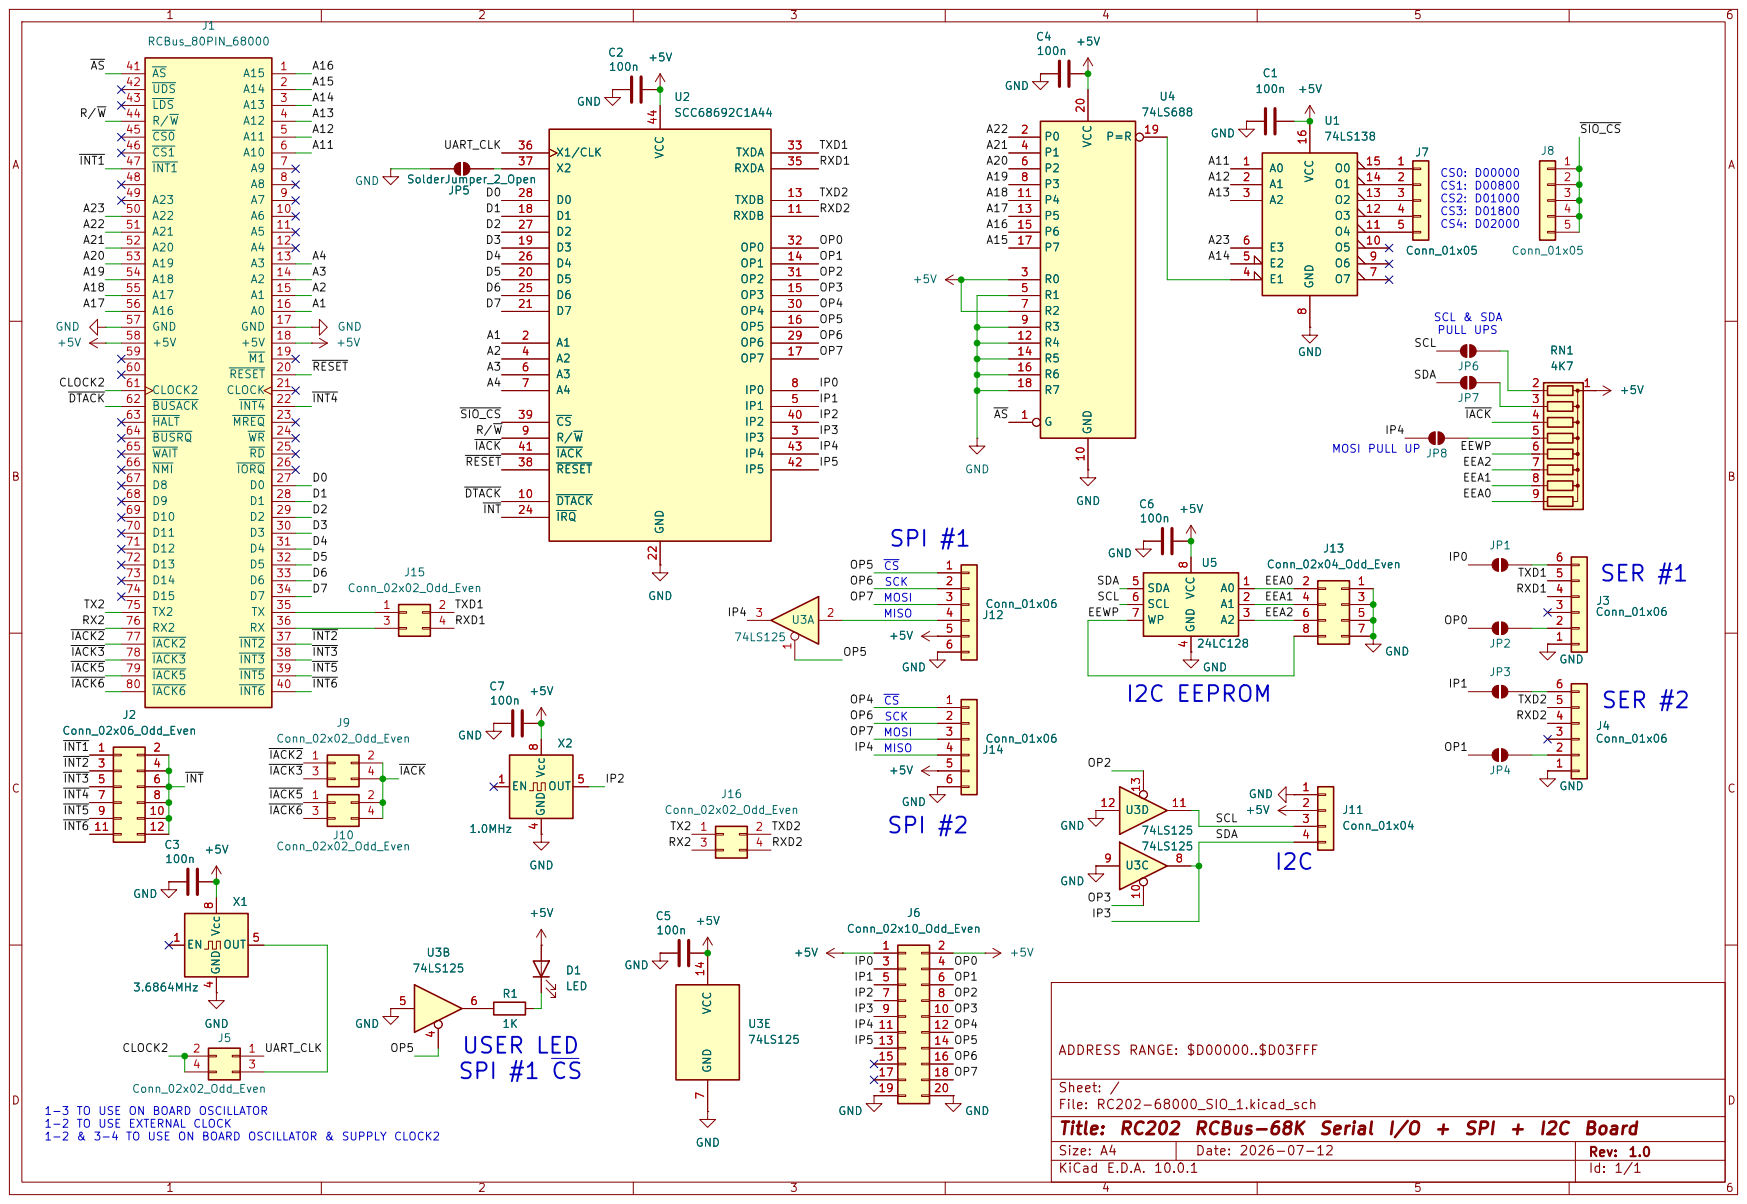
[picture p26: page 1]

SCL & SDA PULL UPS MOSI MISO

EEA2 6 6 | 5 5

Sheet: /
File: RC202-68000_SIO_1.kicad_sch
Title: RC202 RCBus-68K Serial I/O + SPI + I2C Board

1-3 TO USE ON BOARD OSCILLATOR
1-2 TO USE EXTERNAL CLOCK

Size: A4 | Rev: 1.0
KiCad E.D.A. 10.0.1 | Id: 1/1

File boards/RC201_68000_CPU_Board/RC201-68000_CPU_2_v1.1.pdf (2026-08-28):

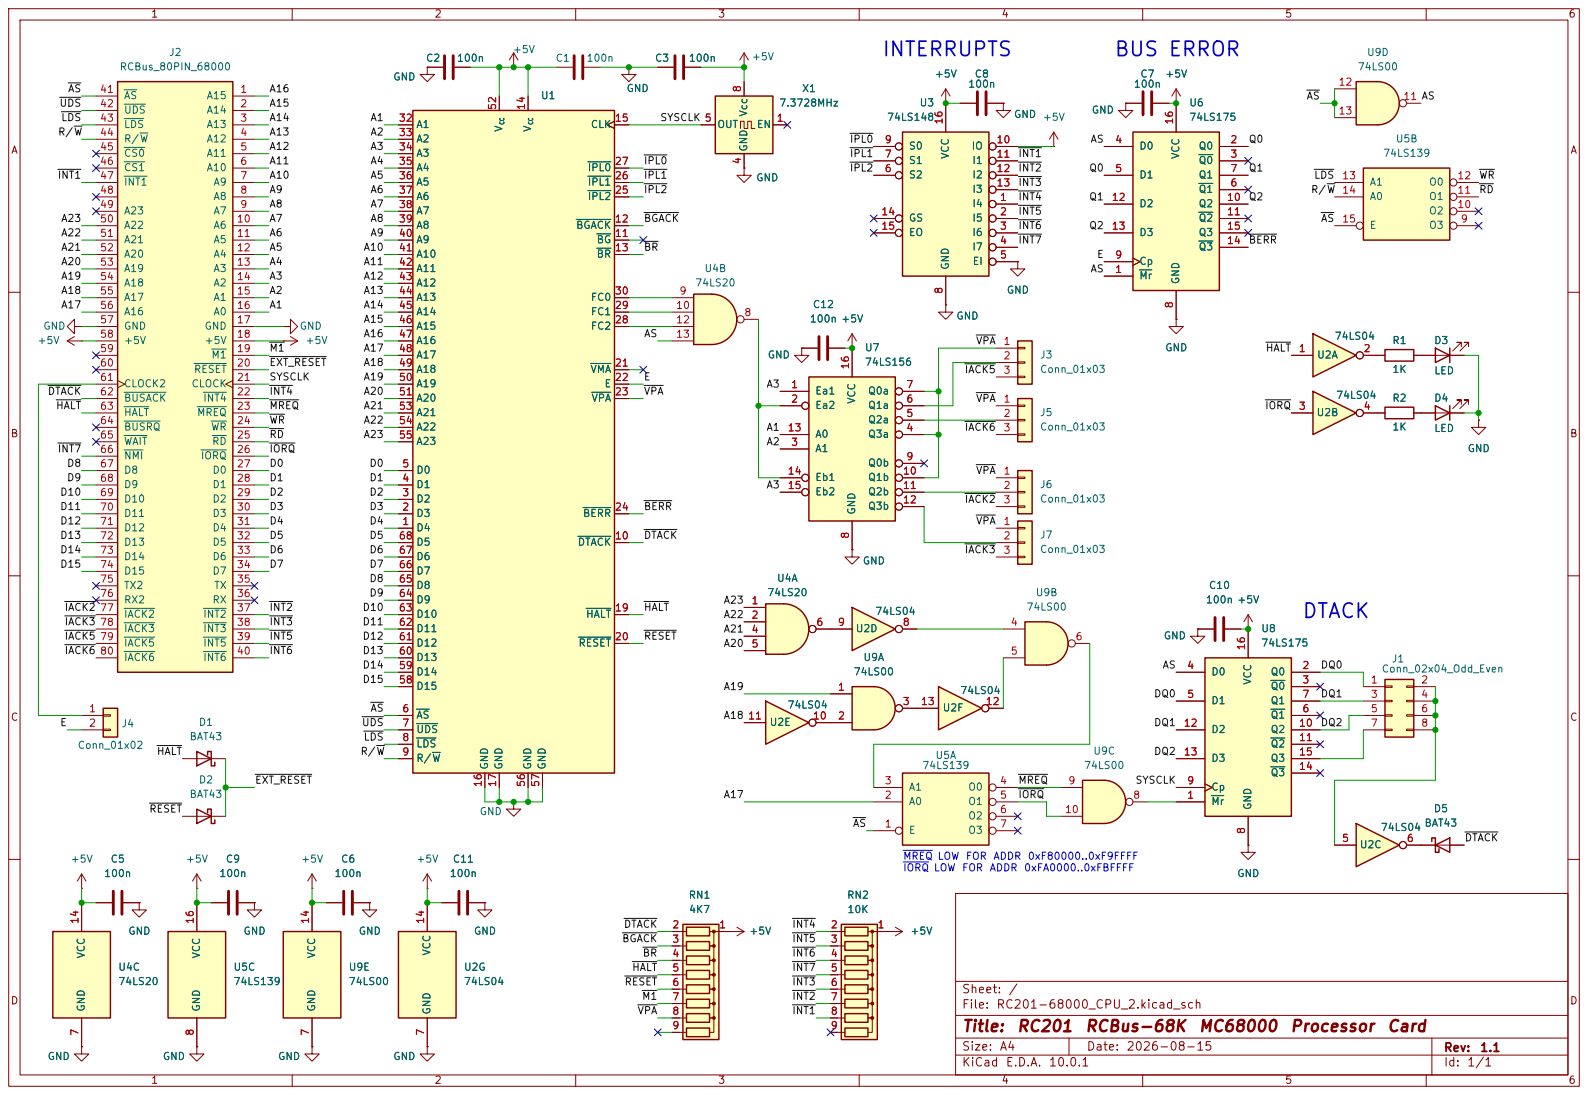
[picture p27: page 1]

V CC 14 CLK 15 GND 16 GND 17 HALT 19 RESET 20

MREQ LOW FOR ADDR 0xF80000..0xF9FFFF
IORQ LOW FOR ADDR 0xFA0000..0xFBFFFF

Sheet: /
File: RC201-68000_CPU_2.kicad_sch
Title: RC201 RCBus-68K MC68000 Processor Card

Size: A4 | Rev: 1.1
KiCad E.D.A. 10.0.1 | Id: 1/1

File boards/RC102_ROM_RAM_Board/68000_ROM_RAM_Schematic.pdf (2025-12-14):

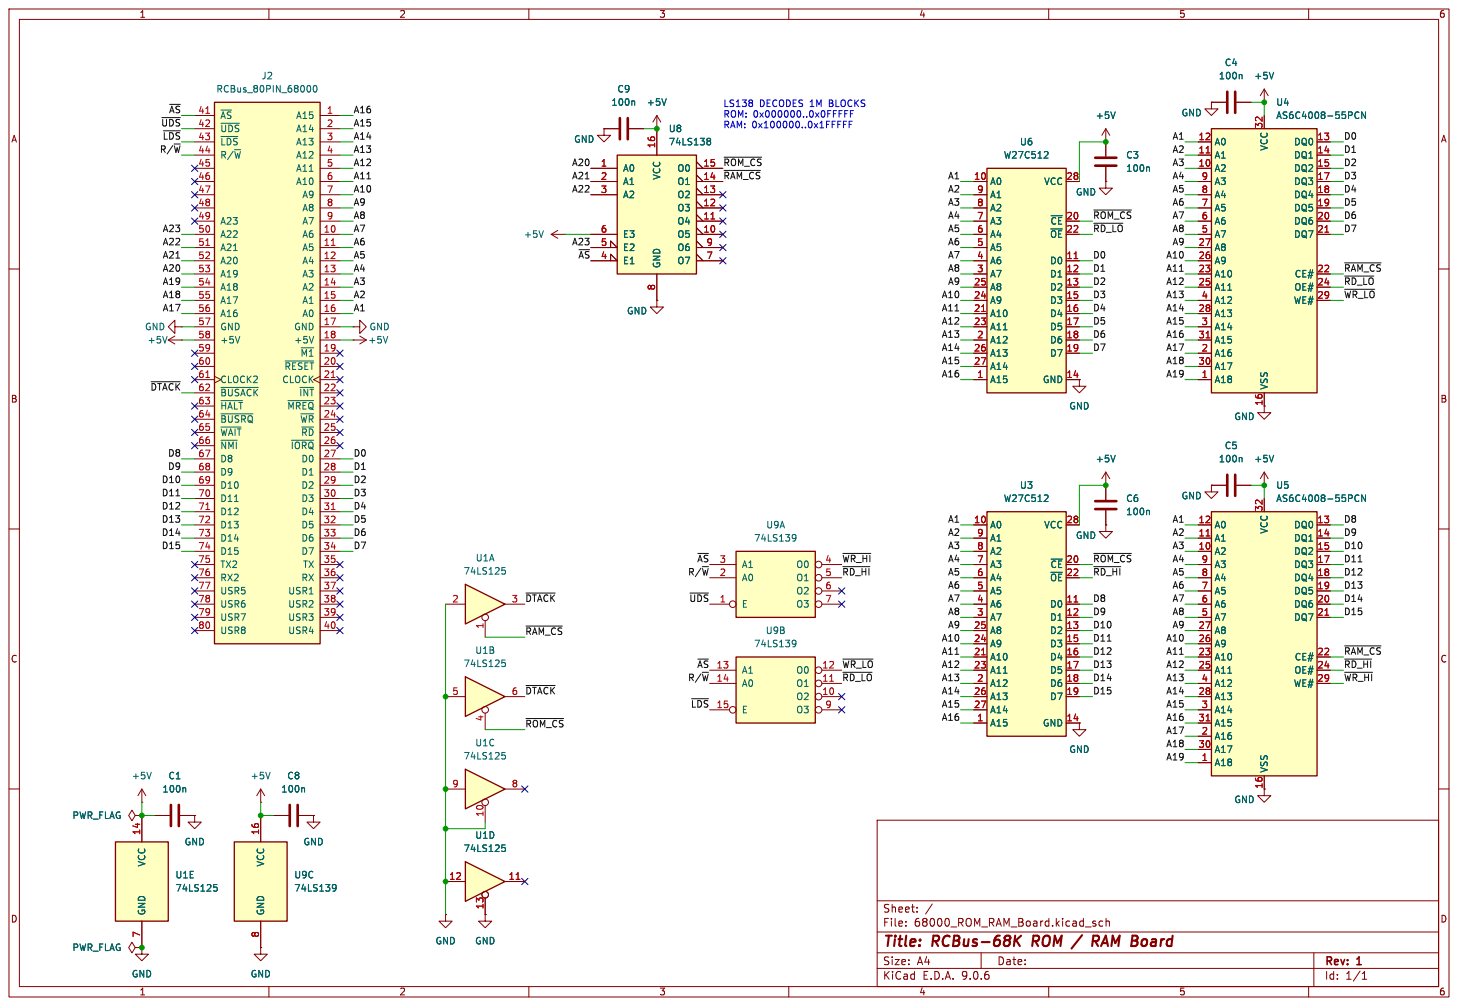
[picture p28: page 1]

LS138 DECODES 1M BLOCKS ROM: 0x000000..0x0FFFFF RAM: 0x100000..0x1FFFFF

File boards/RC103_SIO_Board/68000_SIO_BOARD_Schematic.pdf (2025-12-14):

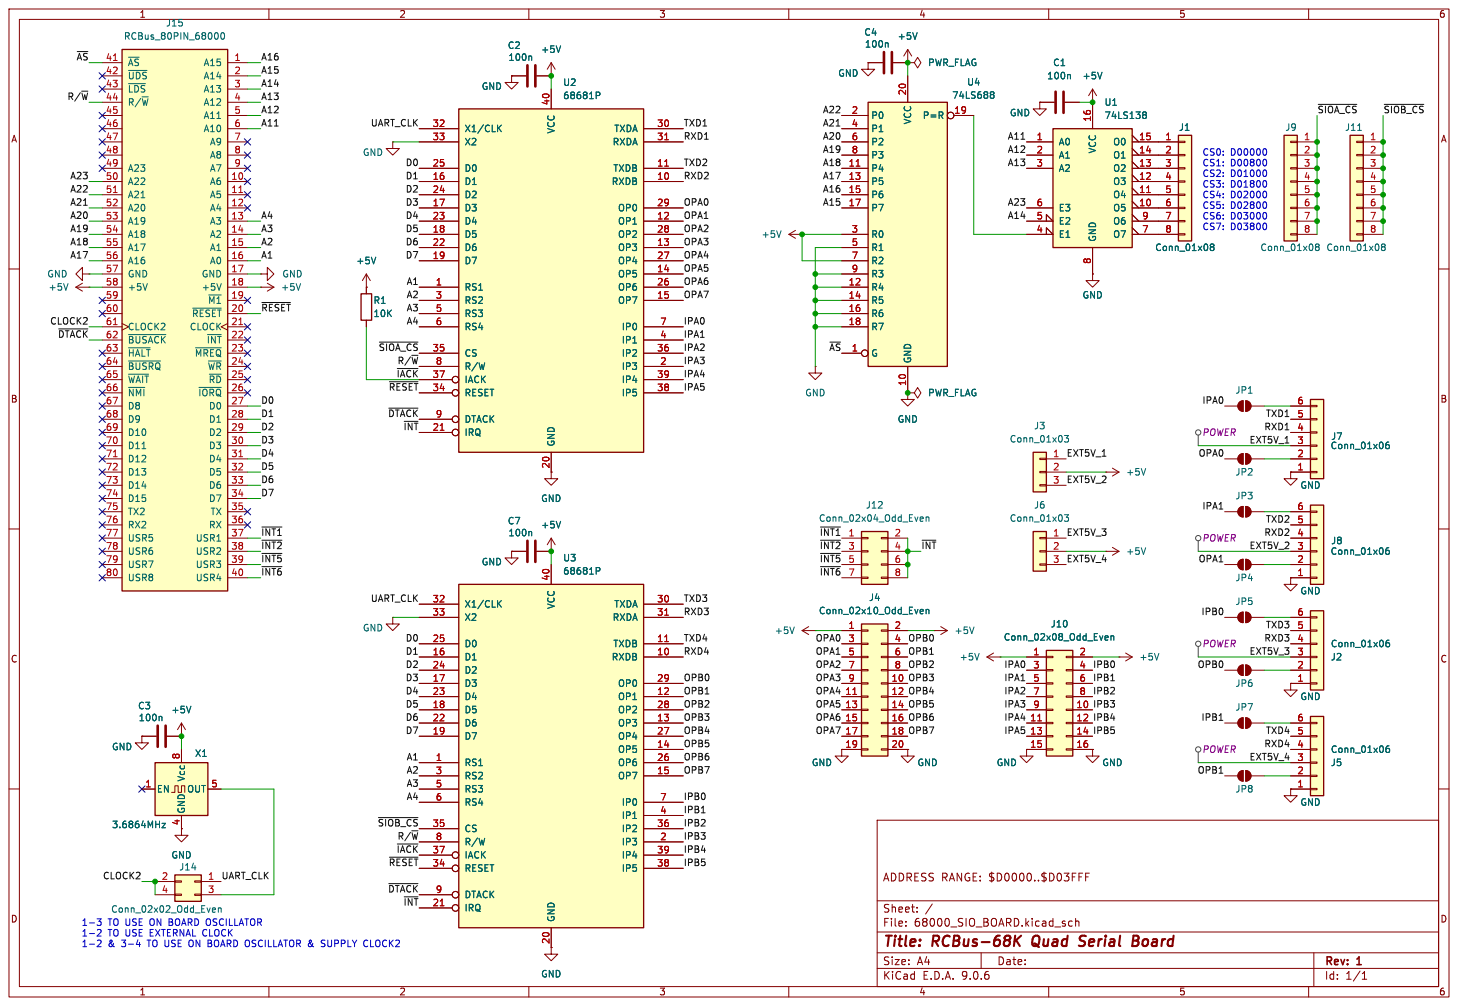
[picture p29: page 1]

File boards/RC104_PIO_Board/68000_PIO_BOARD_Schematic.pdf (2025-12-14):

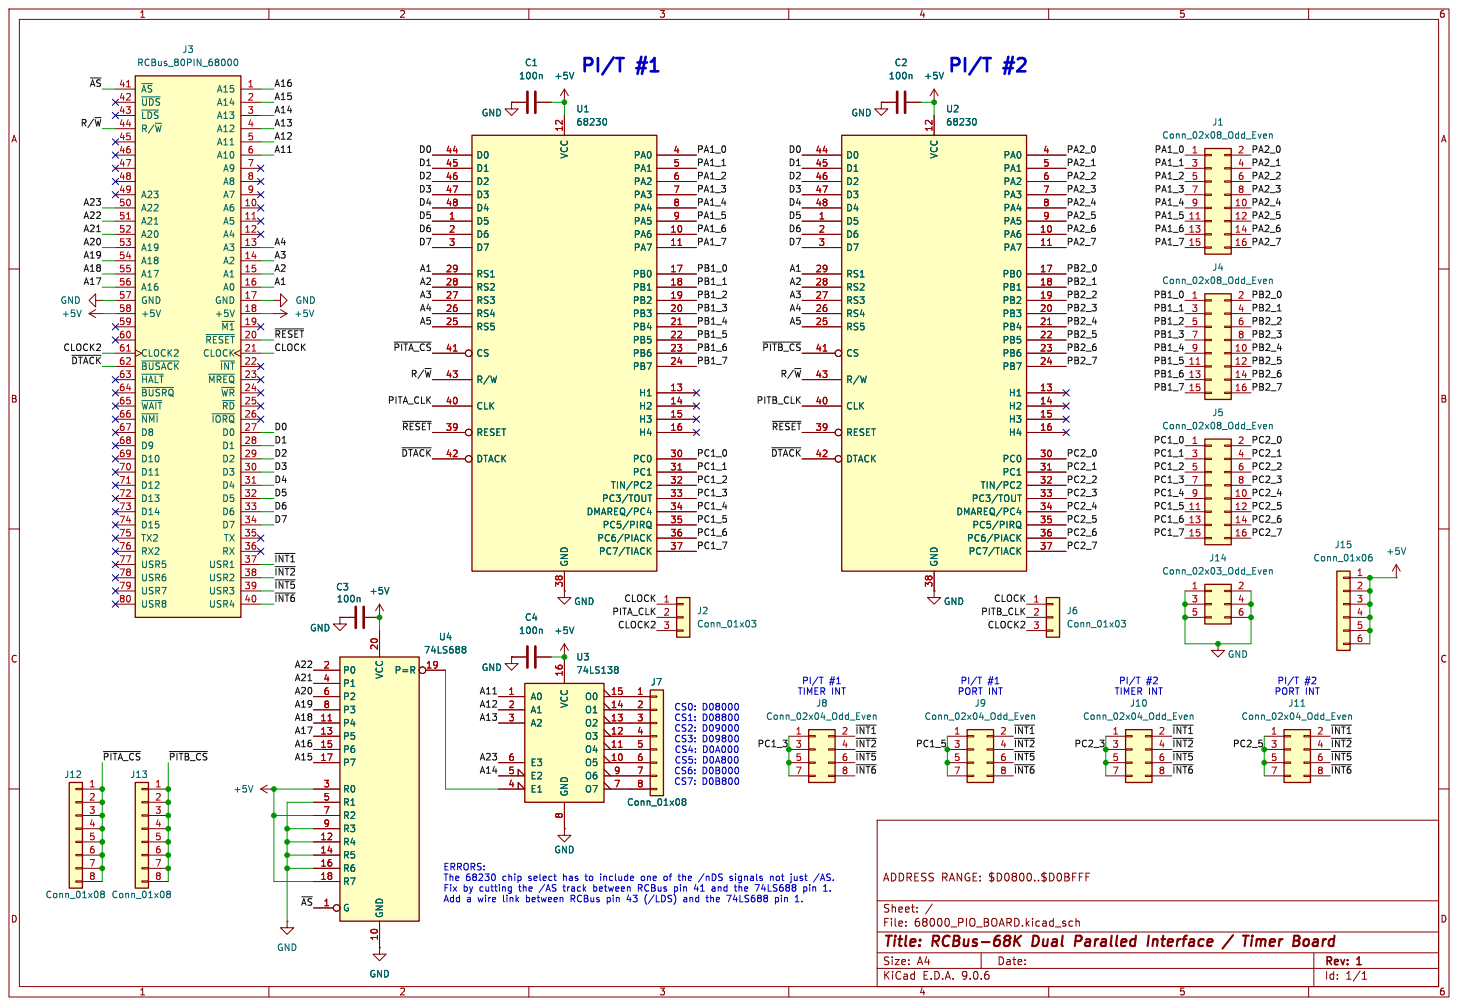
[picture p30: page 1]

D1 ~{PITA_CS} PITA_CLK
~{RESET} A5 ~{DTACK} A4 R/~{W} A20 A19 A15 A18 A16 A22 A21 ~{INT5}
60 CLOCK2 61 ~{BUSACK} 62 ~{HALT} 63 ~{BUSRQ} 64 ~{WAIT} 65 ~{NMI} 66 D8 67 D9 68 D10 69 D11 70 D12 71 D13 72 D14 73 D15 74 TX2 75 RX2 76 USR5 77 USR6 78 USR7 79 USR8 80

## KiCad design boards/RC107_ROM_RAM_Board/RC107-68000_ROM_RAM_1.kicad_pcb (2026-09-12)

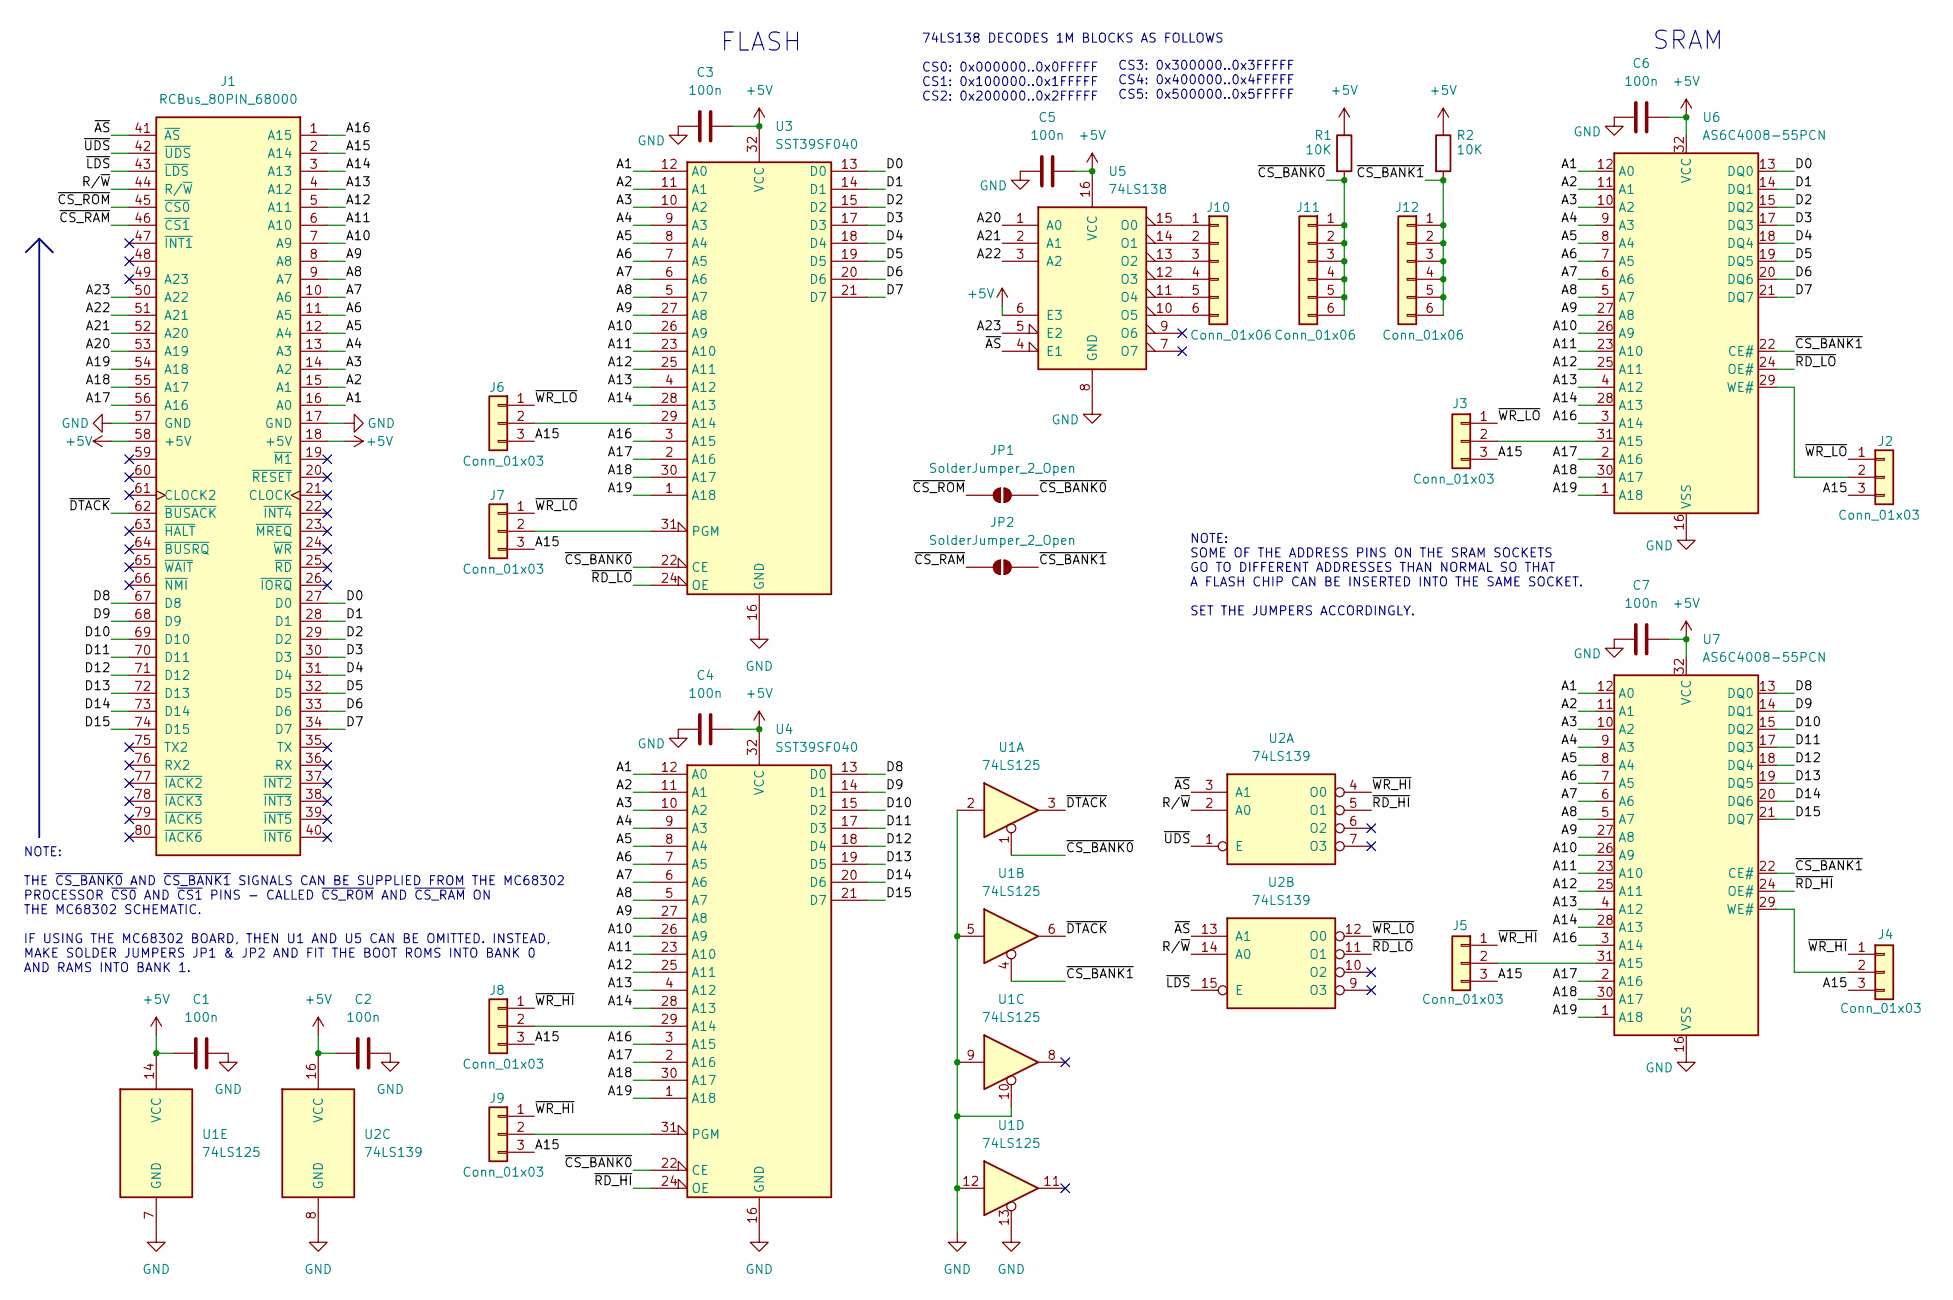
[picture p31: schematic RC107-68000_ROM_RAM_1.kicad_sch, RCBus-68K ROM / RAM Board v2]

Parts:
C1, C2, C3, C4, C5, C6, C7: 100n; C_Disc_D5.0mm_W2.5mm_P2.50mm
J1: RCBus_80PIN_68000; RCBus_80p_Medium
J2, J3, J4, J5, J6, J7, J8, J9: Conn_01x03; PinHeader_1x03_P2.54mm_Vertical
J10, J11, J12: Conn_01x06; PinHeader_1x06_P2.54mm_Vertical
JP1, JP2: SolderJumper_2_Open; SolderJumper-2_P1.3mm_Open_Pad1.0x1.5mm
R1, R2: 10K; R_Axial_DIN0207_L6.3mm_D2.5mm_P7.62mm_Horizontal
U1: 74LS125; DIP-14_W7.62mm
U2: 74LS139; DIP-16_W7.62mm
U3, U4: SST39SF040; DIP-32_W15.24mm
U5: 74LS138; DIP-16_W7.62mm
U6, U7: AS6C4008-55PCN; DIP-32_W15.24mm

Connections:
+5V: C1.1, C2.1, C3.2, C4.2, C5.2, C6.2, C7.2, J1.18 (+5V), J1.58 (+5V), R1.1, R2.1, U1.14 (VCC), U2.16 (VCC), U3.32 (VCC), U4.32 (VCC), U5.6 (E3), U5.16 (VCC), U6.32 (VCC), U7.32 (VCC)
/A1: J1.16 (A0), U3.12 (A0), U4.12 (A0), U6.12 (A0), U7.12 (A0)
/A2: J1.15 (A1), U3.11 (A1), U4.11 (A1), U6.11 (A1), U7.11 (A1)
/A3: J1.14 (A2), U3.10 (A2), U4.10 (A2), U6.10 (A2), U7.10 (A2)
/A4: J1.13 (A3), U3.9 (A3), U4.9 (A3), U6.9 (A3), U7.9 (A3)
/A5: J1.12 (A4), U3.8 (A4), U4.8 (A4), U6.8 (A4), U7.8 (A4)
/A6: J1.11 (A5), U3.7 (A5), U4.7 (A5), U6.7 (A5), U7.7 (A5)
/A7: J1.10 (A6), U3.6 (A6), U4.6 (A6), U6.6 (A6), U7.6 (A6)
/A8: J1.9 (A7), U3.5 (A7), U4.5 (A7), U6.5 (A7), U7.5 (A7)
/A9: J1.8 (A8), U3.27 (A8), U4.27 (A8), U6.27 (A8), U7.27 (A8)
/A10: J1.7 (A9), U3.26 (A9), U4.26 (A9), U6.26 (A9), U7.26 (A9)
/A11: J1.6 (A10), U3.23 (A10), U4.23 (A10), U6.23 (A10), U7.23 (A10)
/A12: J1.5 (A11), U3.25 (A11), U4.25 (A11), U6.25 (A11), U7.25 (A11)
/A13: J1.4 (A12), U3.4 (A12), U4.4 (A12), U6.4 (A12), U7.4 (A12)
/A14: J1.3 (A13), U3.28 (A13), U4.28 (A13), U6.28 (A13), U7.28 (A13)
/A15: J1.2 (A14), J2.3, J3.3, J4.3, J5.3, J6.3, J7.3, J8.3, J9.3
/A16: J1.1 (A15), U3.3 (A15), U4.3 (A15), U6.3 (A14), U7.3 (A14)
/A17: J1.56 (A16), U3.2 (A16), U4.2 (A16), U6.2 (A16), U7.2 (A16)
/A18: J1.55 (A17), U3.30 (A17), U4.30 (A17), U6.30 (A17), U7.30 (A17)
/A19: J1.54 (A18), U3.1 (A18), U4.1 (A18), U6.1 (A18), U7.1 (A18)
/A20: J1.53 (A19), U5.1 (A0)
/A21: J1.52 (A20), U5.2 (A1)
/A22: J1.51 (A21), U5.3 (A2)
/A23: J1.50 (A22), U5.5 (E2)
/D0: J1.27 (D0), U3.13 (D0), U6.13 (DQ0)
/D1: J1.28 (D1), U3.14 (D1), U6.14 (DQ1)
/D2: J1.29 (D2), U3.15 (D2), U6.15 (DQ2)
/D3: J1.30 (D3), U3.17 (D3), U6.17 (DQ3)
/D4: J1.31 (D4), U3.18 (D4), U6.18 (DQ4)
/D5: J1.32 (D5), U3.19 (D5), U6.19 (DQ5)
/D6: J1.33 (D6), U3.20 (D6), U6.20 (DQ6)
/D7: J1.34 (D7), U3.21 (D7), U6.21 (DQ7)
/D8: J1.67 (D8), U4.13 (D0), U7.13 (DQ0)
/D9: J1.68 (D9), U4.14 (D1), U7.14 (DQ1)
/D10: J1.69 (D10), U4.15 (D2), U7.15 (DQ2)
/D11: J1.70 (D11), U4.17 (D3), U7.17 (DQ3)
/D12: J1.71 (D12), U4.18 (D4), U7.18 (DQ4)
/D13: J1.72 (D13), U4.19 (D5), U7.19 (DQ5)
/D14: J1.73 (D14), U4.20 (D6), U7.20 (DQ6)
/D15: J1.74 (D15), U4.21 (D7), U7.21 (DQ7)
/R/~W: J1.44 (R/~W), U2.2 (A0), U2.14 (A0)
/~AS: J1.41 (~AS), U2.3 (A1), U2.13 (A1), U5.4 (E1)
/~CS_BANK0: J11.1, J11.2, J11.3, J11.4, J11.5, J11.6, JP1.2 (B), R1.2, U1.1, U3.22 (CE), U4.22 (CE)
/~CS_BANK1: J12.1, J12.2, J12.3, J12.4, J12.5, J12.6, JP2.2 (B), R2.2, U1.4, U6.22 (CE#), U7.22 (CE#)
/~CS_RAM: J1.46 (~CS1), JP2.1 (A)
/~CS_ROM: J1.45 (~CS0), JP1.1 (A)
/~DTACK: J1.62 (~BUSACK), U1.3, U1.6
/~LDS: J1.43 (~LDS), U2.15 (E)
/~RD_HI: U2.5 (O1), U4.24 (OE), U7.24 (OE#)
/~RD_LO: U2.11 (O1), U3.24 (OE), U6.24 (OE#)
/~UDS: J1.42 (~UDS), U2.1 (E)
/~WR_HI: J4.1, J5.1, J8.1, J9.1, U2.4 (O0)
/~WR_LO: J2.1, J3.1, J6.1, J7.1, U2.12 (O0)
GND: C1.2, C2.2, C3.1, C4.1, C5.1, C6.1, C7.1, J1.17 (GND), J1.57 (GND), U1.2, U1.5, U1.7 (GND), U1.9, U1.10, U1.12, U1.13, U2.8 (GND), U3.16 (GND), U4.16 (GND), U5.8 (GND), U6.16 (VSS), U7.16 (VSS)
unnamed: J2.2, U6.29 (WE#)
unnamed: J3.2, U6.31 (A15)
unnamed: J4.2, U7.29 (WE#)
unnamed: J5.2, U7.31 (A15)
unnamed: J6.2, U3.29 (A14)
unnamed: J7.2, U3.31 (PGM)
unnamed: J8.2, U4.29 (A14)
unnamed: J9.2, U4.31 (PGM)
unnamed: J10.1, U5.15 (O0)
unnamed: J10.2, U5.14 (O1)
unnamed: J10.3, U5.13 (O2)
unnamed: J10.4, U5.12 (O3)
unnamed: J10.5, U5.11 (O4)
unnamed: J10.6, U5.10 (O5)

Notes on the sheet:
CS3: 0x300000..0x3FFFFF CS4: 0x400000..0x4FFFFF CS5: 0x500000..0x5FFFFF
FLASH
NOTE: THE ~{CS_BANK0} AND ~{CS_BANK1} SIGNALS CAN BE SUPPLIED FROM THE MC68302 PROCESSOR ~{CS0} AND ~{CS1} PINS - CALLED ~{CS_ROM} AND ~{CS_RAM} ON THE MC68302 SCHEMATIC. IF USING THE MC68302 BOARD, THEN U1 AND U5 CAN BE OMITTED. INSTEAD, MAKE SOLDER JUMPERS JP1 & JP2 AND FIT THE BOOT ROMS INTO BAN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
74LS138 DECODES 1M BLOCKS AS FOLLOWS CS0: 0x000000..0x0FFFFF CS1: 0x100000..0x1FFFFF CS2: 0x200000..0x2FFFFF
NOTE: SOME OF THE ADDRESS PINS ON THE SRAM SOCKETS GO TO DIFFERENT ADDRESSES THAN NORMAL SO THAT A FLASH CHIP CAN BE INSERTED INTO THE SAME SOCKET. SET THE JUMPERS ACCORDINGLY.
SRAM

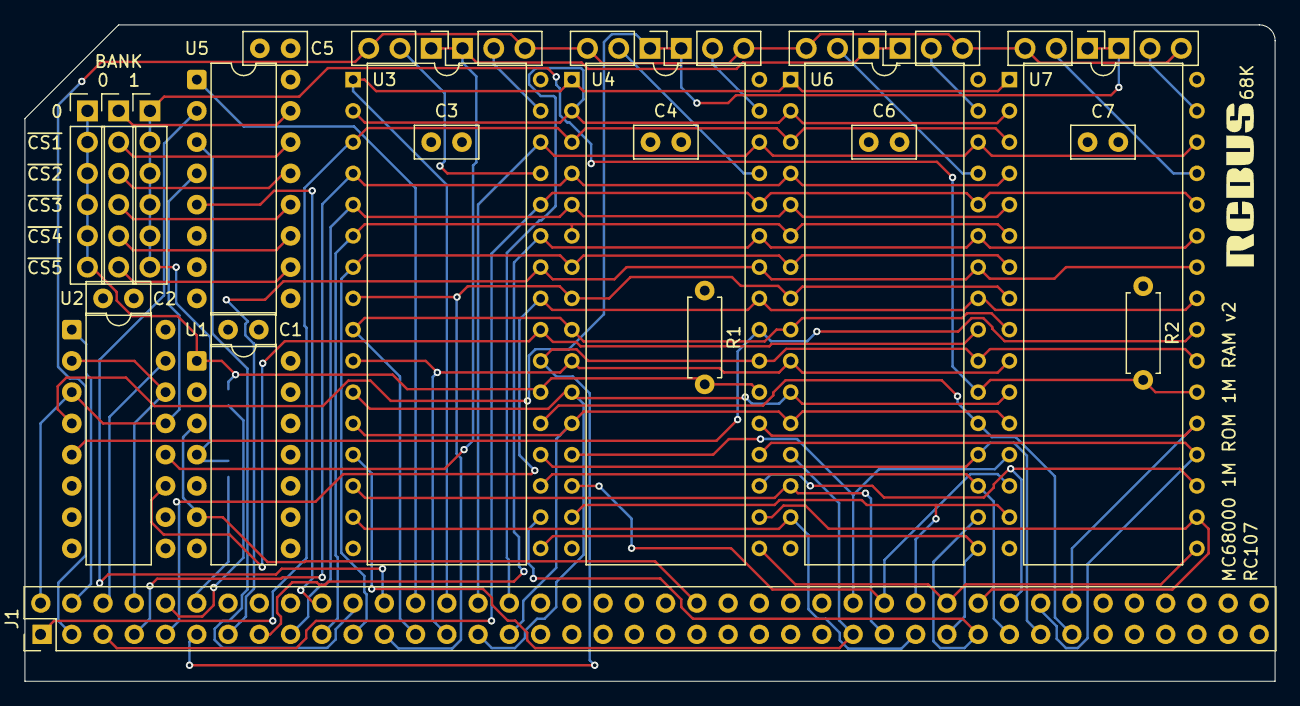
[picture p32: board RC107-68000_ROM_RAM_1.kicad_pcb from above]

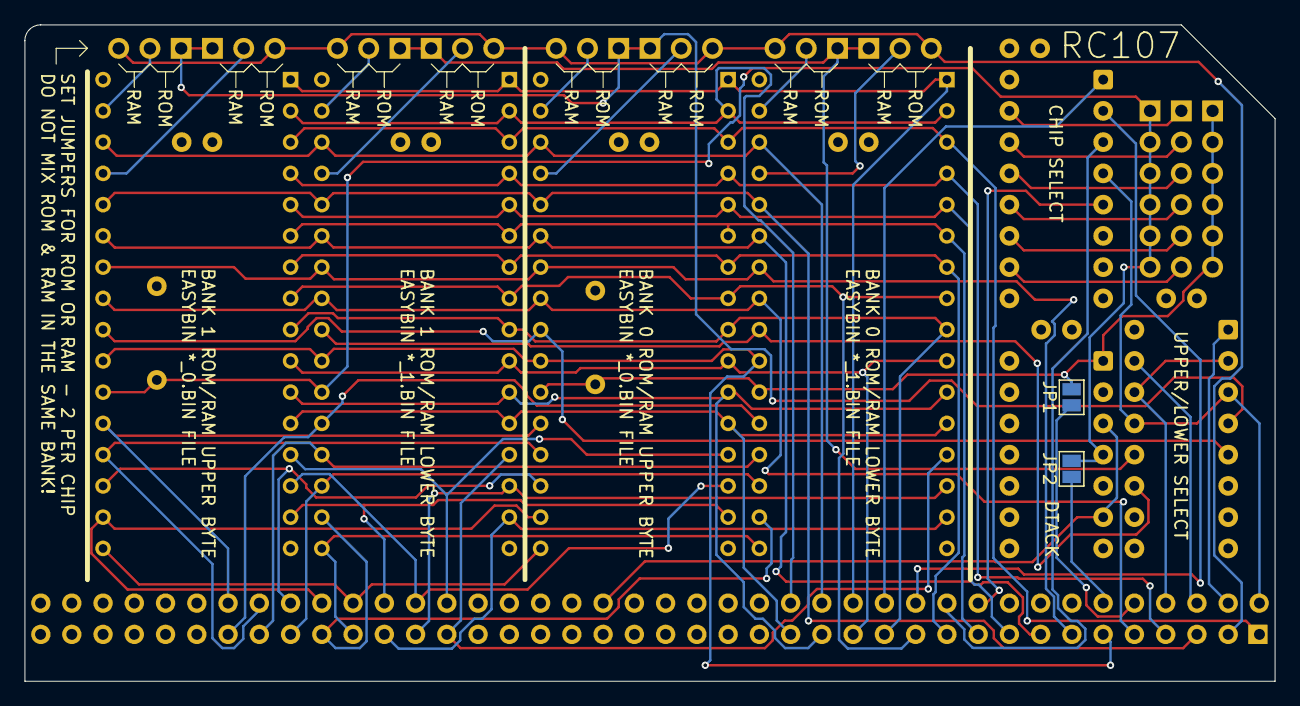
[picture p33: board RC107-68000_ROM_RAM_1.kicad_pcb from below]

Board: 4 copper layers, 101.6 x 53.3 mm, 30 parts (2 on the bottom side), 68 nets.

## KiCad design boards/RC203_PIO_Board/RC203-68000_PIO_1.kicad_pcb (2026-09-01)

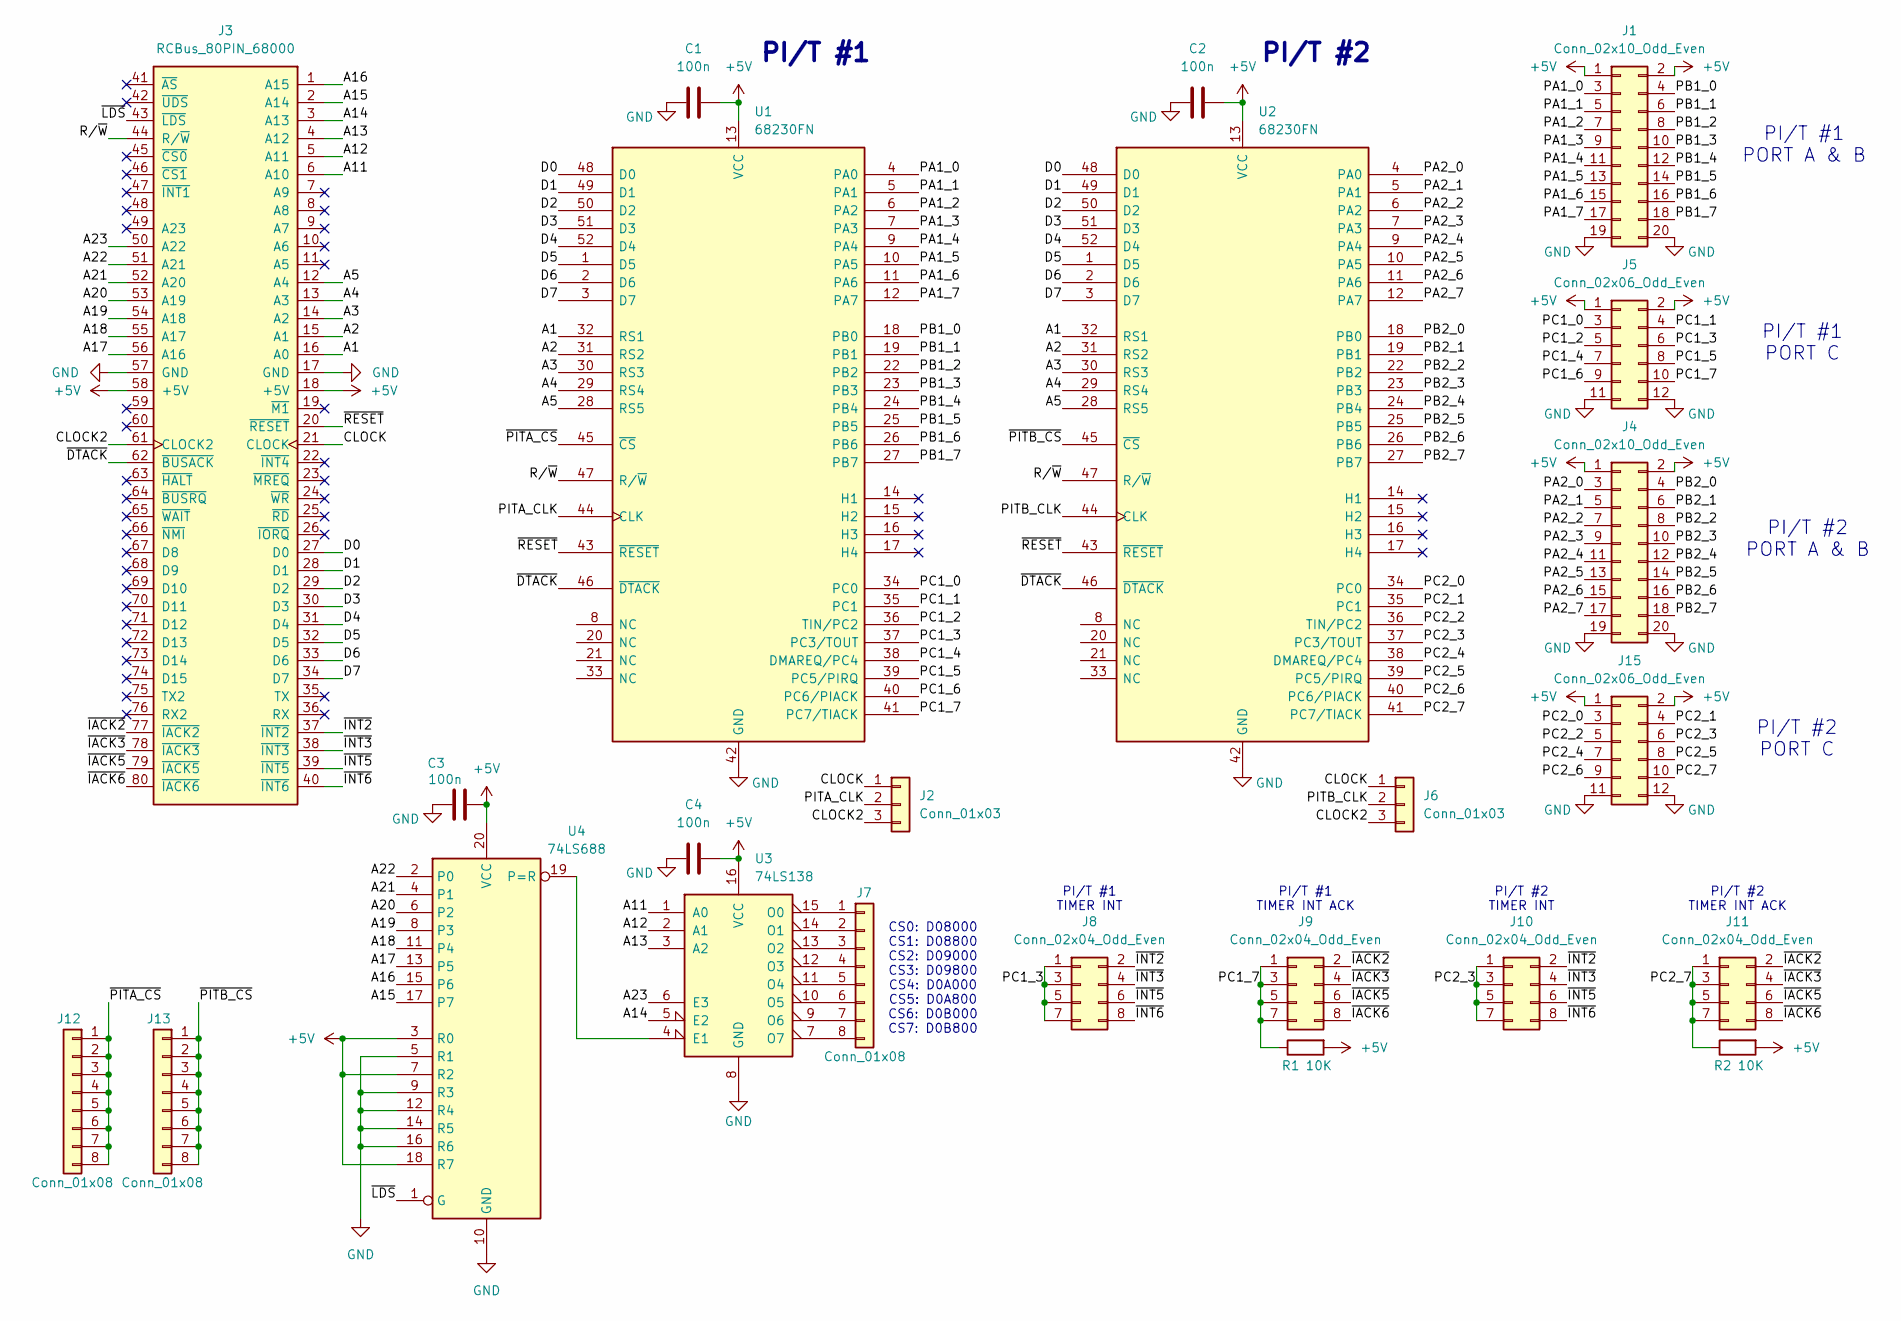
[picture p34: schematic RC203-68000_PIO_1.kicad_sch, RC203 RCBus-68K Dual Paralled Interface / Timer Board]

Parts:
C1, C2, C3, C4: 100n; C_Disc_D5.0mm_W2.5mm_P2.50mm
J1, J4: Conn_02x10_Odd_Even; PinHeader_2x10_P2.54mm_Horizontal
J2, J6: Conn_01x03; PinHeader_1x03_P2.54mm_Vertical
J3: RCBus_80PIN_68000; RCBus_80p_Medium
J5, J15: Conn_02x06_Odd_Even; PinHeader_2x06_P2.54mm_Horizontal
J7, J12, J13: Conn_01x08; PinHeader_1x08_P2.54mm_Vertical
J8, J9, J10, J11: Conn_02x04_Odd_Even; PinHeader_2x04_P2.54mm_Vertical
R1, R2: 10K; R_Axial_DIN0207_L6.3mm_D2.5mm_P7.62mm_Horizontal
U1, U2: 68230FN; PLCC-52_THT-Socket
U3: 74LS138; DIP-16_W7.62mm
U4: 74LS688; DIP-20_W7.62mm

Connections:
+5V: C1.1, C2.1, C3.2, C4.2, J1.1, J1.2, J3.18 (+5V), J3.58 (+5V), J4.1, J4.2, J5.1, J5.2, J15.1, J15.2, R1.2, R2.2, U1.13 (VCC), U2.13 (VCC), U3.16 (VCC), U4.3 (R0), U4.7 (R2), U4.18 (R7), U4.20 (VCC)
/A1: J3.16 (A0), U1.32 (RS1), U2.32 (RS1)
/A2: J3.15 (A1), U1.31 (RS2), U2.31 (RS2)
/A3: J3.14 (A2), U1.30 (RS3), U2.30 (RS3)
/A4: J3.13 (A3), U1.29 (RS4), U2.29 (RS4)
/A5: J3.12 (A4), U1.28 (RS5), U2.28 (RS5)
/A11: J3.6 (A10), U3.1 (A0)
/A12: J3.5 (A11), U3.2 (A1)
/A13: J3.4 (A12), U3.3 (A2)
/A14: J3.3 (A13), U3.5 (E2)
/A15: J3.2 (A14), U4.17 (P7)
/A16: J3.1 (A15), U4.15 (P6)
/A17: J3.56 (A16), U4.13 (P5)
/A18: J3.55 (A17), U4.11 (P4)
/A19: J3.54 (A18), U4.8 (P3)
/A20: J3.53 (A19), U4.6 (P2)
/A21: J3.52 (A20), U4.4 (P1)
/A22: J3.51 (A21), U4.2 (P0)
/A23: J3.50 (A22), U3.6 (E3)
/CLOCK: J2.1, J3.21 (CLOCK), J6.1
/CLOCK2: J2.3, J3.61 (CLOCK2), J6.3
/D0: J3.27 (D0), U1.48 (D0), U2.48 (D0)
/D1: J3.28 (D1), U1.49 (D1), U2.49 (D1)
/D2: J3.29 (D2), U1.50 (D2), U2.50 (D2)
/D3: J3.30 (D3), U1.51 (D3), U2.51 (D3)
/D4: J3.31 (D4), U1.52 (D4), U2.52 (D4)
/D5: J3.32 (D5), U1.1 (D5), U2.1 (D5)
/D6: J3.33 (D6), U1.2 (D6), U2.2 (D6)
/D7: J3.34 (D7), U1.3 (D7), U2.3 (D7)
/PA1_0: J1.3, U1.4 (PA0)
/PA1_1: J1.5, U1.5 (PA1)
/PA1_2: J1.7, U1.6 (PA2)
/PA1_3: J1.9, U1.7 (PA3)
/PA1_4: J1.11, U1.9 (PA4)
/PA1_5: J1.13, U1.10 (PA5)
/PA1_6: J1.15, U1.11 (PA6)
/PA1_7: J1.17, U1.12 (PA7)
/PA2_0: J4.3, U2.4 (PA0)
/PA2_1: J4.5, U2.5 (PA1)
/PA2_2: J4.7, U2.6 (PA2)
/PA2_3: J4.9, U2.7 (PA3)
/PA2_4: J4.11, U2.9 (PA4)
/PA2_5: J4.13, U2.10 (PA5)
/PA2_6: J4.15, U2.11 (PA6)
/PA2_7: J4.17, U2.12 (PA7)
/PB1_0: J1.4, U1.18 (PB0)
/PB1_1: J1.6, U1.19 (PB1)
/PB1_2: J1.8, U1.22 (PB2)
/PB1_3: J1.10, U1.23 (PB3)
/PB1_4: J1.12, U1.24 (PB4)
/PB1_5: J1.14, U1.25 (PB5)
/PB1_6: J1.16, U1.26 (PB6)
/PB1_7: J1.18, U1.27 (PB7)
/PB2_0: J4.4, U2.18 (PB0)
/PB2_1: J4.6, U2.19 (PB1)
/PB2_2: J4.8, U2.22 (PB2)
/PB2_3: J4.10, U2.23 (PB3)
/PB2_4: J4.12, U2.24 (PB4)
/PB2_5: J4.14, U2.25 (PB5)
/PB2_6: J4.16, U2.26 (PB6)
/PB2_7: J4.18, U2.27 (PB7)
/PC1_0: J5.3, U1.34 (PC0)
/PC1_1: J5.4, U1.35 (PC1)
/PC1_2: J5.5, U1.36 (TIN/PC2)
/PC1_3: J5.6, J8.1, J8.3, J8.5, J8.7, U1.37 (PC3/TOUT)
/PC1_4: J5.7, U1.38 (DMAREQ/PC4)
/PC1_5: J5.8, U1.39 (PC5/PIRQ)
/PC1_6: J5.9, U1.40 (PC6/PIACK)
/PC1_7: J5.10, J9.1, J9.3, J9.5, J9.7, R1.1, U1.41 (PC7/TIACK)
/PC2_0: J15.3, U2.34 (PC0)
/PC2_1: J15.4, U2.35 (PC1)
/PC2_2: J15.5, U2.36 (TIN/PC2)
/PC2_3: J10.1, J10.3, J10.5, J10.7, J15.6, U2.37 (PC3/TOUT)
/PC2_4: J15.7, U2.38 (DMAREQ/PC4)
/PC2_5: J15.8, U2.39 (PC5/PIRQ)
/PC2_6: J15.9, U2.40 (PC6/PIACK)
/PC2_7: J11.1, J11.3, J11.5, J11.7, J15.10, R2.1, U2.41 (PC7/TIACK)
/PITA_CLK: J2.2, U1.44 (CLK)
/PITB_CLK: J6.2, U2.44 (CLK)
/R/~W: J3.44 (R/~W), U1.47 (R/~W), U2.47 (R/~W)
/~DTACK: J3.62 (~BUSACK), U1.46 (~DTACK), U2.46 (~DTACK)
/~IACK2: J3.77 (~IACK2), J9.2, J11.2
/~IACK3: J3.78 (~IACK3), J9.4, J11.4
/~IACK5: J3.79 (~IACK5), J9.6, J11.6
/~IACK6: J3.80 (~IACK6), J9.8, J11.8
/~INT2: J3.37 (~INT2), J8.2, J10.2
/~INT3: J3.38 (~INT3), J8.4, J10.4
/~INT5: J3.39 (~INT5), J8.6, J10.6
/~INT6: J3.40 (~INT6), J8.8, J10.8
/~LDS: J3.43 (~LDS), U4.1 (G)
/~PITA_CS: J12.1, J12.2, J12.3, J12.4, J12.5, J12.6, J12.7, J12.8, U1.45 (~CS)
/~PITB_CS: J13.1, J13.2, J13.3, J13.4, J13.5, J13.6, J13.7, J13.8, U2.45 (~CS)
/~RESET: J3.20 (~RESET), U1.43 (~RESET), U2.43 (~RESET)
GND: C1.2, C2.2, C3.1, C4.1, J1.19, J1.20, J3.17 (GND), J3.57 (GND), J4.19, J4.20, J5.11, J5.12, J15.11, J15.12, U1.42 (GND), U2.42 (GND), U3.8 (GND), U4.5 (R1), U4.9 (R3), U4.10 (GND), U4.12 (R4), U4.14 (R5), U4.16 (R6)
unnamed: J7.1, U3.15 (O0)
unnamed: J7.2, U3.14 (O1)
unnamed: J7.3, U3.13 (O2)
unnamed: J7.4, U3.12 (O3)
unnamed: J7.5, U3.11 (O4)
unnamed: J7.6, U3.10 (O5)
unnamed: J7.7, U3.9 (O6)
unnamed: J7.8, U3.7 (O7)
unnamed: U3.4 (E1), U4.19 (P=R)

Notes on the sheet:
PI/T #2 TIMER INT ACK
PI/T #1 TIMER INT ACK
PI/T #2
CS0: D08000 CS1: D08800 CS2: D09000 CS3: D09800 CS4: D0A000 CS5: D0A800 CS6: D0B000 CS7: D0B800
PI/T #1 PORT C
PI/T #1 TIMER INT
PI/T #2 TIMER INT
PI/T #2 PORT A & B
PI/T #2 PORT C
PI/T #1
PI/T #1 PORT A & B

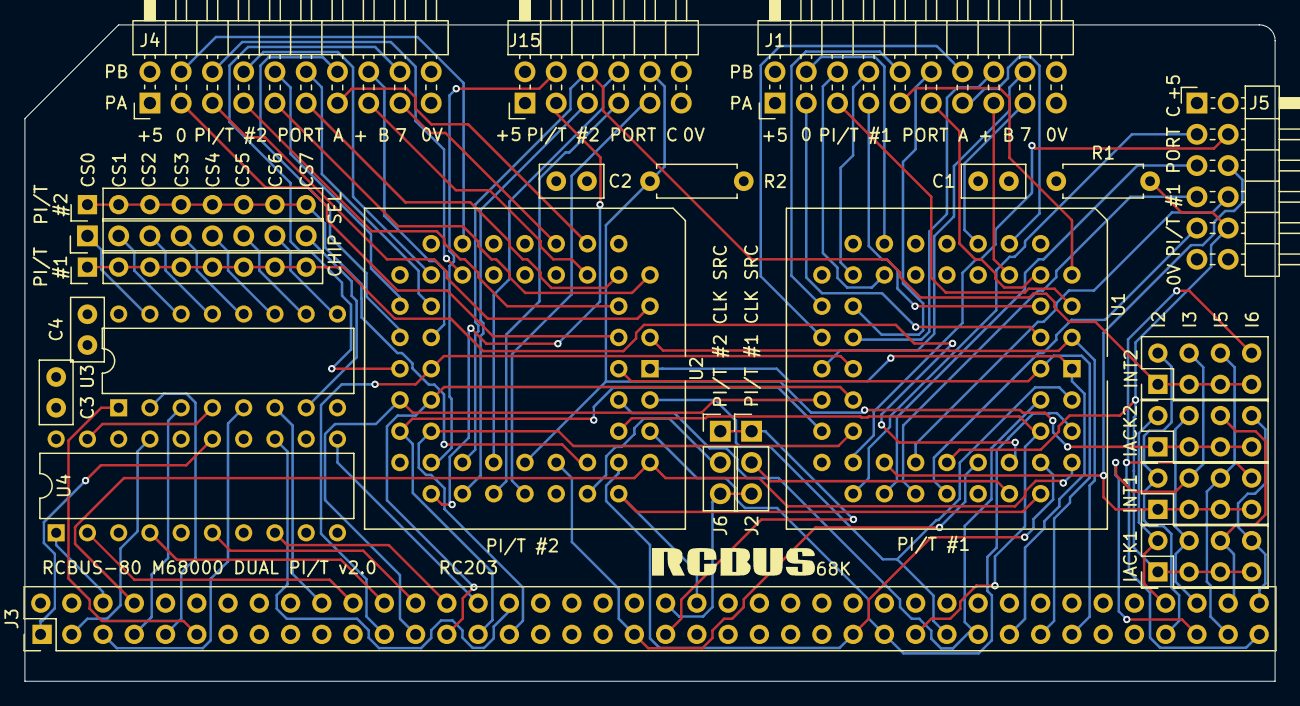
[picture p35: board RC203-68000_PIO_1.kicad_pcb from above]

Board: 4 copper layers, 101.6 x 53.3 mm, 24 parts (0 on the bottom side), 103 nets.

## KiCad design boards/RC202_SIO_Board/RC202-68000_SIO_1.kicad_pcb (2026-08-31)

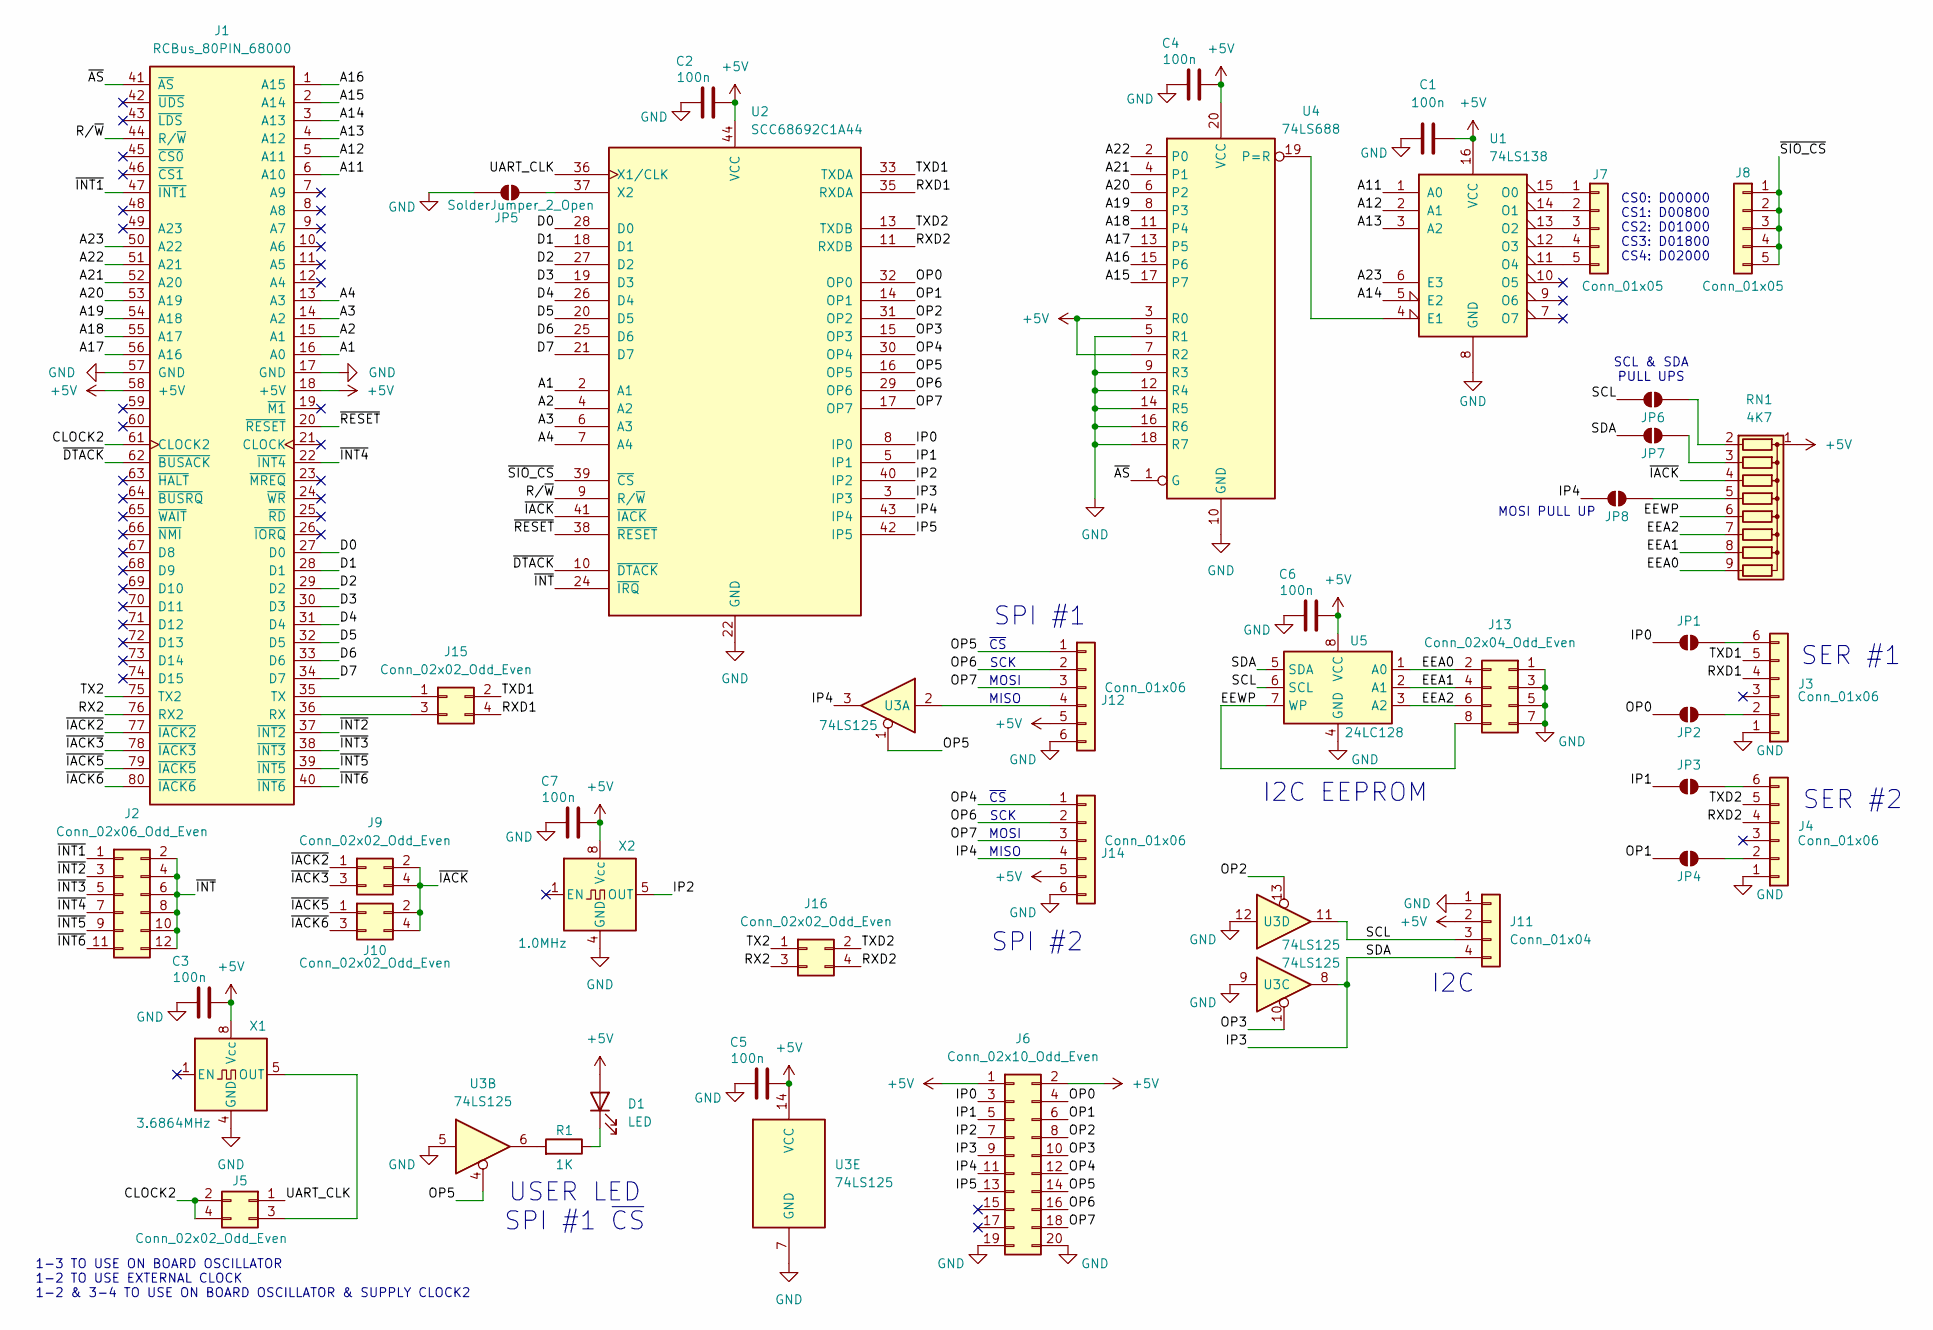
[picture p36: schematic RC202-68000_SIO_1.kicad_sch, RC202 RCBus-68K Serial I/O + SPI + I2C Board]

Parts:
C1, C2, C3, C4, C5, C6, C7: 100n; C_Disc_D5.0mm_W2.5mm_P2.50mm
D1: LED; LED_D3.0mm
J1: RCBus_80PIN_68000; RCBus_80p_Medium
J2: Conn_02x06_Odd_Even; PinHeader_2x06_P2.54mm_Vertical
J3, J4, J12, J14: Conn_01x06; PinSocket_1x06_P2.54mm_Horizontal
J5, J9, J10, J15, J16: Conn_02x02_Odd_Even; PinHeader_2x02_P2.54mm_Vertical
J6: Conn_02x10_Odd_Even; PinHeader_2x10_P2.54mm_Horizontal
J7, J8: Conn_01x05; PinHeader_1x05_P2.54mm_Vertical
J11: Conn_01x04; PinHeader_1x04_P2.54mm_Horizontal
J13: Conn_02x04_Odd_Even; PinHeader_2x04_P2.54mm_Vertical
JP1, JP2, JP3, JP4, JP6, JP7, JP8: SolderJumper; SolderJumper-2_P1.3mm_Open_Pad1.0x1.5mm
JP5: SolderJumper_2_Open; SolderJumper-2_P1.3mm_Open_Pad1.0x1.5mm
R1: 1K; R_Axial_DIN0207_L6.3mm_D2.5mm_P7.62mm_Horizontal
RN1: 4K7; R_Array_SIP9
U1: 74LS138; DIP-16_W7.62mm
U2: SCC68692C1A44; PLCC-44_THT-Socket
U3: 74LS125; DIP-14_W7.62mm
U4: 74LS688; DIP-20_W7.62mm
U5: 24LC128; DIP-8_W7.62mm
X1: 3.6864MHz; Oscillator_DIP-8
X2: 1.0MHz; Oscillator_DIP-8

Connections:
+5V: C1.2, C2.2, C3.2, C4.2, C5.2, C6.2, C7.2, D1.2 (A), J1.18 (+5V), J1.58 (+5V), J6.1, J6.2, J11.2, J12.5, J14.5, RN1.1 (common), U1.16 (VCC), U2.44 (VCC), U3.14 (VCC), U4.3 (R0), U4.7 (R2), U4.20 (VCC), U5.8 (VCC), X1.8 (Vcc), X2.8 (Vcc)
/A1: J1.16 (A0), U2.2 (A1)
/A2: J1.15 (A1), U2.4 (A2)
/A3: J1.14 (A2), U2.6 (A3)
/A4: J1.13 (A3), U2.7 (A4)
/A11: J1.6 (A10), U1.1 (A0)
/A12: J1.5 (A11), U1.2 (A1)
/A13: J1.4 (A12), U1.3 (A2)
/A14: J1.3 (A13), U1.5 (E2)
/A15: J1.2 (A14), U4.17 (P7)
/A16: J1.1 (A15), U4.15 (P6)
/A17: J1.56 (A16), U4.13 (P5)
/A18: J1.55 (A17), U4.11 (P4)
/A19: J1.54 (A18), U4.8 (P3)
/A20: J1.53 (A19), U4.6 (P2)
/A21: J1.52 (A20), U4.4 (P1)
/A22: J1.51 (A21), U4.2 (P0)
/A23: J1.50 (A22), U1.6 (E3)
/CLOCK2: J1.61 (CLOCK2), J5.2, J5.4
/D0: J1.27 (D0), U2.28 (D0)
/D1: J1.28 (D1), U2.18 (D1)
/D2: J1.29 (D2), U2.27 (D2)
/D3: J1.30 (D3), U2.19 (D3)
/D4: J1.31 (D4), U2.26 (D4)
/D5: J1.32 (D5), U2.20 (D5)
/D6: J1.33 (D6), U2.25 (D6)
/D7: J1.34 (D7), U2.21 (D7)
/EEA0: J13.2, RN1.9 (R8), U5.1 (A0)
/EEA1: J13.4, RN1.8 (R7), U5.2 (A1)
/EEA2: J13.6, RN1.7 (R6), U5.3 (A2)
/EEWP: J13.8, RN1.6 (R5), U5.7 (WP)
/IP0: J6.3, JP1.1 (A), U2.8 (IP0)
/IP1: J6.5, JP3.1 (A), U2.5 (IP1)
/IP2: J6.7, U2.40 (IP2), X2.5 (OUT)
/IP3: J6.9, J11.4, JP7.1 (A), U2.3 (IP3), U3.8, U5.5 (SDA)
/IP4: J6.11, J14.4, JP8.1 (A), U2.43 (IP4), U3.3
/IP5: J6.13, U2.42 (IP5)
/OP0: J6.4, JP2.1 (A), U2.32 (OP0)
/OP1: J6.6, JP4.1 (A), U2.14 (OP1)
/OP2: J6.8, U2.31 (OP2), U3.13
/OP3: J6.10, U2.15 (OP3), U3.10
/OP4: J6.12, J14.1, U2.30 (OP4)
/OP5: J6.14, J12.1, U2.16 (OP5), U3.1, U3.4
/OP6: J6.16, J12.2, J14.2, U2.29 (OP6)
/OP7: J6.18, J12.3, J14.3, U2.17 (OP7)
/RX2: J1.76 (RX2), J16.3
/RXD1: J3.4, J15.4, U2.35 (RXDA)
/RXD2: J4.4, J16.4, U2.11 (RXDB)
/R/~W: J1.44 (R/~W), U2.9 (R/~W)
/SCL: J11.3, JP6.1 (A), U3.11, U5.6 (SCL)
/TX2: J1.75 (TX2), J16.1
/TXD1: J3.5, J15.2, U2.33 (TXDA)
/TXD2: J4.5, J16.2, U2.13 (TXDB)
/UART_CLK: J5.1, U2.36 (X1/CLK)
/~AS: J1.41 (~AS), U4.1 (G)
/~DTACK: J1.62 (~BUSACK), U2.10 (~DTACK)
/~IACK2: J1.77 (~IACK2), J9.1
/~IACK3: J1.78 (~IACK3), J9.3
/~IACK5: J1.79 (~IACK5), J10.1
/~IACK6: J1.80 (~IACK6), J10.3
/~IACK: J9.2, J9.4, J10.2, J10.4, RN1.4 (R3), U2.41 (~IACK)
/~INT1: J1.47 (~INT1), J2.1
/~INT2: J1.37 (~INT2), J2.3
/~INT3: J1.38 (~INT3), J2.5
/~INT4: J1.22 (~INT4), J2.7
/~INT5: J1.39 (~INT5), J2.9
/~INT6: J1.40 (~INT6), J2.11
/~INT: J2.2, J2.4, J2.6, J2.8, J2.10, J2.12, U2.24 (~IRQ)
/~RESET: J1.20 (~RESET), U2.38 (~RESET)
/~SIO_CS: J8.1, J8.2, J8.3, J8.4, J8.5, U2.39 (~CS)
GND: C1.1, C2.1, C3.1, C4.1, C5.1, C6.1, C7.1, J1.17 (GND), J1.57 (GND), J3.1, J4.1, J6.19, J6.20, J11.1, J12.6, J13.1, J13.3, J13.5, J13.7, J14.6, JP5.2 (B), U1.8 (GND), U2.22 (GND), U3.5, U3.7 (GND), U3.9, U3.12, U4.5 (R1), U4.9 (R3), U4.10 (GND), U4.12 (R4), U4.14 (R5), U4.16 (R6), U4.18 (R7), U5.4 (GND), X1.4 (GND), X2.4 (GND)
unnamed: D1.1 (K), R1.1
unnamed: J1.36 (RX), J15.3
unnamed: J1.35 (TX), J15.1
unnamed: J3.2, JP2.2 (B)
unnamed: J3.6, JP1.2 (B)
unnamed: J4.2, JP4.2 (B)
unnamed: J4.6, JP3.2 (B)
unnamed: J5.3, X1.5 (OUT)
unnamed: J7.1, U1.15 (O0)
unnamed: J7.2, U1.14 (O1)
unnamed: J7.3, U1.13 (O2)
unnamed: J7.4, U1.12 (O3)
unnamed: J7.5, U1.11 (O4)
unnamed: J12.4, U3.2
unnamed: JP5.1 (A), U2.37 (X2)
unnamed: JP6.2 (B), RN1.2 (R1)
unnamed: JP7.2 (B), RN1.3 (R2)
unnamed: JP8.2 (B), RN1.5 (R4)
unnamed: R1.2, U3.6
unnamed: U1.4 (E1), U4.19 (P=R)

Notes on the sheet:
I2C EEPROM
SCK
SCL & SDA PULL UPS
~{CS}
MOSI PULL UP
MISO
MOSI
I2C
CS0: D00000 CS1: D00800 CS2: D01000 CS3: D01800 CS4: D02000
SER #1
SER #2
SPI #1
1-3 TO USE ON BOARD OSCILLATOR 1-2 TO USE EXTERNAL CLOCK 1-2 & 3-4 TO USE ON BOARD OSCILLATOR & SUPPLY CLOCK2
USER LED SPI #1 ~{CS}
SPI #2

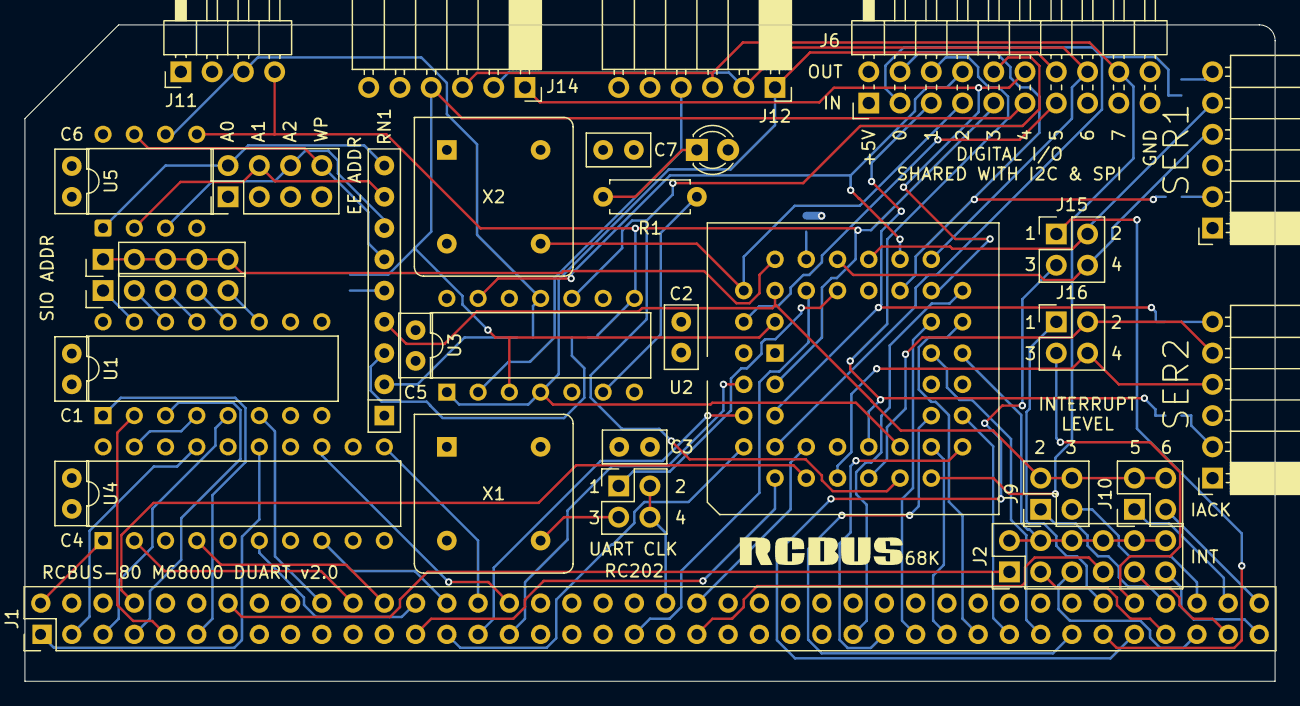
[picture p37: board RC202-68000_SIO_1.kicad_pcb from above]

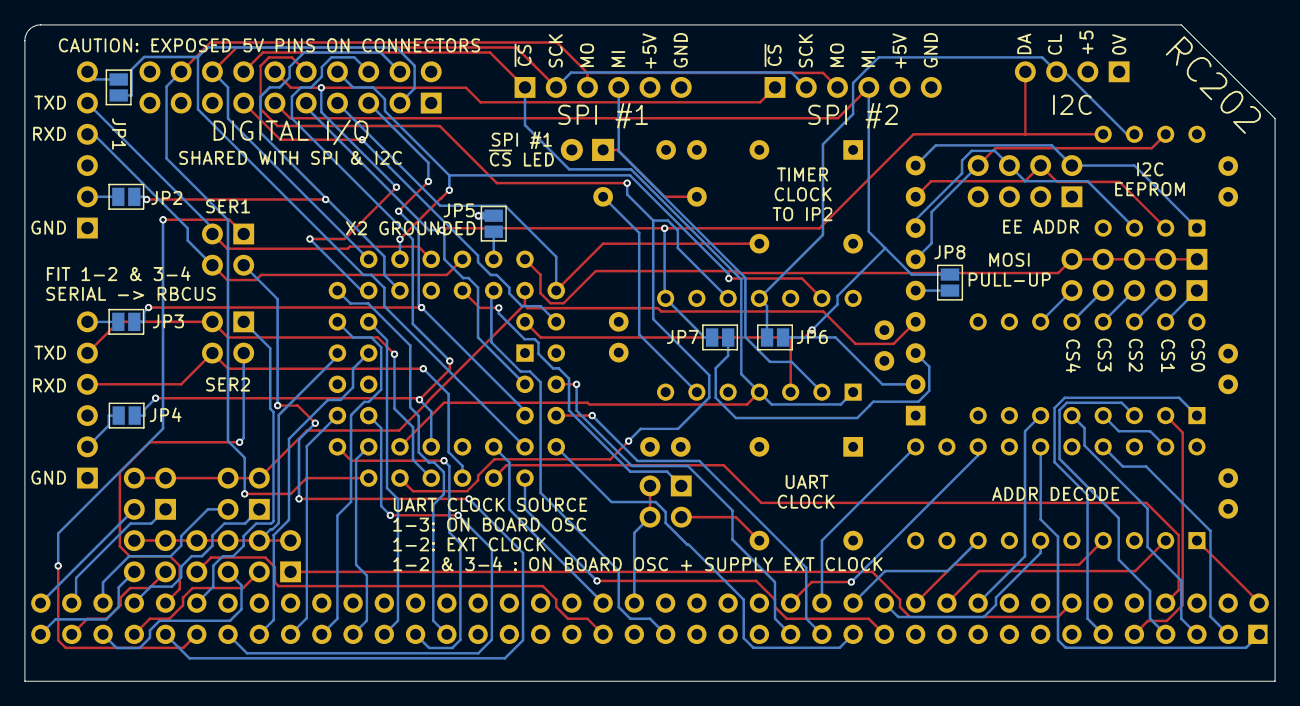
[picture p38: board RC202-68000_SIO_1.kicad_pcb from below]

Board: 4 copper layers, 101.6 x 53.3 mm, 41 parts (8 on the bottom side), 91 nets.

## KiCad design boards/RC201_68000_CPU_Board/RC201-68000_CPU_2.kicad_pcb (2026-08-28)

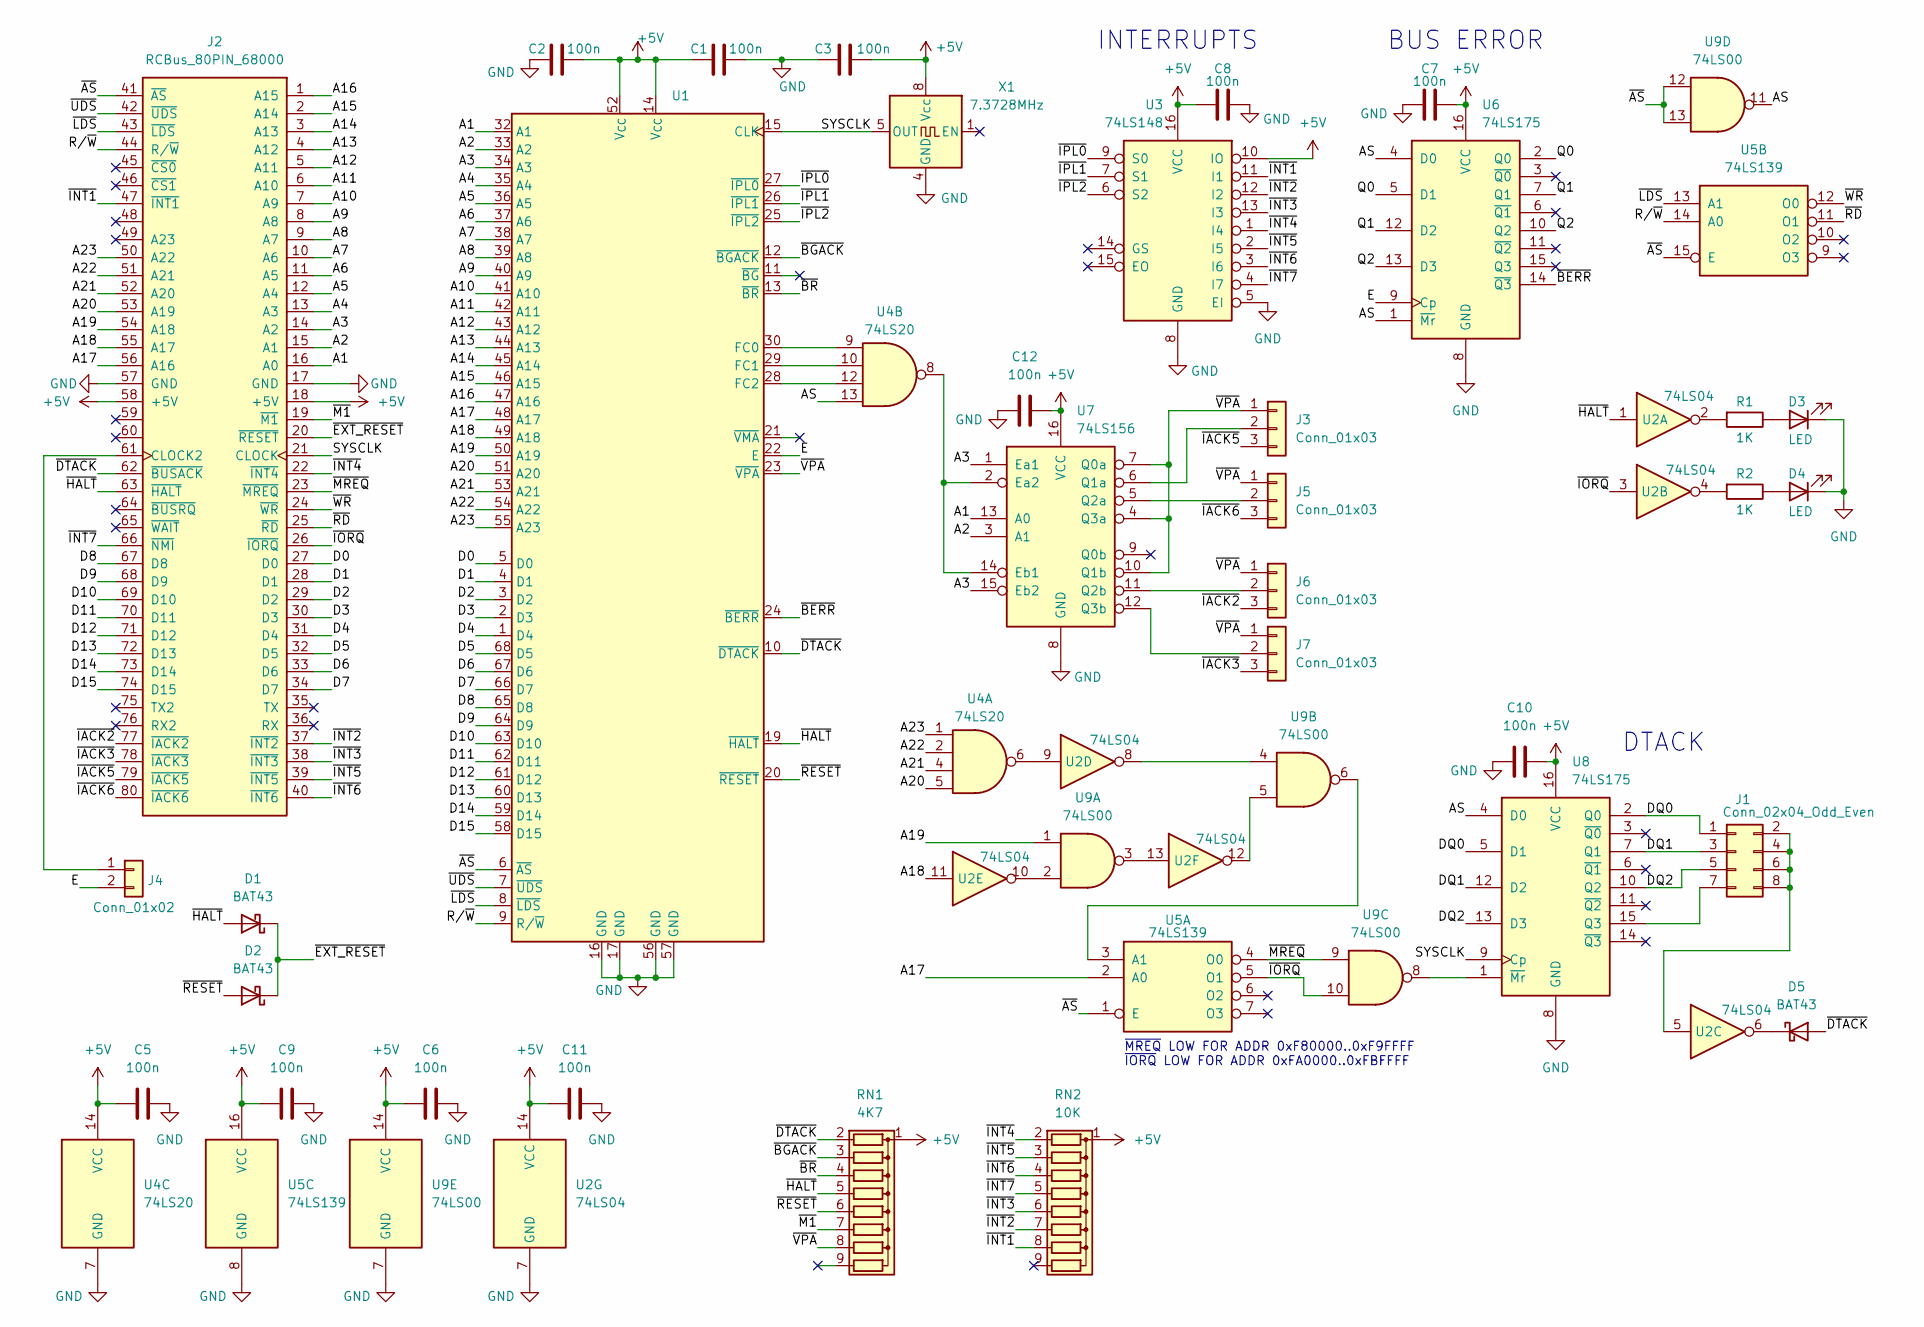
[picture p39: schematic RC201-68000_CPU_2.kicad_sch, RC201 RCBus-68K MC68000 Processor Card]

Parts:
C1, C2, C3, C5, C6, C7, C8, C9, C10, C11, C12: 100n; C_Disc_D5.0mm_W2.5mm_P2.50mm
D1, D2, D5: BAT43; D_DO-35_SOD27_P7.62mm_Horizontal
D3, D4: LED; LED_D3.0mm
J1: Conn_02x04_Odd_Even; PinHeader_2x04_P2.54mm_Vertical
J2: RCBus_80PIN_68000; RCBus_80p_Medium
J3, J5, J6, J7: Conn_01x03; PinHeader_1x03_P2.54mm_Vertical
J4: Conn_01x02; PinHeader_1x02_P2.54mm_Vertical
R1, R2: 1K; R_Axial_DIN0207_L6.3mm_D2.5mm_P7.62mm_Horizontal
RN1: 4K7; R_Array_SIP9
RN2: 10K; R_Array_SIP9
U1: PLCC-68_THT-Socket
U2: 74LS04; DIP-14_W7.62mm
U3: 74LS148; DIP-16_W7.62mm
U4: 74LS20; DIP-14_W7.62mm
U5: 74LS139; DIP-16_W7.62mm
U6, U8: 74LS175; DIP-16_W7.62mm
U7: 74LS156; DIP-16_W7.62mm
U9: 74LS00; DIP-14_W7.62mm
X1: 7.3728MHz; Oscillator_DIP-8

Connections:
+5V: C1.1, C2.2, C3.2, C5.1, C6.1, C7.2, C8.1, C9.1, C10.2, C11.1, C12.2, J2.18 (+5V), J2.58 (+5V), RN1.1 (common), RN2.1 (common), U1.14 (V_{CC}), U1.52 (V_{CC}), U2.14 (VCC), U3.10 (IO), U3.16 (VCC), U4.14 (VCC), U5.16 (VCC), U6.16 (VCC), U7.16 (VCC), U8.16 (VCC), U9.14 (VCC), X1.8 (Vcc)
/A1: J2.16 (A0), U1.32 (A1), U7.13 (A0)
/A2: J2.15 (A1), U1.33 (A2), U7.3 (A1)
/A3: J2.14 (A2), U1.34 (A3), U7.1 (Ea1), U7.15 (Eb2)
/A4: J2.13 (A3), U1.35 (A4)
/A5: J2.12 (A4), U1.36 (A5)
/A6: J2.11 (A5), U1.37 (A6)
/A7: J2.10 (A6), U1.38 (A7)
/A8: J2.9 (A7), U1.39 (A8)
/A9: J2.8 (A8), U1.40 (A9)
/A10: J2.7 (A9), U1.41 (A10)
/A11: J2.6 (A10), U1.42 (A11)
/A12: J2.5 (A11), U1.43 (A12)
/A13: J2.4 (A12), U1.44 (A13)
/A14: J2.3 (A13), U1.45 (A14)
/A15: J2.2 (A14), U1.46 (A15)
/A16: J2.1 (A15), U1.47 (A16)
/A17: J2.56 (A16), U1.48 (A17), U5.2 (A0)
/A18: J2.55 (A17), U1.49 (A18), U2.11
/A19: J2.54 (A18), U1.50 (A19), U9.1
/A20: J2.53 (A19), U1.51 (A20), U4.5
/A21: J2.52 (A20), U1.53 (A21), U4.4
/A22: J2.51 (A21), U1.54 (A22), U4.2
/A23: J2.50 (A22), U1.55 (A23), U4.1
/AS: U4.13, U6.1 (~Mr), U6.4 (D0), U8.4 (D0), U9.11
/D0: J2.27 (D0), U1.5 (D0)
/D1: J2.28 (D1), U1.4 (D1)
/D2: J2.29 (D2), U1.3 (D2)
/D3: J2.30 (D3), U1.2 (D3)
/D4: J2.31 (D4), U1.1 (D4)
/D5: J2.32 (D5), U1.68 (D5)
/D6: J2.33 (D6), U1.67 (D6)
/D7: J2.34 (D7), U1.66 (D7)
/D8: J2.67 (D8), U1.65 (D8)
/D9: J2.68 (D9), U1.64 (D9)
/D10: J2.69 (D10), U1.63 (D10)
/D11: J2.70 (D11), U1.62 (D11)
/D12: J2.71 (D12), U1.61 (D12)
/D13: J2.72 (D13), U1.60 (D13)
/D14: J2.73 (D14), U1.59 (D14)
/D15: J2.74 (D15), U1.58 (D15)
/DQ0: J1.1, U8.2 (Q0), U8.5 (D1)
/DQ1: J1.3, U8.7 (Q1), U8.12 (D2)
/DQ2: J1.5, U8.10 (Q2), U8.13 (D3)
/E: J4.2, U1.22 (E), U6.9 (Cp)
/Q0: U6.2 (Q0), U6.5 (D1)
/Q1: U6.7 (Q1), U6.12 (D2)
/Q2: U6.10 (Q2), U6.13 (D3)
/R/~W: J2.44 (R/~W), U1.9 (R/~W), U5.14 (A0)
/SYSCLK: J2.21 (CLOCK), U1.15 (CLK), U8.9 (Cp), X1.5 (OUT)
/~AS: J2.41 (~AS), U1.6 (~AS), U5.1 (E), U5.15 (E), U9.12, U9.13
/~BERR: U1.24 (~BERR), U6.14 (~Q3)
/~BGACK: RN1.3 (R2), U1.12 (~BGACK)
/~BR: RN1.4 (R3), U1.13 (~BR)
/~DTACK: D5.2 (A), J2.62 (~BUSACK), RN1.2 (R1), U1.10 (~DTACK)
/~EXT_RESET: D1.1 (K), D2.1 (K), J2.20 (~RESET)
/~HALT: D1.2 (A), J2.63 (~HALT), RN1.5 (R4), U1.19 (~HALT), U2.1
/~IACK2: J2.77 (~IACK2), J6.3
/~IACK3: J2.78 (~IACK3), J7.3
/~IACK5: J2.79 (~IACK5), J3.3
/~IACK6: J2.80 (~IACK6), J5.3
/~INT1: J2.47 (~INT1), RN2.8 (R7), U3.11 (I1)
/~INT2: J2.37 (~INT2), RN2.7 (R6), U3.12 (I2)
/~INT3: J2.38 (~INT3), RN2.6 (R5), U3.13 (I3)
/~INT4: J2.22 (~INT4), RN2.2 (R1), U3.1 (I4)
/~INT5: J2.39 (~INT5), RN2.3 (R2), U3.2 (I5)
/~INT6: J2.40 (~INT6), RN2.4 (R3), U3.3 (I6)
/~INT7: J2.66 (~NMI), RN2.5 (R4), U3.4 (I7)
/~IORQ: J2.26 (~IORQ), U2.3, U5.5 (O1), U9.10
/~IPL0: U1.27 (~IPL0), U3.9 (S0)
/~IPL1: U1.26 (~IPL1), U3.7 (S1)
/~IPL2: U1.25 (~IPL2), U3.6 (S2)
/~LDS: J2.43 (~LDS), U1.8 (~LDS), U5.13 (A1)
/~M1: J2.19 (~M1), RN1.7 (R6)
/~MREQ: J2.23 (~MREQ), U5.4 (O0), U9.9
/~RD: J2.25 (~RD), U5.11 (O1)
/~RESET: D2.2 (A), RN1.6 (R5), U1.20 (~RESET)
/~UDS: J2.42 (~UDS), U1.7 (~UDS)
/~VPA: J3.1, J5.1, J6.1, J7.1, RN1.8 (R7), U1.23 (~VPA), U7.4 (Q3a), U7.7 (Q0a), U7.10 (Q1b)
/~WR: J2.24 (~WR), U5.12 (O0)
GND: C1.2, C2.1, C3.1, C5.2, C6.2, C7.1, C8.2, C9.2, C10.1, C11.2, C12.1, D3.1 (K), D4.1 (K), J2.17 (GND), J2.57 (GND), U1.16 (GND), U1.17 (GND), U1.56 (GND), U1.57 (GND), U2.7 (GND), U3.5 (EI), U3.8 (GND), U4.7 (GND), U5.8 (GND), U6.8 (GND), U7.8 (GND), U8.8 (GND), U9.7 (GND), X1.4 (GND)
unnamed: D3.2 (A), R1.1
unnamed: D4.2 (A), R2.1
unnamed: D5.1 (K), U2.6
unnamed: J1.2, J1.4, J1.6, J1.8, U2.5
unnamed: J1.7, U8.15 (Q3)
unnamed: J2.61 (CLOCK2), J4.1
unnamed: J3.2, U7.6 (Q1a)
unnamed: J5.2, U7.5 (Q2a)
unnamed: J6.2, U7.11 (Q2b)
unnamed: J7.2, U7.12 (Q3b)
unnamed: R1.2, U2.2
unnamed: R2.2, U2.4
unnamed: U1.30 (FC0), U4.9
unnamed: U1.29 (FC1), U4.10
unnamed: U1.28 (FC2), U4.12
unnamed: U2.8, U9.4
unnamed: U2.9, U4.6
unnamed: U2.10, U9.2
unnamed: U2.12, U9.5
unnamed: U2.13, U9.3
unnamed: U5.3 (A1), U9.6
unnamed: U4.8, U7.2 (Ea2), U7.14 (Eb1)
unnamed: U8.1 (~Mr), U9.8

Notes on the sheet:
INTERRUPTS
DTACK
~{MREQ} LOW FOR ADDR 0xF80000..0xF9FFFF ~{IORQ} LOW FOR ADDR 0xFA0000..0xFBFFFF
BUS ERROR

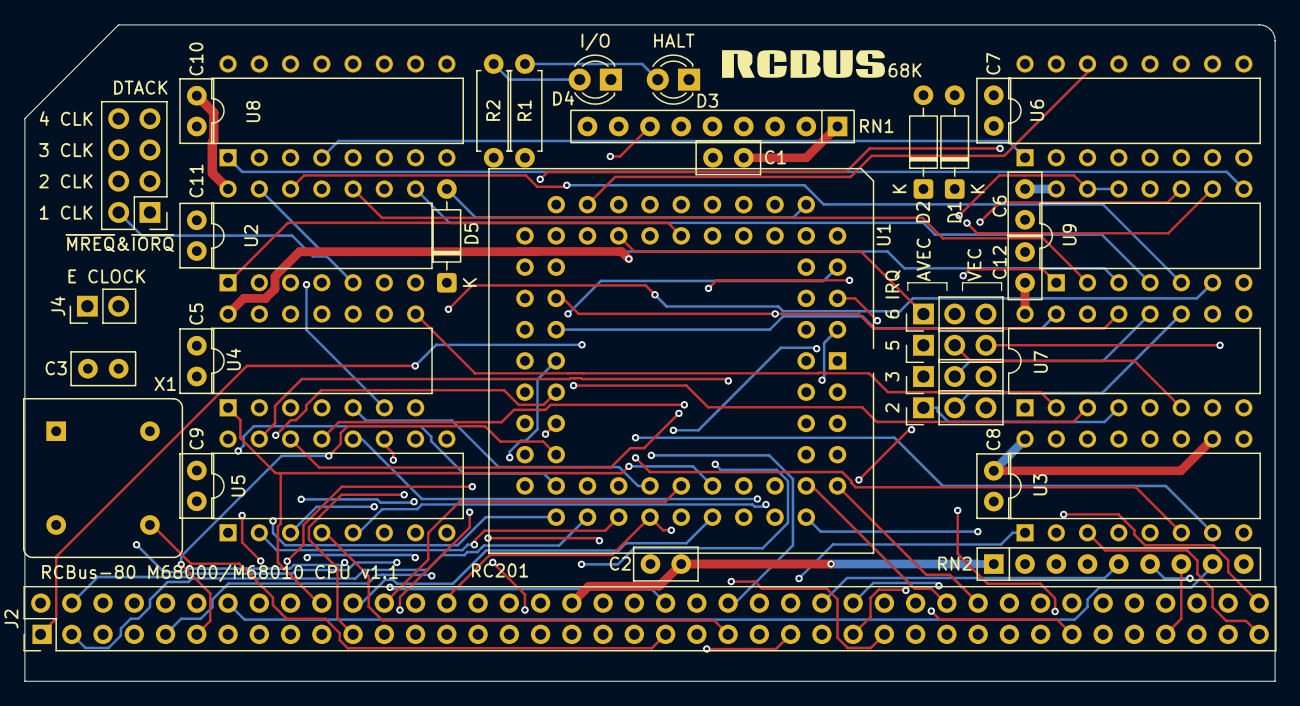
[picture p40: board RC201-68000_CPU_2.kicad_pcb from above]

Board: 4 copper layers, 101.6 x 53.3 mm, 37 parts (0 on the bottom side), 104 nets.

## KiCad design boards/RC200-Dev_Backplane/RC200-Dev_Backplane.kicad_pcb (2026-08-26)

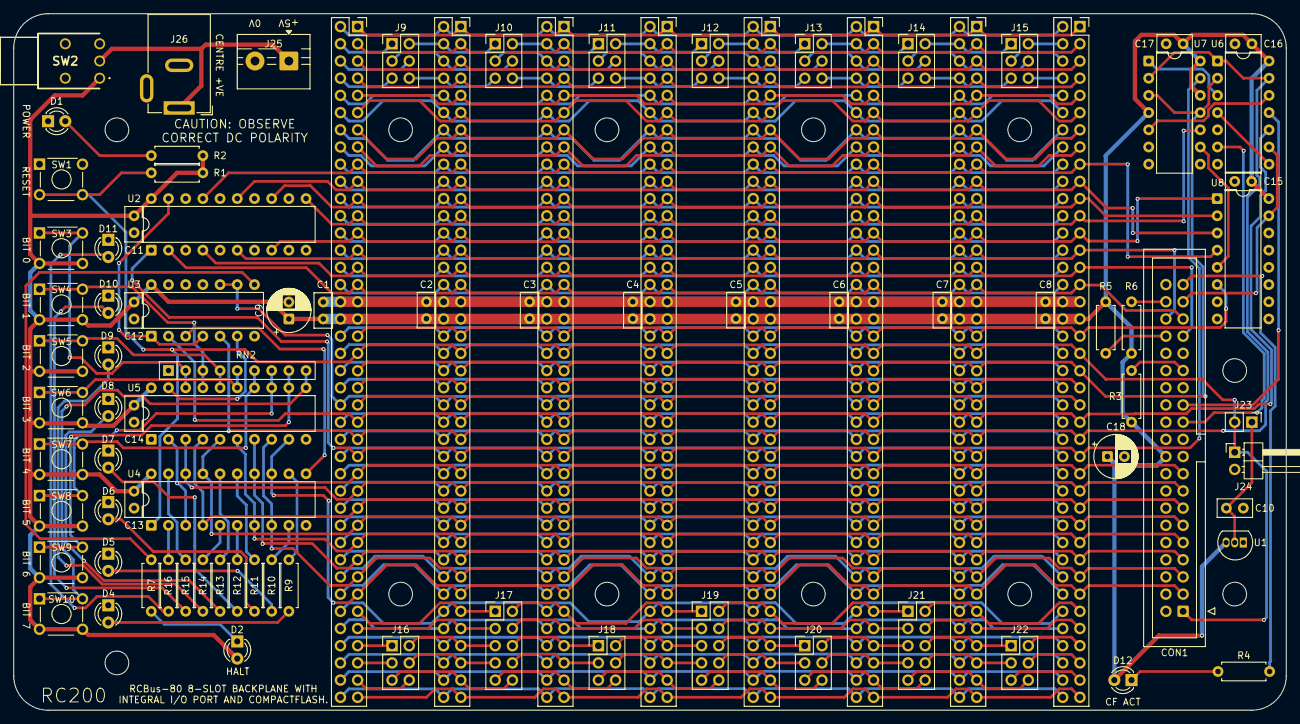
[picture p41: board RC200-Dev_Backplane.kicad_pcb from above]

Board: 2 copper layers, 188.0 x 102.9 mm, 102 parts (0 on the bottom side), 170 nets.

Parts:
C1, C2, C3, C4, C5, C6, C7, C8, C11, C12, C13, C14, C15, C16, C17: 100n; C_Disc_D5.0mm_W2.5mm_P2.50mm
C9, C18: 100uF; CP_Radial_D6.3mm_P2.50mm
C10: 1n; C_Disc_D5.0mm_W2.5mm_P2.50mm
CON1: CONN_IDE_02x20; IDC-Header_2x20_P2.54mm_Vertical
D1, D2, D4, D5, D6, D7, D8, D9, D10, D11, D12: LED; LED_D3.0mm
H1, H2, H3, H4, H5, H6, H7, H8, H9, H10, H11, H12: MountingHole; MountingHole_3.5mm
J1, J2, J3, J4, J5, J6, J7, J8: Conn_02x40_Top_Bottom; PinSocket_2x40_P2.54mm_Vertical_Top_Bottom
J9, J10, J11, J12, J13, J14, J15, J16, J18, J20, J22: Conn_02x03_Odd_Even; PinHeader_2x03_P2.54mm_Vertical
J17, J19, J21: Conn_02x05_Odd_Even; PinHeader_2x05_P2.54mm_Vertical
J23: Conn_01x02; PinHeader_1x02_P2.54mm_Vertical
J24: Conn_01x02; PinHeader_1x02_P2.54mm_Horizontal
J25: Conn_01x02; TerminalBlock_MaiXu_MX126-5.0-02P_1x02_P5.00mm
J26: Barrel_Jack_Switch; BarrelJack_GCT_DCJ200-10-A_Horizontal
R1: 10K; R_Axial_DIN0207_L6.3mm_D2.5mm_P7.62mm_Horizontal
R2, R4, R7, R9, R10, R11, R12, R13, R14, R15, R16: 1K; R_Axial_DIN0207_L6.3mm_D2.5mm_P7.62mm_Horizontal
R3, R5, R6: 4K7; R_Axial_DIN0207_L6.3mm_D2.5mm_P7.62mm_Horizontal
RN2: 1K; R_Array_SIP9
SW1, SW3, SW4, SW5, SW6, SW7, SW8, SW9, SW10: SW_Push; SW_TH_Tactile
SW2: SW_SPDT; 2MS1T2B2M6QES
U1: DS1233-10; TO-92L_Inline
U2: 74HCT688; DIP-20_W7.62mm
U3, U6: 74LS32; DIP-14_W7.62mm
U4: 74HCT273; DIP-20_W7.62mm
U5: 74LS245; DIP-20_W7.62mm
U7: 74LS74; DIP-14_W7.62mm
U8: 74LS138; DIP-16_W7.62mm

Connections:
+5V: C1.1, C2.1, C3.1, C4.1, C5.1, C6.1, C7.1, C8.1, C9.1, C11.2, C12.2, C13.2, C14.2, C15.2, C16.2, C17.2, C18.1, CON1.20 (KEY), D2.2 (A), D12.2 (A), J1.18, J1.58, J2.18, J2.58, J3.18, J3.58, J4.18, J4.58, J5.18, J5.58, J6.18, J6.58, J7.18, J7.58, J8.18, J8.58, R1.1, R2.1, R3.1, R5.1, R6.1, SW2.1 (A), SW3.2, SW4.2, SW5.2, SW6.2, SW7.2, SW8.2, SW9.2, SW10.2, U1.3 (VCC), U2.20 (VCC), U3.14 (VCC), U4.20 (VCC), U5.20 (VCC), U6.14 (VCC), U7.4 (~S), U7.12 (D), U7.14 (VCC), U8.16 (VCC)
/A0: CON1.35 (DA0), J1.16, J2.16, J3.16, J4.16, J5.16, J6.16, J7.16, J8.16, U2.2 (P0)
/A1: CON1.33 (DA1), J1.15, J2.15, J3.15, J4.15, J5.15, J6.15, J7.15, J8.15, U2.4 (P1)
/A2: CON1.36 (DA2), J1.14, J2.14, J3.14, J4.14, J5.14, J6.14, J7.14, J8.14, U2.6 (P2)
/A3: J1.13, J2.13, J3.13, J4.13, J5.13, J6.13, J7.13, J8.13, U2.8 (P3), U8.1 (A0)
/A4: J1.12, J2.12, J3.12, J4.12, J5.12, J6.12, J7.12, J8.12, U2.11 (P4), U7.10 (~S)
/A5: J1.11, J2.11, J3.11, J4.11, J5.11, J6.11, J7.11, J8.11, U2.13 (P5), U8.2 (A1)
/A6: J1.10, J2.10, J3.10, J4.10, J5.10, J6.10, J7.10, J8.10, U2.15 (P6), U8.3 (A2)
/A7: J1.9, J2.9, J3.9, J4.9, J5.9, J6.9, J7.9, J8.9, U2.17 (P7), U8.4 (E1)
/A8: J1.8, J2.8, J3.8, J4.8, J5.8, J6.8, J7.8, J8.8
/A9: J1.7, J2.7, J3.7, J4.7, J5.7, J6.7, J7.7, J8.7
/A10: J1.6, J2.6, J3.6, J4.6, J5.6, J6.6, J7.6, J8.6
/A11: J1.5, J2.5, J3.5, J4.5, J5.5, J6.5, J7.5, J8.5
/A12: J1.4, J2.4, J3.4, J4.4, J5.4, J6.4, J7.4, J8.4
/A13: J1.3, J2.3, J3.3, J4.3, J5.3, J6.3, J7.3, J8.3
/A14: J1.2, J2.2, J3.2, J4.2, J5.2, J6.2, J7.2, J8.2
/A15: J1.1, J2.1, J3.1, J4.1, J5.1, J6.1, J7.1, J8.1
/A16: J1.56, J2.56, J3.56, J4.56, J5.56, J6.56, J7.56, J8.56
/A17: J1.55, J2.55, J3.55, J4.55, J5.55, J6.55, J7.55, J8.55
/A18: J1.54, J2.54, J3.54, J4.54, J5.54, J6.54, J7.54, J8.54
/A19: J1.53, J2.53, J3.53, J4.53, J5.53, J6.53, J7.53, J8.53
/A20: J1.52, J2.52, J3.52, J4.52, J5.52, J6.52, J7.52, J8.52
/A21: J1.51, J2.51, J3.51, J4.51, J5.51, J6.51, J7.51, J8.51
/A22: J1.50, J2.50, J3.50, J4.50, J5.50, J6.50, J7.50, J8.50
/A23: J1.49, J2.49, J3.49, J4.49, J5.49, J6.49, J7.49, J8.49
/CLK: J1.21, J2.21, J3.21, J4.21, J5.21, J6.21, J7.21, J8.21, U6.2, U7.3 (C), U7.11 (C)
/CLK2: J1.61, J2.61, J3.61, J4.61, J5.61, J6.61, J7.61, J8.61
/D0: CON1.17 (D0), J1.27, J2.27, J3.27, J4.27, J5.27, J6.27, J7.27, J8.27, U4.3 (D0), U5.2 (A0)
/D1: CON1.15 (D1), J1.28, J2.28, J3.28, J4.28, J5.28, J6.28, J7.28, J8.28, U4.18 (D7), U5.3 (A1)
/D2: CON1.13 (D2), J1.29, J2.29, J3.29, J4.29, J5.29, J6.29, J7.29, J8.29, U4.4 (D1), U5.4 (A2)
/D3: CON1.11 (D3), J1.30, J2.30, J3.30, J4.30, J5.30, J6.30, J7.30, J8.30, U4.17 (D6), U5.5 (A3)
/D4: CON1.9 (D4), J1.31, J2.31, J3.31, J4.31, J5.31, J6.31, J7.31, J8.31, U4.7 (D2), U5.6 (A4)
/D5: CON1.7 (D5), J1.32, J2.32, J3.32, J4.32, J5.32, J6.32, J7.32, J8.32, U4.14 (D5), U5.7 (A5)
/D6: CON1.5 (D6), J1.33, J2.33, J3.33, J4.33, J5.33, J6.33, J7.33, J8.33, U4.8 (D3), U5.8 (A6)
/D7: CON1.3 (D7), J1.34, J2.34, J3.34, J4.34, J5.34, J6.34, J7.34, J8.34, U4.13 (D4), U5.9 (A7)
/D8: J1.67, J2.67, J3.67, J4.67, J5.67, J6.67, J7.67, J8.67
/D9: J1.68, J2.68, J3.68, J4.68, J5.68, J6.68, J7.68, J8.68
/D10: J1.69, J2.69, J3.69, J4.69, J5.69, J6.69, J7.69, J8.69
/D11: J1.70, J2.70, J3.70, J4.70, J5.70, J6.70, J7.70, J8.70
/D12: J1.71, J2.71, J3.71, J4.71, J5.71, J6.71, J7.71, J8.71
/D13: J1.72, J2.72, J3.72, J4.72, J5.72, J6.72, J7.72, J8.72
/D14: J1.73, J2.73, J3.73, J4.73, J5.73, J6.73, J7.73, J8.73
/D15: J1.74, J2.74, J3.74, J4.74, J5.74, J6.74, J7.74, J8.74
/HALT_LED: R7.2, U3.8
/PAGE: J1.60, J2.60, J3.60, J4.60, J5.60, J6.60, J7.60, J8.60
/PB1: RN2.2 (R1), SW3.1, U5.18 (B0)
/PB2: RN2.3 (R2), SW4.1, U5.17 (B1)
/PB3: RN2.4 (R3), SW5.1, U5.16 (B2)
/PB4: RN2.5 (R4), SW6.1, U5.15 (B3)
/PB5: RN2.6 (R5), SW7.1, U5.14 (B4)
/PB6: RN2.7 (R6), SW8.1, U5.13 (B5)
/PB7: RN2.8 (R7), SW9.1, U5.12 (B6)
/PB8: RN2.9 (R8), SW10.1, U5.11 (B7)
/RX2: J1.76, J2.76, J3.76, J4.76, J5.76, J6.76, J7.76, J8.76
/RX_A: J1.36, J2.36, J17.3
/RX_B: J3.36, J4.36, J17.4, J19.3
/RX_C: J5.36, J6.36, J19.4, J21.3
/RX_D: J7.36, J8.36, J21.4
/TX2: J1.75, J2.75, J3.75, J4.75, J5.75, J6.75, J7.75, J8.75
/TX_A: J1.35, J2.35, J17.1
/TX_B: J3.35, J4.35, J17.2, J19.1
/TX_C: J5.35, J6.35, J19.2, J21.1
/TX_D: J7.35, J8.35, J21.2
/n37_a: J1.37, J16.1
/n37_b: J2.37, J16.2, J17.5
/n37_c: J3.37, J17.6, J18.1
/n37_d: J4.37, J18.2, J19.5
/n37_e: J5.37, J19.6, J20.1
/n37_f: J6.37, J20.2, J21.5
/n37_g: J7.37, J21.6, J22.1
/n37_h: J8.37, J22.2
/n38_a: J1.38, J16.3
/n38_b: J2.38, J16.4, J17.7
/n38_c: J3.38, J17.8, J18.3
/n38_d: J4.38, J18.4, J19.7
/n38_e: J5.38, J19.8, J20.3
/n38_f: J6.38, J20.4, J21.7
/n38_g: J7.38, J21.8, J22.3
/n38_h: J8.38, J22.4
/n39_a: J1.39, J16.6
/n39_b: J2.39, J16.5, J17.10
/n39_c: J3.39, J17.9, J18.6
/n39_d: J4.39, J18.5, J19.10
/n39_e: J5.39, J19.9, J20.6
/n39_f: J6.39, J20.5, J21.10
/n39_g: J7.39, J21.9, J22.6
/n39_h: J8.39, J22.5
/n40: J1.40, J2.40, J3.40, J4.40, J5.40, J6.40, J7.40, J8.40
/n41: J1.41, J2.41, J3.41, J4.41, J5.41, J6.41, J7.41, J8.41
/n42_a: J1.42, J9.1
/n42_b: J2.42, J9.2, J10.1
/n42_c: J3.42, J10.2, J11.1
/n42_d: J4.42, J11.2, J12.1
/n42_e: J5.42, J12.2, J13.1
/n42_f: J6.42, J13.2, J14.1
/n42_g: J7.42, J14.2, J15.1
/n42_h: J8.42, J15.2
/n43_a: J1.43, J9.4
/n43_b: J2.43, J9.3, J10.4
/n43_c: J3.43, J10.3, J11.4
/n43_d: J4.43, J11.3, J12.4
/n43_e: J5.43, J12.3, J13.4
/n43_f: J6.43, J13.3, J14.4
/n43_g: J7.43, J14.3, J15.4
/n43_h: J8.43, J15.3
/n44_a: J1.44, J9.5
/n44_b: J2.44, J9.6, J10.5
/n44_c: J3.44, J10.6, J11.5
/n44_d: J4.44, J11.6, J12.5
/n44_e: J5.44, J12.6, J13.5
/n44_f: J6.44, J13.6, J14.5
/n44_g: J7.44, J14.6, J15.5
/n44_h: J8.44, J15.6
/n45: J1.45, J2.45, J3.45, J4.45, J5.45, J6.45, J7.45, J8.45
/n46: J1.46, J2.46, J3.46, J4.46, J5.46, J6.46, J7.46, J8.46
/n47: J1.47, J2.47, J3.47, J4.47, J5.47, J6.47, J7.47, J8.47
/n48: J1.48, J2.48, J3.48, J4.48, J5.48, J6.48, J7.48, J8.48
/n77: J1.77, J2.77, J3.77, J4.77, J5.77, J6.77, J7.77, J8.77
/n78: J1.78, J2.78, J3.78, J4.78, J5.78, J6.78, J7.78, J8.78
/n79: J1.79, J2.79, J3.79, J4.79, J5.79, J6.79, J7.79, J8.79
/n80: J1.80, J2.80, J3.80, J4.80, J5.80, J6.80, J7.80, J8.80
/~BUSAK: J1.62, J2.62, J3.62, J4.62, J5.62, J6.62, J7.62, J8.62
/~BUSRQ: J1.64, J2.64, J3.64, J4.64, J5.64, J6.64, J7.64, J8.64
/~CS_CF: CON1.37 (~CS1FX), U6.9, U8.15 (O0)
/~HALT: J1.63, J2.63, J3.63, J4.63, J5.63, J6.63, J7.63, J8.63, U3.9, U3.10
/~INT: J1.22, J2.22, J3.22, J4.22, J5.22, J6.22, J7.22, J8.22
/~IORD: CON1.25 (~DIOR), U6.11
/~IORQ: J1.26, J2.26, J3.26, J4.26, J5.26, J6.26, J7.26, J8.26, U2.1 (G), U7.13 (~R)
/~IOWR: CON1.23 (~DIOW), U6.6
/~M1: J1.19, J2.19, J3.19, J4.19, J5.19, J6.19, J7.19, J8.19, U8.6 (E3)
/~MREQ: J1.23, J2.23, J3.23, J4.23, J5.23, J6.23, J7.23, J8.23
/~NMI: J1.66, J2.66, J3.66, J4.66, J5.66, J6.66, J7.66, J8.66
/~RD: J1.25, J2.25, J3.25, J4.25, J5.25, J6.25, J7.25, J8.25, U3.5, U6.1, U6.13, U7.2 (D)
/~RESET: CON1.1 (~RESET), J1.20, J2.20, J3.20, J4.20, J5.20, J6.20, J7.20, J8.20, J23.2, J24.1, R1.2, SW1.2, U4.1 (~Mr)
/~RFSH: J1.59, J2.59, J3.59, J4.59, J5.59, J6.59, J7.59, J8.59
/~WAIT: J1.65, J2.65, J3.65, J4.65, J5.65, J6.65, J7.65, J8.65
/~WR: J1.24, J2.24, J3.24, J4.24, J5.24, J6.24, J7.24, J8.24, U3.2, U6.10
GND: C1.2, C2.2, C3.2, C4.2, C5.2, C6.2, C7.2, C8.2, C9.2, C10.2, C11.1, C12.1, C13.1, C14.1, C15.1, C16.1, C17.1, C18.2, CON1.2 (GND), CON1.19 (GND), CON1.22 (GND), CON1.24 (GND), CON1.26 (GND), CON1.30 (GND), CON1.40 (GND), D1.1 (K), D4.1 (K), D5.1 (K), D6.1 (K), D7.1 (K), D8.1 (K), D9.1 (K), D10.1 (K), D11.1 (K), J1.17, J1.57, J2.17, J2.57, J3.17, J3.57, J4.17, J4.57, J5.17, J5.57, J6.17, J6.57, J7.17, J7.57, J8.17, J8.57, J24.2, J25.2, J26.2, J26.3, RN2.1 (common), SW1.1, U1.1 (GND), U2.3 (R0), U2.5 (R1), U2.7 (R2), U2.9 (R3), U2.10 (GND), U2.12 (R4), U2.14 (R5), U2.16 (R6), U2.18 (R7), U3.7 (GND), U3.12, U3.13, U4.10 (GND), U5.1 (A->B), U5.10 (GND), U6.5, U6.7 (GND), U7.7 (GND), U8.8 (GND)
unnamed: CON1.38 (~CS3FX), R6.2
unnamed: CON1.39 (~DASP), R4.2
unnamed: CON1.29 (~DMACK), R3.2
unnamed: CON1.34 (~PDIAG), R5.2
unnamed: D1.2 (A), R2.2
unnamed: D2.1 (K), R7.1
unnamed: D4.2 (A), R9.2
unnamed: D5.2 (A), R10.2
unnamed: D6.2 (A), R11.2
unnamed: D7.2 (A), R12.2
unnamed: D8.2 (A), R13.2
unnamed: D9.2 (A), R14.2
unnamed: D10.2 (A), R15.2
unnamed: D11.2 (A), R16.2
unnamed: D12.1 (K), R4.1
unnamed: C10.1, J23.1, U1.2 (~RESET)
unnamed: J25.1, J26.1, SW2.2 (B)
unnamed: U2.19 (P=R), U3.1, U3.4
unnamed: U3.3, U4.11 (Cp)
unnamed: R16.1, U4.2 (Q0)
unnamed: R14.1, U4.5 (Q1)
unnamed: R12.1, U4.6 (Q2)
unnamed: R10.1, U4.9 (Q3)
unnamed: R9.1, U4.12 (Q4)
unnamed: R11.1, U4.15 (Q5)
unnamed: R13.1, U4.16 (Q6)
unnamed: R15.1, U4.19 (Q7)
unnamed: U3.6, U5.19 (CE)
unnamed: U6.4, U6.8
unnamed: U6.12, U7.5 (Q)
unnamed: U6.3, U7.1 (~R)
unnamed: U7.9 (Q), U8.5 (E2)

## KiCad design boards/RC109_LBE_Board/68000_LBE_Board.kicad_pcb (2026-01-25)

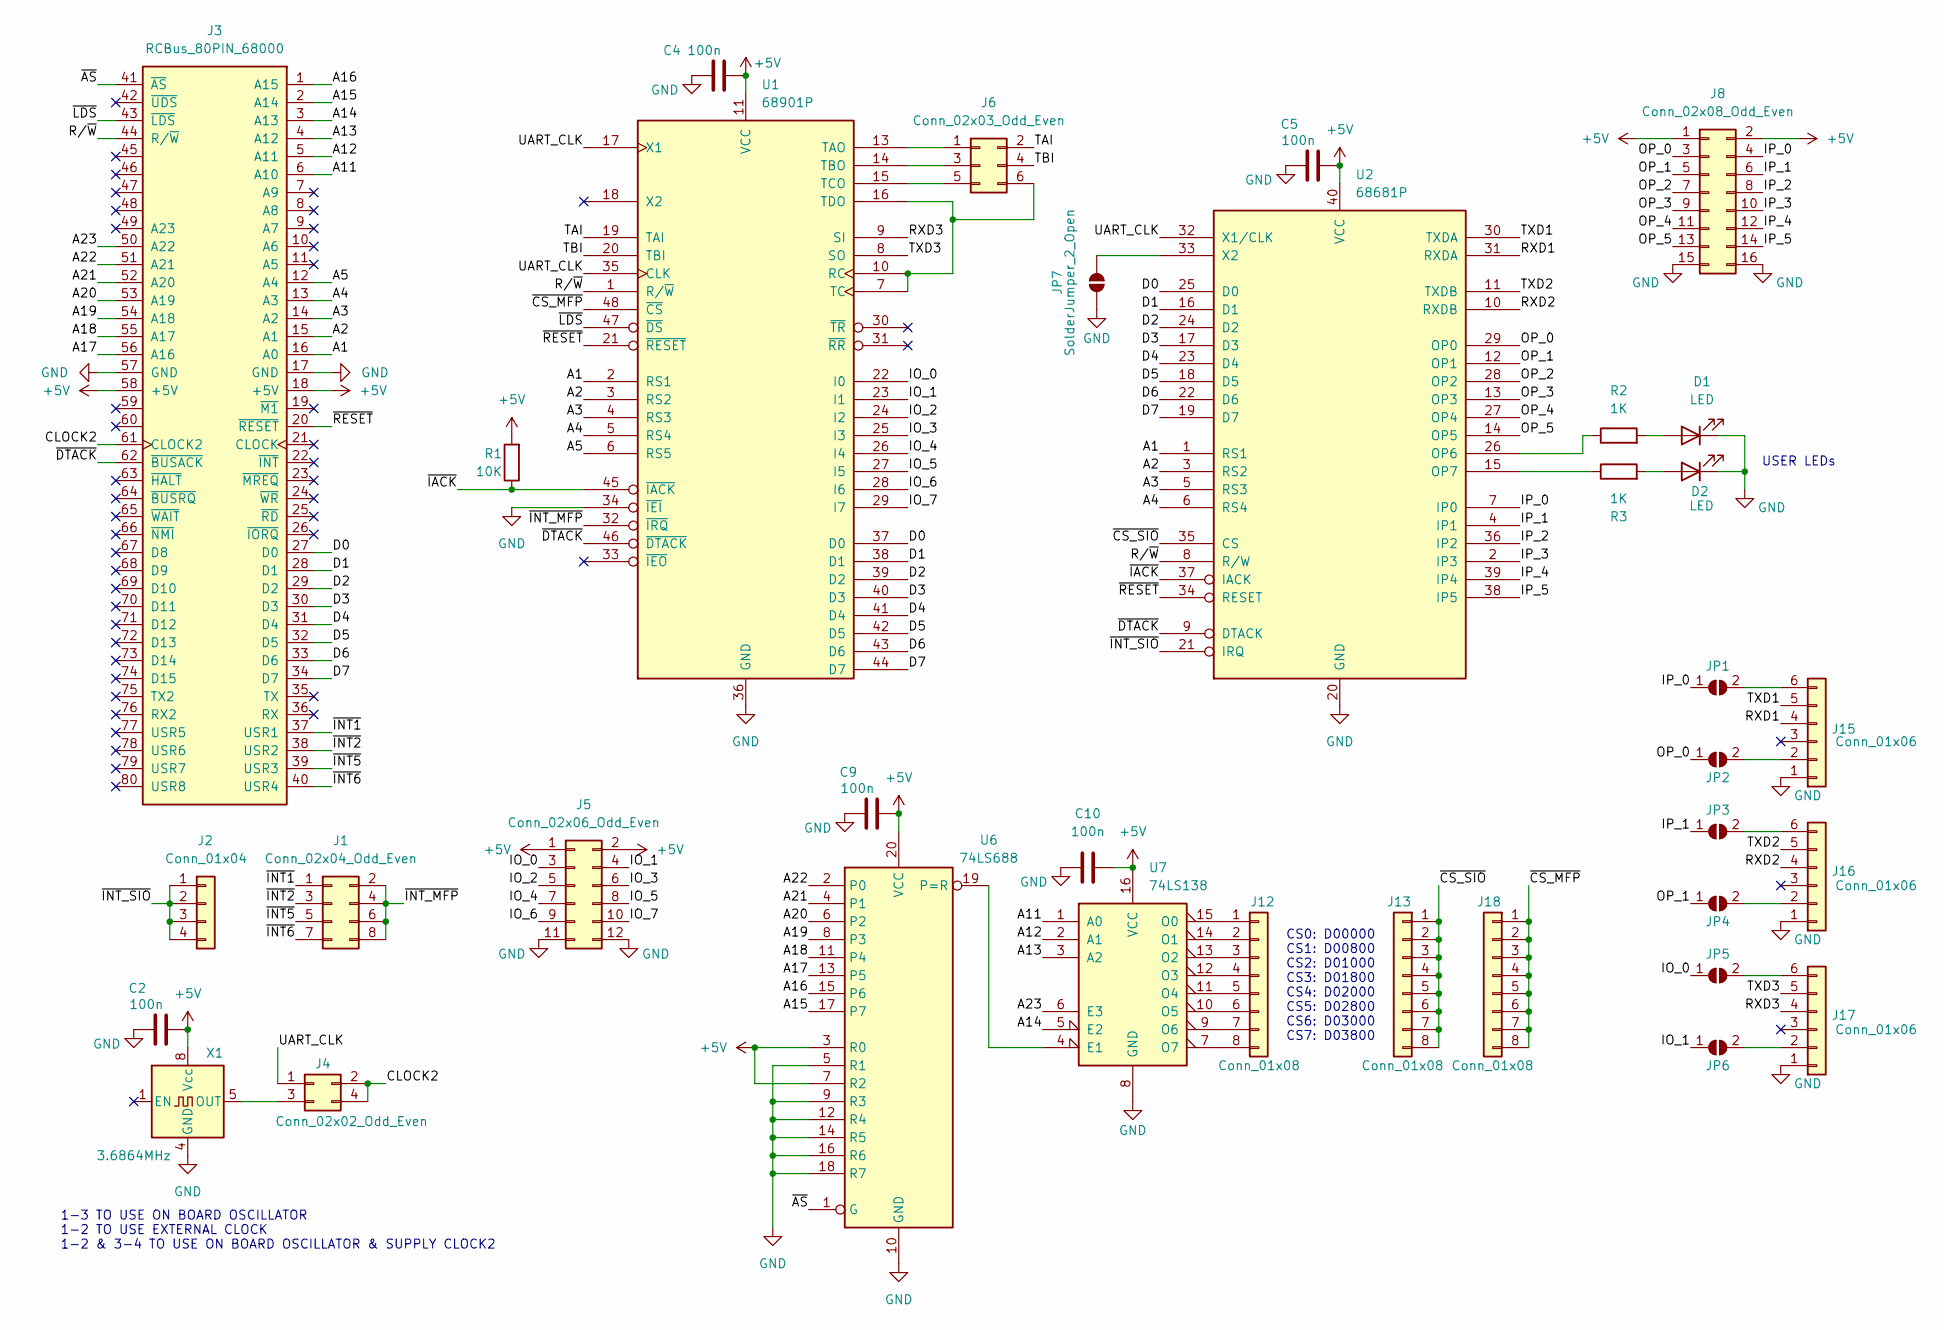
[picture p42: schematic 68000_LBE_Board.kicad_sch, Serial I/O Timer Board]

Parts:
C2, C4, C5, C9, C10: 100n; C_Disc_D5.0mm_W2.5mm_P2.50mm
D1, D2: LED; LED_D3.0mm
J1: Conn_02x04_Odd_Even; PinHeader_2x04_P2.54mm_Vertical
J2: Conn_01x04; PinHeader_1x04_P2.54mm_Vertical
J3: RCBus_80PIN_68000; RCBus_80p_Medium
J4: Conn_02x02_Odd_Even; PinHeader_2x02_P2.54mm_Vertical
J5: Conn_02x06_Odd_Even; PinHeader_2x06_P2.54mm_Horizontal
J6: Conn_02x03_Odd_Even; PinHeader_2x03_P2.54mm_Horizontal
J8: Conn_02x08_Odd_Even; PinHeader_2x08_P2.54mm_Horizontal
J12, J13, J18: Conn_01x08; PinHeader_1x08_P2.54mm_Vertical
J15, J16, J17: Conn_01x06; PinSocket_1x06_P2.54mm_Horizontal
JP1, JP2, JP3, JP4, JP5, JP6: SolderJumper; SolderJumper-2_P1.3mm_Open_Pad1.0x1.5mm
JP7: SolderJumper_2_Open; SolderJumper-2_P1.3mm_Open_Pad1.0x1.5mm
R1: 10K; R_Axial_DIN0207_L6.3mm_D2.5mm_P7.62mm_Horizontal
R2, R3: 1K; R_Axial_DIN0207_L6.3mm_D2.5mm_P7.62mm_Horizontal
U1: 68901P; DIP-48_W15.24mm
U2: 68681P; DIP-40_W15.24mm_Socket
U6: 74LS688; DIP-20_W7.62mm_Socket
U7: 74LS138; DIP-16_W7.62mm_Socket
X1: 3.6864MHz; Oscillator_DIP-8

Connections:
+5V: C2.2, C4.2, C5.2, C9.2, C10.2, J3.18 (+5V), J3.58 (+5V), J5.1, J5.2, J8.1, J8.2, R1.2, U1.11 (VCC), U2.40 (VCC), U6.3 (R0), U6.7 (R2), U6.20 (VCC), U7.16 (VCC), X1.8 (Vcc)
/A1: J3.16 (A0), U1.2 (RS1), U2.1 (RS1)
/A2: J3.15 (A1), U1.3 (RS2), U2.3 (RS2)
/A3: J3.14 (A2), U1.4 (RS3), U2.5 (RS3)
/A4: J3.13 (A3), U1.5 (RS4), U2.6 (RS4)
/A5: J3.12 (A4), U1.6 (RS5)
/A11: J3.6 (A10), U7.1 (A0)
/A12: J3.5 (A11), U7.2 (A1)
/A13: J3.4 (A12), U7.3 (A2)
/A14: J3.3 (A13), U7.5 (E2)
/A15: J3.2 (A14), U6.17 (P7)
/A16: J3.1 (A15), U6.15 (P6)
/A17: J3.56 (A16), U6.13 (P5)
/A18: J3.55 (A17), U6.11 (P4)
/A19: J3.54 (A18), U6.8 (P3)
/A20: J3.53 (A19), U6.6 (P2)
/A21: J3.52 (A20), U6.4 (P1)
/A22: J3.51 (A21), U6.2 (P0)
/A23: J3.50 (A22), U7.6 (E3)
/CLOCK2: J3.61 (CLOCK2), J4.2, J4.4
/D0: J3.27 (D0), U1.37 (D0), U2.25 (D0)
/D1: J3.28 (D1), U1.38 (D1), U2.16 (D1)
/D2: J3.29 (D2), U1.39 (D2), U2.24 (D2)
/D3: J3.30 (D3), U1.40 (D3), U2.17 (D3)
/D4: J3.31 (D4), U1.41 (D4), U2.23 (D4)
/D5: J3.32 (D5), U1.42 (D5), U2.18 (D5)
/D6: J3.33 (D6), U1.43 (D6), U2.22 (D6)
/D7: J3.34 (D7), U1.44 (D7), U2.19 (D7)
/IO_0: J5.3, JP5.1 (A), U1.22 (I0)
/IO_1: J5.4, JP6.1 (A), U1.23 (I1)
/IO_2: J5.5, U1.24 (I2)
/IO_3: J5.6, U1.25 (I3)
/IO_4: J5.7, U1.26 (I4)
/IO_5: J5.8, U1.27 (I5)
/IO_6: J5.9, U1.28 (I6)
/IO_7: J5.10, U1.29 (I7)
/IP_0: J8.4, JP1.1 (A), U2.7 (IP0)
/IP_1: J8.6, JP3.1 (A), U2.4 (IP1)
/IP_2: J8.8, U2.36 (IP2)
/IP_3: J8.10, U2.2 (IP3)
/IP_4: J8.12, U2.39 (IP4)
/IP_5: J8.14, U2.38 (IP5)
/OP_0: J8.3, JP2.1 (A), U2.29 (OP0)
/OP_1: J8.5, JP4.1 (A), U2.12 (OP1)
/OP_2: J8.7, U2.28 (OP2)
/OP_3: J8.9, U2.13 (OP3)
/OP_4: J8.11, U2.27 (OP4)
/OP_5: J8.13, U2.14 (OP5)
/RXD1: J15.4, U2.31 (RXDA)
/RXD2: J16.4, U2.10 (RXDB)
/RXD3: J17.4, U1.9 (SI)
/R/~W: J3.44 (R/~W), U1.1 (R/~W), U2.8 (R/W)
/TAI: J6.2, U1.19 (TAI)
/TBI: J6.4, U1.20 (TBI)
/TXD1: J15.5, U2.30 (TXDA)
/TXD2: J16.5, U2.11 (TXDB)
/TXD3: J17.5, U1.8 (SO)
/UART_CLK: J4.1, U1.17 (X1), U1.35 (CLK), U2.32 (X1/CLK)
/~AS: J3.41 (~AS), U6.1 (G)
/~CS_MFP: J18.1, J18.2, J18.3, J18.4, J18.5, J18.6, J18.7, J18.8, U1.48 (~CS)
/~CS_SIO: J13.1, J13.2, J13.3, J13.4, J13.5, J13.6, J13.7, J13.8, U2.35 (CS)
/~DTACK: J3.62 (~BUSACK), U1.46 (~DTACK), U2.9 (DTACK)
/~IACK: R1.1, U1.45 (~IACK), U2.37 (IACK)
/~INT1: J1.1, J3.37 (USR1)
/~INT2: J1.3, J3.38 (USR2)
/~INT5: J1.5, J3.39 (USR3)
/~INT6: J1.7, J3.40 (USR4)
/~INT_MFP: J1.2, J1.4, J1.6, J1.8, U1.32 (~IRQ)
/~INT_SIO: J2.1, J2.2, J2.3, J2.4, U2.21 (IRQ)
/~LDS: J3.43 (~LDS), U1.47 (~DS)
/~RESET: J3.20 (~RESET), U1.21 (~RESET), U2.34 (RESET)
GND: C2.1, C4.1, C5.1, C9.1, C10.1, D1.1 (K), D2.1 (K), J3.17 (GND), J3.57 (GND), J5.11, J5.12, J8.15, J8.16, J15.1, J16.1, J17.1, JP7.1 (A), U1.34 (~IEI), U1.36 (GND), U2.20 (GND), U6.5 (R1), U6.9 (R3), U6.10 (GND), U6.12 (R4), U6.14 (R5), U6.16 (R6), U6.18 (R7), U7.8 (GND), X1.4 (GND)
unnamed: D1.2 (A), R2.2
unnamed: D2.2 (A), R3.2
unnamed: J4.3, X1.5 (OUT)
unnamed: J6.1, U1.13 (TAO)
unnamed: J6.3, U1.14 (TBO)
unnamed: J6.5, U1.15 (TCO)
unnamed: J6.6, U1.7 (TC), U1.10 (RC), U1.16 (TDO)
unnamed: J12.1, U7.15 (O0)
unnamed: J12.2, U7.14 (O1)
unnamed: J12.3, U7.13 (O2)
unnamed: J12.4, U7.12 (O3)
unnamed: J12.5, U7.11 (O4)
unnamed: J12.6, U7.10 (O5)
unnamed: J12.7, U7.9 (O6)
unnamed: J12.8, U7.7 (O7)
unnamed: J15.2, JP2.2 (B)
unnamed: J15.6, JP1.2 (B)
unnamed: J16.2, JP4.2 (B)
unnamed: J16.6, JP3.2 (B)
unnamed: J17.2, JP6.2 (B)
unnamed: J17.6, JP5.2 (B)
unnamed: JP7.2 (B), U2.33 (X2)
unnamed: R2.1, U2.26 (OP6)
unnamed: R3.1, U2.15 (OP7)
unnamed: U6.19 (P=R), U7.4 (E1)

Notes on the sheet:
USER LEDs
1-3 TO USE ON BOARD OSCILLATOR 1-2 TO USE EXTERNAL CLOCK 1-2 & 3-4 TO USE ON BOARD OSCILLATOR & SUPPLY CLOCK2
CS0: D00000 CS1: D00800 CS2: D01000 CS3: D01800 CS4: D02000 CS5: D02800 CS6: D03000 CS7: D03800



Board: 4 copper layers, 101.6 x 53.3 mm, 35 parts (7 on the bottom side), 97 nets.

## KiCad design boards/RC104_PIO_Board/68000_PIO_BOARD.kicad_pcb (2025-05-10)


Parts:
C1, C2, C3, C4: 100n; C_Disc_D5.0mm_W2.5mm_P2.50mm
J1, J4, J5: Conn_02x08_Odd_Even; PinHeader_2x08_P2.54mm_Vertical
J2, J6: Conn_01x03; PinHeader_1x03_P2.54mm_Vertical
J3: RCBus_80PIN_68000; RCBus_80p_Medium
J7, J12, J13: Conn_01x08; PinHeader_1x08_P2.54mm_Vertical
J8, J9, J10, J11: Conn_02x04_Odd_Even; PinHeader_2x04_P2.54mm_Vertical
J14: Conn_02x03_Odd_Even; PinSocket_2x03_P2.54mm_Vertical
J15: Conn_01x06; PinSocket_1x06_P2.54mm_Vertical
U1, U2: 68230; DIP-48_W15.24mm_Socket
U3: 74LS138; DIP-16_W7.62mm_Socket
U4: 74LS688; DIP-20_W7.62mm_Socket

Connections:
+5V: C1.1, C2.1, C3.2, C4.2, J3.18 (+5V), J3.58 (+5V), J15.1, J15.2, J15.3, J15.4, J15.5, J15.6, U1.12 (VCC), U2.12 (VCC), U3.16 (VCC), U4.3 (R0), U4.7 (R2), U4.18 (R7), U4.20 (VCC)
/A1: J3.16 (A0), U1.29 (RS1), U2.29 (RS1)
/A2: J3.15 (A1), U1.28 (RS2), U2.28 (RS2)
/A3: J3.14 (A2), U1.27 (RS3), U2.27 (RS3)
/A4: J3.13 (A3), U1.26 (RS4), U2.26 (RS4)
/A5: U1.25 (RS5), U2.25 (RS5)
/A11: J3.6 (A10), U3.1 (A0)
/A12: J3.5 (A11), U3.2 (A1)
/A13: J3.4 (A12), U3.3 (A2)
/A14: J3.3 (A13), U3.5 (E2)
/A15: J3.2 (A14), U4.17 (P7)
/A16: J3.1 (A15), U4.15 (P6)
/A17: J3.56 (A16), U4.13 (P5)
/A18: J3.55 (A17), U4.11 (P4)
/A19: J3.54 (A18), U4.8 (P3)
/A20: J3.53 (A19), U4.6 (P2)
/A21: J3.52 (A20), U4.4 (P1)
/A22: J3.51 (A21), U4.2 (P0)
/A23: J3.50 (A22), U3.6 (E3)
/CLOCK: J2.1, J3.21 (CLOCK), J6.1
/CLOCK2: J2.3, J3.61 (CLOCK2), J6.3
/D0: J3.27 (D0), U1.44 (D0), U2.44 (D0)
/D1: J3.28 (D1), U1.45 (D1), U2.45 (D1)
/D2: J3.29 (D2), U1.46 (D2), U2.46 (D2)
/D3: J3.30 (D3), U1.47 (D3), U2.47 (D3)
/D4: J3.31 (D4), U1.48 (D4), U2.48 (D4)
/D5: J3.32 (D5), U1.1 (D5), U2.1 (D5)
/D6: J3.33 (D6), U1.2 (D6), U2.2 (D6)
/D7: J3.34 (D7), U1.3 (D7), U2.3 (D7)
/PA1_0: J1.1, U1.4 (PA0)
/PA1_1: J1.3, U1.5 (PA1)
/PA1_2: J1.5, U1.6 (PA2)
/PA1_3: J1.7, U1.7 (PA3)
/PA1_4: J1.9, U1.8 (PA4)
/PA1_5: J1.11, U1.9 (PA5)
/PA1_6: J1.13, U1.10 (PA6)
/PA1_7: J1.15, U1.11 (PA7)
/PA2_0: J1.2, U2.4 (PA0)
/PA2_1: J1.4, U2.5 (PA1)
/PA2_2: J1.6, U2.6 (PA2)
/PA2_3: J1.8, U2.7 (PA3)
/PA2_4: J1.10, U2.8 (PA4)
/PA2_5: J1.12, U2.9 (PA5)
/PA2_6: J1.14, U2.10 (PA6)
/PA2_7: J1.16, U2.11 (PA7)
/PB1_0: J4.1, U1.17 (PB0)
/PB1_1: J4.3, U1.18 (PB1)
/PB1_2: J4.5, U1.19 (PB2)
/PB1_3: J4.7, U1.20 (PB3)
/PB1_4: J4.9, U1.21 (PB4)
/PB1_5: J4.11, U1.22 (PB5)
/PB1_6: J4.13, U1.23 (PB6)
/PB1_7: J4.15, U1.24 (PB7)
/PB2_0: J4.2, U2.17 (PB0)
/PB2_1: J4.4, U2.18 (PB1)
/PB2_2: J4.6, U2.19 (PB2)
/PB2_3: J4.8, U2.20 (PB3)
/PB2_4: J4.10, U2.21 (PB4)
/PB2_5: J4.12, U2.22 (PB5)
/PB2_6: J4.14, U2.23 (PB6)
/PB2_7: J4.16, U2.24 (PB7)
/PC1_0: J5.1, U1.30 (PC0)
/PC1_1: J5.3, U1.31 (PC1)
/PC1_2: J5.5, U1.32 (TIN/PC2)
/PC1_3: J5.7, J8.1, J8.3, J8.5, J8.7, U1.33 (PC3/TOUT)
/PC1_4: J5.9, U1.34 (DMAREQ/PC4)
/PC1_5: J5.11, J9.1, J9.3, J9.5, J9.7, U1.35 (PC5/PIRQ)
/PC1_6: J5.13, U1.36 (PC6/PIACK)
/PC1_7: J5.15, U1.37 (PC7/TIACK)
/PC2_0: J5.2, U2.30 (PC0)
/PC2_1: J5.4, U2.31 (PC1)
/PC2_2: J5.6, U2.32 (TIN/PC2)
/PC2_3: J5.8, J10.1, J10.3, J10.5, J10.7, U2.33 (PC3/TOUT)
/PC2_4: J5.10, U2.34 (DMAREQ/PC4)
/PC2_5: J5.12, J11.1, J11.3, J11.5, J11.7, U2.35 (PC5/PIRQ)
/PC2_6: J5.14, U2.36 (PC6/PIACK)
/PC2_7: J5.16, U2.37 (PC7/TIACK)
/PITA_CLK: J2.2, U1.40 (CLK)
/PITB_CLK: J6.2, U2.40 (CLK)
/R/~W: J3.44 (R/~W), U1.43 (R/W), U2.43 (R/W)
/~AS: J3.41 (~AS), U4.1 (G)
/~DTACK: J3.62 (~BUSACK), U1.42 (DTACK), U2.42 (DTACK)
/~INT1: J3.37 (USR1), J8.2, J9.2, J10.2, J11.2
/~INT2: J3.38 (USR2), J8.4, J9.4, J10.4, J11.4
/~INT5: J3.39 (USR3), J8.6, J9.6, J10.6, J11.6
/~INT6: J3.40 (USR4), J8.8, J9.8, J10.8, J11.8
/~PITA_CS: J12.1, J12.2, J12.3, J12.4, J12.5, J12.6, J12.7, J12.8, U1.41 (CS)
/~PITB_CS: J13.1, J13.2, J13.3, J13.4, J13.5, J13.6, J13.7, J13.8, U2.41 (CS)
/~RESET: J3.20 (~RESET), U1.39 (RESET), U2.39 (RESET)
GND: C1.2, C2.2, C3.1, C4.1, J3.17 (GND), J3.57 (GND), J14.1, J14.2, J14.3, J14.4, J14.5, J14.6, U1.38 (GND), U2.38 (GND), U3.8 (GND), U4.5 (R1), U4.9 (R3), U4.10 (GND), U4.12 (R4), U4.14 (R5), U4.16 (R6)
unnamed: J7.1, U3.15 (O0)
unnamed: J7.2, U3.14 (O1)
unnamed: J7.3, U3.13 (O2)
unnamed: J7.4, U3.12 (O3)
unnamed: J7.5, U3.11 (O4)
unnamed: J7.6, U3.10 (O5)
unnamed: J7.7, U3.9 (O6)
unnamed: J7.8, U3.7 (O7)
unnamed: U3.4 (E1), U4.19 (P=R)

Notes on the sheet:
PI/T #2 PORT INT
PI/T #1 PORT INT
PI/T #2
CS0: D08000 CS1: D08800 CS2: D09000 CS3: D09800 CS4: D0A000 CS5: D0A800 CS6: D0B000 CS7: D0B800
PI/T #1 TIMER INT
PI/T #2 TIMER INT
PI/T #1


Board: 4 copper layers, 101.6 x 53.3 mm, 23 parts (0 on the bottom side), 99 nets.

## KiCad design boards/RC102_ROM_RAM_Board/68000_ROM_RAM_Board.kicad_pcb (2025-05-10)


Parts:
C1, C3, C4, C5, C6, C8, C9: 100n; C_Disc_D5.0mm_W2.5mm_P2.50mm
J2: RCBus_80PIN_68000; RCBus_80p_Medium
U1: 74LS125; DIP-14_W7.62mm
U3, U6: W27C512; DIP-28_W15.24mm
U4, U5: AS6C4008-55PCN; DIP-32_W15.24mm
U8: 74LS138; DIP-16_W7.62mm
U9: 74LS139; DIP-16_W7.62mm

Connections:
+5V: C1.1, C3.1, C4.2, C5.2, C6.1, C8.1, C9.2, J2.18 (+5V), J2.58 (+5V), U1.14 (VCC), U3.28 (VCC), U4.32 (VCC), U5.32 (VCC), U6.28 (VCC), U8.6 (E3), U8.16 (VCC), U9.16 (VCC)
/A1: J2.16 (A0), U3.10 (A0), U4.12 (A0), U5.12 (A0), U6.10 (A0)
/A2: J2.15 (A1), U3.9 (A1), U4.11 (A1), U5.11 (A1), U6.9 (A1)
/A3: J2.14 (A2), U3.8 (A2), U4.10 (A2), U5.10 (A2), U6.8 (A2)
/A4: J2.13 (A3), U3.7 (A3), U4.9 (A3), U5.9 (A3), U6.7 (A3)
/A5: J2.12 (A4), U3.6 (A4), U4.8 (A4), U5.8 (A4), U6.6 (A4)
/A6: J2.11 (A5), U3.5 (A5), U4.7 (A5), U5.7 (A5), U6.5 (A5)
/A7: J2.10 (A6), U3.4 (A6), U4.6 (A6), U5.6 (A6), U6.4 (A6)
/A8: J2.9 (A7), U3.3 (A7), U4.5 (A7), U5.5 (A7), U6.3 (A7)
/A9: J2.8 (A8), U3.25 (A8), U4.27 (A8), U5.27 (A8), U6.25 (A8)
/A10: J2.7 (A9), U3.24 (A9), U4.26 (A9), U5.26 (A9), U6.24 (A9)
/A11: J2.6 (A10), U3.21 (A10), U4.23 (A10), U5.23 (A10), U6.21 (A10)
/A12: J2.5 (A11), U3.23 (A11), U4.25 (A11), U5.25 (A11), U6.23 (A11)
/A13: J2.4 (A12), U3.2 (A12), U4.4 (A12), U5.4 (A12), U6.2 (A12)
/A14: J2.3 (A13), U3.26 (A13), U4.28 (A13), U5.28 (A13), U6.26 (A13)
/A15: J2.2 (A14), U3.27 (A14), U4.3 (A14), U5.3 (A14), U6.27 (A14)
/A16: J2.1 (A15), U3.1 (A15), U4.31 (A15), U5.31 (A15), U6.1 (A15)
/A17: J2.56 (A16), U4.2 (A16), U5.2 (A16)
/A18: J2.55 (A17), U4.30 (A17), U5.30 (A17)
/A19: J2.54 (A18), U4.1 (A18), U5.1 (A18)
/A20: J2.53 (A19), U8.1 (A0)
/A21: J2.52 (A20), U8.2 (A1)
/A22: J2.51 (A21), U8.3 (A2)
/A23: J2.50 (A22), U8.5 (E2)
/D0: J2.27 (D0), U4.13 (DQ0), U6.11 (D0)
/D1: J2.28 (D1), U4.14 (DQ1), U6.12 (D1)
/D2: J2.29 (D2), U4.15 (DQ2), U6.13 (D2)
/D3: J2.30 (D3), U4.17 (DQ3), U6.15 (D3)
/D4: J2.31 (D4), U4.18 (DQ4), U6.16 (D4)
/D5: J2.32 (D5), U4.19 (DQ5), U6.17 (D5)
/D6: J2.33 (D6), U4.20 (DQ6), U6.18 (D6)
/D7: J2.34 (D7), U4.21 (DQ7), U6.19 (D7)
/D8: J2.67 (D8), U3.11 (D0), U5.13 (DQ0)
/D9: J2.68 (D9), U3.12 (D1), U5.14 (DQ1)
/D10: J2.69 (D10), U3.13 (D2), U5.15 (DQ2)
/D11: J2.70 (D11), U3.15 (D3), U5.17 (DQ3)
/D12: J2.71 (D12), U3.16 (D4), U5.18 (DQ4)
/D13: J2.72 (D13), U3.17 (D5), U5.19 (DQ5)
/D14: J2.73 (D14), U3.18 (D6), U5.20 (DQ6)
/D15: J2.74 (D15), U3.19 (D7), U5.21 (DQ7)
/R/~W: J2.44 (R/~W), U9.2 (A0), U9.14 (A0)
/~AS: J2.41 (~AS), U8.4 (E1), U9.3 (A1), U9.13 (A1)
/~DTACK: J2.62 (~BUSACK), U1.3, U1.6
/~LDS: J2.43 (~LDS), U9.15 (E)
/~RAM_CS: U1.1, U4.22 (CE#), U5.22 (CE#), U8.14 (O1)
/~RD_HI: U3.22 (~OE), U5.24 (OE#), U9.5 (O1)
/~RD_LO: U4.24 (OE#), U6.22 (~OE), U9.11 (O1)
/~ROM_CS: U1.4, U3.20 (~CE), U6.20 (~CE), U8.15 (O0)
/~UDS: J2.42 (~UDS), U9.1 (E)
/~WR_HI: U5.29 (WE#), U9.4 (O0)
/~WR_LO: U4.29 (WE#), U9.12 (O0)
GND: C1.2, C3.2, C4.1, C5.1, C6.2, C8.2, C9.1, J2.17 (GND), J2.57 (GND), U1.2, U1.5, U1.7 (GND), U1.9, U1.10, U1.12, U1.13, U3.14 (GND), U4.16 (VSS), U5.16 (VSS), U6.14 (GND), U8.8 (GND), U9.8 (GND)

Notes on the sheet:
LS138 DECODES 1M BLOCKS ROM: 0x000000..0x0FFFFF RAM: 0x100000..0x1FFFFF


Board: 4 copper layers, 101.6 x 53.3 mm, 15 parts (0 on the bottom side), 52 nets.

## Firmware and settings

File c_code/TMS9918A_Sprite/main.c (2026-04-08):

#include <stdint.h>
#include <textio.h>
#include "tms9918a.h"

const uint8_t vsyncDiv = 6;		// number of interrupts per animation frame
const uint8_t spriteCount = 8;	// number of frames in animation

uint8_t vsyncCount = 0;
uint8_t currSprite = 0;
uint8_t xDelta = 1;
uint8_t yDelta = 1;

// planet sprites from TI VDP Programmer's guide
const uint8_t spritePatterns[] = {
        // Sprite world0 pattern 1
        0x007, 0x01C, 0x038, 0x070, 0x078, 0x05C, 0x00E, 0x00F,
        0x00F, 0x01F, 0x07F, 0x063, 0x073, 0x03D, 0x01F, 0x007,
        0x0E0, 0x0F8, 0x07C, 0x066, 0x0F2, 0x0BE, 0x0DC, 0x0FC,
        0x0F8, 0x0A0, 0x0C0, 0x0C0, 0x0E2, 0x0F4, 0x0F8, 0x0E0,

        // Sprite world0 pattern 2
        0x000, 0x003, 0x007, 0x00F, 0x007, 0x0A3, 0x0F1, 0x0F0,
        0x0F0, 0x0E0, 0x080, 0x01C, 0x00C, 0x002, 0x000, 0x000,
        0x000, 0x000, 0x080, 0x098, 0x00C, 0x041, 0x023, 0x003,
        0x007, 0x05F, 0x03F, 0x03E, 0x01C, 0x008, 0x000, 0x000,

        // Sprite world1 pattern 1
        0x003, 0x01F, 0x03E, 0x07C, 0x07E, 0x097, 0x003, 0x003,
        0x003, 0x007, 0x01F, 0x078, 0x07C, 0x03F, 0x01F, 0x007,
        0x0E0, 0x038, 0x01C, 0x018, 0x03C, 0x02F, 0x0B7, 0x0FF,
        0x0FE, 0x0E8, 0x0F0, 0x0F0, 0x0F8, 0x07C, 0x0F8, 0x0E0,

        // Sprite world1 pattern 2
        0x000, 0x000, 0x001, 0x003, 0x001, 0x068, 0x0FC, 0x0FC,
        0x0FC, 0x0F8, 0x0E0, 0x007, 0x003, 0x000, 0x000, 0x000,
        0x000, 0x0C0, 0x0E0, 0x0E6, 0x0C2, 0x0D0, 0x048, 0x000,
        0x001, 0x017, 0x00F, 0x00E, 0x006, 0x080, 0x000, 0x000,

        // Sprite world2 pattern 1
        0x007, 0x01F, 0x03F, 0x07F, 0x03F, 0x0E5, 0x0C0, 0x0C0,
        0x080, 0x001, 0x007, 0x01E, 0x03F, 0x03F, 0x01F, 0x007,
        0x0E0, 0x0C8, 0x084, 0x006, 0x08E, 0x0CB, 0x0ED, 0x0FF,
        0x0FF, 0x0FA, 0x0FC, 0x03C, 0x03E, 0x0DC, 0x0F8, 0x0E0,

        // Sprite world2 pattern 2
        0x000, 0x000, 0x000, 0x000, 0x040, 0x01A, 0x03F, 0x03F,
        0x07F, 0x0FE, 0x0F8, 0x061, 0x040, 0x000, 0x000, 0x000,
        0x000, 0x030, 0x078, 0x0F8, 0x070, 0x034, 0x012, 0x000,
        0x000, 0x005, 0x003, 0x0C2, 0x0C0, 0x020, 0x000, 0x000,

        // Sprite world3 pattern 1
        0x007, 0x01F, 0x03F, 0x01F, 0x04F, 0x0F9, 0x070, 0x0F0,
        0x0E0, 0x080, 0x001, 0x007, 0x00F, 0x01F, 0x01F, 0x007,
        0x0E0, 0x0F0, 0x0E0, 0x0C2, 0x0E2, 0x072, 0x03B, 0x03F,
        0x03F, 0x07E, 0x0FF, 0x08E, 0x0CE, 0x0F4, 0x0F8, 0x0E0,

        // Sprite world3 pattern 2
        0x000, 0x000, 0x000, 0x060, 0x030, 0x006, 0x08F, 0x00F,
        0x01F, 0x07F, 0x0FE, 0x078, 0x070, 0x020, 0x000, 0x000,
        0x000, 0x008, 0x01C, 0x03C, 0x01C, 0x08D, 0x0C4, 0x0C0,
        0x0C0, 0x081, 0x000, 0x070, 0x030, 0x008, 0x000, 0x000,

        // Sprite world4 pattern 1
        0x007, 0x01F, 0x03F, 0x067, 0x073, 0x0BE, 0x0DC, 0x0FC,
        0x0F8, 0x0A0, 0x0C0, 0x041, 0x063, 0x037, 0x01F, 0x007,
        0x0E0, 0x0F8, 0x0F8, 0x0F0, 0x0F8, 0x05C, 0x00E, 0x00F,
        0x00F, 0x01F, 0x07F, 0x0E2, 0x0F2, 0x0FC, 0x0F8, 0x0E0,

        // Sprite world4 pattern 2
        0x000, 0x000, 0x000, 0x018, 0x00C, 0x041, 0x023, 0x003,
        0x007, 0x05F, 0x03F, 0x03E, 0x01C, 0x008, 0x000, 0x000,
        0x000, 0x000, 0x004, 0x00E, 0x006, 0x0A3, 0x0F1, 0x0F0,
        0x0F0, 0x0E0, 0x080, 0x01C, 0x00C, 0x000, 0x000, 0x000,

        // Sprite world5 pattern 1
        0x007, 0x01F, 0x01F, 0x019, 0x03C, 0x02F, 0x0B7, 0x0FF,
        0x0FE, 0x0E8, 0x0F0, 0x070, 0x078, 0x03D, 0x01F, 0x007,
        0x0E0, 0x0F8, 0x0FC, 0x0FC, 0x0FE, 0x097, 0x003, 0x003,
        0x003, 0x007, 0x01F, 0x078, 0x0FC, 0x0FC, 0x0F8, 0x0E0,

        // Sprite world5 pattern 2
        0x000, 0x000, 0x020, 0x066, 0x043, 0x0D0, 0x048, 0x000,
        0x001, 0x017, 0x00F, 0x00F, 0x007, 0x002, 0x000, 0x000,
        0x000, 0x000, 0x000, 0x002, 0x000, 0x068, 0x0FC, 0x0FC,
        0x0FC, 0x0F8, 0x0E0, 0x086, 0x002, 0x000, 0x000, 0x000,

        // Sprite world6 pattern 1
        0x007, 0x00F, 0x007, 0x006, 0x00F, 0x0CB, 0x0ED, 0x0FF,
        0x0FF, 0x0FA, 0x0FC, 0x03C, 0x03E, 0x01F, 0x01F, 0x007,
        0x0E0, 0x0F8, 0x0FC, 0x07E, 0x03E, 0x0E5, 0x0C0, 0x0C0,
        0x080, 0x001, 0x007, 0x01E, 0x03E, 0x07C, 0x0F8, 0x0E0,

        // Sprite world6 pattern 2
        0x000, 0x010, 0x038, 0x079, 0x070, 0x034, 0x012, 0x000,
        0x000, 0x005, 0x003, 0x043, 0x041, 0x020, 0x000, 0x000,
        0x000, 0x000, 0x000, 0x080, 0x0C0, 0x01A, 0x03F, 0x03F,
        0x07F, 0x0FE, 0x0F8, 0x0E0, 0x0C0, 0x080, 0x000, 0x000,

        // Sprite world7 pattern 1
        0x007, 0x013, 0x021, 0x041, 0x063, 0x072, 0x03B, 0x03F,
        0x03F, 0x07E, 0x0FF, 0x00F, 0x04F, 0x037, 0x01F, 0x007,
        0x0E0, 0x0F8, 0x0FC, 0x09E, 0x0CE, 0x0F9, 0x070, 0x0F0,
        0x0E0, 0x080, 0x001, 0x006, 0x08E, 0x0DC, 0x0F8, 0x0E0,

        // Sprite world7 pattern 2
        0x000, 0x00C, 0x01E, 0x03E, 0x01C, 0x08D, 0x0C4, 0x0C0,
        0x0C0, 0x081, 0x000, 0x070, 0x030, 0x008, 0x000, 0x000,
        0x000, 0x000, 0x000, 0x060, 0x030, 0x006, 0x08F, 0x00F,
        0x01F, 0x07F, 0x0FE, 0x0F8, 0x070, 0x020, 0x000, 0x000
};

// simple zero based list of sprite attribute names
enum spriteDefs { sprite1Y, sprite1X, sprite1Name, sprite1Colour,
                  sprite2Y, sprite2X, sprite2Name, sprite2Colour
				};
uint8_t spriteAttributes[] = {
		// sprite1Y, sprite1X, sprite1Name, sprite1Colour
		88, 0, 0, TmsDarkBlue,

		// sprite2Y, sprite2X, sprite2Name, sprite2Colour
		88, 0, 4, TmsLightGreen
};
		
int main(void)
{
uint8_t result;

	putStr("Simple demo of the TMSEMU (TMS9918A) video board.\n");
	putStr("Sprite demo based on the Z80 code by JB Langston.\n");

	vsyncCount = vsyncDiv;
	currSprite = 0;
	
	result = tmsProbe();
	
	if (result !=0 ) {
		tmsBitmap();

		tmsSpriteConfig( TmsSprite32 );
		tmsLoadSprites( spritePatterns, sizeof( spritePatterns ) );

		while( 1 ) {
			// wait for vsync
			while (( tmsRegIn() & 0x80 ) == 0 ) {
			};
		
			// update the X coordinate
			spriteAttributes[ sprite1X ] = spriteAttributes[ sprite1X ] + xDelta;
			spriteAttributes[ sprite2X ] = spriteAttributes[ sprite2X ] + xDelta;
			
			// change the X direction if the sprite reaches the edge
			if ( spriteAttributes[ sprite1X ] >= 240 ) xDelta = -xDelta;
			if ( spriteAttributes[ sprite1X ] <= 0 ) xDelta = -xDelta;

			// update the Y coordinate
			spriteAttributes[ sprite1Y ] = spriteAttributes[ sprite1Y ] + yDelta;
			spriteAttributes[ sprite2Y ] = spriteAttributes[ sprite2Y ] + yDelta;
			
			// change the Y direction if the sprite reaches the edge
			if ( spriteAttributes[ sprite1Y ] >= 176 ) yDelta = -yDelta;
			if ( spriteAttributes[ sprite1Y ] <= 0 ) yDelta = -yDelta;
			
			tmsUpdateSprites( spriteAttributes, sizeof( spriteAttributes ) );
		}
	}
	else
	{
		putStr("\nCound not detect TMSEMU board at address 0x");
		putByte( TMS9918A_ADDR );
		putStr("\n\n");
	}
    return 0;
}

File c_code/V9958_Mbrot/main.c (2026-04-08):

#include <stdint.h>
#include <stdlib.h>
#include <textio.h>

#include "v9958.h"

float fabs(float v);

RGB palette[16] = {
    {0, 0, 0}, {1, 0, 0}, {2, 0, 0},  {3, 0, 0},  {4, 0, 0},  {5, 0, 0},  {6, 0, 0},  {7, 0, 0},
    {8, 0, 0}, {9, 0, 0}, {10, 0, 0}, {11, 0, 0}, {12, 0, 0}, {13, 0, 0}, {14, 0, 0}, {15, 0, 0}
};

#define ITERATION_MAX 16
#define CX_MIN        -2.5
#define CX_MAX        1.5
#define CY_MIN        -2.0
#define CY_MAX        2.0
#define IX_MAX        512

#define PIXEL_WIDTH ((CX_MAX - CX_MIN) / IX_MAX)

#define ESCAPE_RADIUS 2
/* bail-out value , radius of circle ;  */
#define ER2 (ESCAPE_RADIUS * ESCAPE_RADIUS)

float Cx;
float Cy;
float Zx;
float Zy;
float Zx2;
float Zy2;

/* screen ( integer) coordinate */
uint16_t iX, iY;
uint8_t  iteration;
float fv;

int main()
{
    putStr("Testpit: V9958 Mandelbrot Demo for gcc\r\n");

    const uint8_t mode = PAL;
    const uint8_t lines = 212;

    putStr("setMode6\r\n");
    setMode6(lines, mode);

    putStr("setPalette\r\n");
    setPalette(palette);

    putStr("clearScreenBank0\r\n");
    clearScreenBank0(4);

    putStr("plot mandelbrot\r\n");

    const float pixelHeight = ((CY_MAX - CY_MIN) / lines);

    for (iY = 0; iY < lines; iY++) {
        Cy = CY_MIN + iY * pixelHeight;

        if (fabs(Cy) < pixelHeight / 2)
            Cy = 0.0;

        for (iX = 0; iX < IX_MAX; iX++) {
            Cx = CX_MIN + iX * PIXEL_WIDTH;

            Zx  = 0.0;
            Zy  = 0.0;
            Zx2 = Zx * Zx;
            Zy2 = Zy * Zy;

            for (iteration = 0; iteration < ITERATION_MAX && ((Zx2 + Zy2) < ER2); iteration++) {
            Zy  = 2 * Zx * Zy + Cy;
            Zx  = Zx2 - Zy2 + Cx;
            Zx2 = Zx * Zx;
            Zy2 = Zy * Zy;
            };

            pointSet(iX, iY, iteration, CMD_LOGIC_IMP);
        }
    }
    return 0;
}

float fabs(float fval)
{
	asm(
		"andi.l #0x7FFFFFFF,%0"
		: "+r" (fval)     /* param %0 called fval in C code */
		: /* no inputs */
		: /* no clobbers */
		);

	return fval;
}

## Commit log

2025-02-16 added board images
2025-02-24 Added PCB files etc
    [68000_CPU_Board_PLCC.kicad_pcb, 68000_CPU_Board_PLCC.kicad_sch, 68000_ROM_RAM_Board.kicad_pcb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]
2025-03-05 Added new boards
    [68000_MFP_Board.kicad_pcb, 68000_MFP_Board.kicad_sch, 68000_PIO_Board.kicad_pcb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]
2025-03-08 added monitor and code samples
2025-05-10 Update to v2 board set
    Lots of updates to reflect the new v2 boards that use the full RCBus 80 pins as well as slight modifications to the various test programs to reflect the new IO and MEM space addresses.
    [68000_CPU_Board.kicad_pcb, 68000_CPU_Board.kicad_sch, 68000_CPU_Board_PLCC.kicad_pcb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]
2025-05-24 software
    renamed the assembler code directory and added in the c code directory
2025-08-15 more 68302 details
    [68302_CPU_Board.kicad_pcb, 68302_CPU_Board.kicad_sch]
2025-08-21 add new rom/ram board
    [68000_ROM_RAM_Board_2.kicad_pcb, 68000_ROM_RAM_Board_2.kicad_sch]
2025-08-22 Updated pinout list and boards readme
2025-09-13 update to PIO board and 68302 board notes
2025-10-26 Added BOMs for each board
    [bom.csv]
2025-10-29 Updated board readme files.
2025-11-01 Updated BOMs and added gerber files for all boards.
    [68000_CPU_Board_BOM.csv, 68000_MPF_BOARD_BOM.csv, 68000_PIO_BOARD_BOM.csv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]
2025-11-01 68000 clock
    Added details of the 68000 board clock frequencies used.
2025-11-06 Added V9958A demonstrations
    Based around Dean Netherton's HDMI for RC board.
2025-11-19 Corrections to RCBus pinout
    Corrected nDTACK pin.
    Deleted nINT3.
    Moved nINT2 to pin 38.
2025-12-08 Updated some board readme's
2025-12-08 Updated board readme's
2025-12-09 updated rom/ram board #2 schematic notes
    [68000_ROM_RAM_Board_2.kicad_sch]
2025-12-10 updated 68000 board readme
2025-12-14 Annotated schematic with notes on errors found so far.
2025-12-14 added SPI master board
2025-12-14 Updated schematics
2025-12-16 updated readme's and added LBE board
2025-12-26 Extended baud rate details for the Philips devices.
2025-12-26 Added LBE board details etc
2025-12-27 Change method of monitor variable definitions
    With some assemblers (e.g. Vasm) the previous method of using "ORG xxxx" and
    <var> ds.b <N>
    forces the assembler to fill the blank between the end of the code and the ORG
    statement
    Changing the definitions to be just "EQU"s doesn't force the aseembler to
    fill in the blank.
2025-12-27 Remove spurious spaces after commas
    Some assemblers (e.g. vasm) don't like a space after a comma in mnemonics
    This commit removes spaces after commas in mnemonics only (i.e. not in comments!)
2025-12-27 Changed PC-relative assembly syntax to modern Motorola style.
    The code was written in an older style of:
    lea bemsg1(PC),a0
    to:
    lea (bemsg1,PC),A0
    which is accepted by more modern assemblers (e.g. vasm)
2025-12-27 Add conditional assembly for Vasm
    Easy68k and Vasm use different methods to ensure alignment. Easy68k uses:
    ORG (*+1)&-2
    Whereas Vasm uses:
    align 2
2026-01-07 Added note re 68681 X2 pin
2026-01-17 Added SIO & MATHS board
2026-01-18 updated readme with more board designs
2026-01-18 Updated address ranges for new boards
2026-01-25 Updated LBE board details
    [68000_LBE_Board.kicad_pcb, 68000_LBE_Board.kicad_sch, 68000_LBE_Board_BOM.csv]
2026-03-07 updated SPI board details
2026-03-14 notes re series 2 boards
2026-03-14 Added series 2 boards and images
2026-03-14 added more board details
2026-03-28 Reorganise and rename boards
    [68000_CPU_Board.kicad_pcb, 68000_CPU_Board.kicad_sch, 68000_CPU_Board_BOM.csv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]
2026-04-08 added SC704 I2C scanner
2026-07-20 added RC204 board
2026-08-11 Added new memory boards
2026-08-13 updated board renderings
2026-08-17 added text re interrupts
2026-08-22 updated RC208
    [RC208-68000_BOOTROM_RAM_2.kicad_pcb, RC208-68000_BOOTROM_RAM_2.kicad_sch, RC208-68000_BOOTROM_RAM_2_BOM.csv]
2026-08-22 updated boards
2026-08-26 Updated RC200 backplane
    [RC200-Dev_Backplane.csv, RC200-Dev_Backplane.kicad_pcb, RC200-Dev_Backplane.kicad_sch]
2026-08-28 updated RC201
    [RC201-68000_CPU_2.kicad_pcb, RC201-68000_CPU_2.kicad_sch, RC201-68000_CPU_2_BOM.csv]
2026-08-31 updated RC202
    [RC201-68000_CPU_2_BOM.csv, RC202-68000_SIO_1.kicad_pcb, RC202-68000_SIO_1.kicad_sch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]
2026-09-01 Added note re socketed oscillators
2026-09-01 updated RC203
    [RC203-68000_PIO_1.kicad_pcb, RC203-68000_PIO_1.kicad_sch, RC203-68000_PIO_1_BOM.csv]
2026-09-12 Updated RC107
    [68000_ROM_RAM_Board_2.kicad_pcb, 68000_ROM_RAM_Board_2_BOM.csv, RC107-68000_ROM_RAM_1.kicad_pcb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]
2026-09-13 updated some board readme files
2026-09-30 Added note re error with 68302 interrupts
2026-10-10 Added more detail on interrupt issues
2026-11-12 Added RC215 68EC030 board
2026-11-12 Updated RC215 board image
